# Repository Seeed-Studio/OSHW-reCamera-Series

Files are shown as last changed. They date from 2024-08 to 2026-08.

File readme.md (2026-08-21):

# Seeed Studio reCamera Hardware

English | [简体中文](README-CN.md)

reCamera Pro

This repository is the hardware documentation and design-resource hub for the
Seeed Studio reCamera product matrix:

- **reCamera 2002 / 2002w** (SG2002), a modular platform.
- **reCamera Pro** (RV1126B), a higher-performance integrated platform.

reCamera 2002 / 2002w and reCamera Pro are concurrently sold product families
for different application and performance requirements. This repository does
not describe them as replacement generations.

## Product matrix

| | reCamera 2002 / 2002w | reCamera Pro |
| --- | --- | --- |
| Processor | Sophgo SG2002 | Rockchip RV1126B |
| CPU | Dual C906 RISC-V cores | Quad-core Cortex-A53 at 1.2GHz |
| AI acceleration | 1 TOPS INT8 | 3 TOPS NPU |
| Memory | 256MB | 2GB / 4GB LPDDR4 |
| Standard camera | OV5647, 5MP | SC850SL, 8MP, 4K at 30fps |
| Hardware model | Interchangeable core, sensor, and base boards | Integrated camera with expansion interfaces |
| Documentation | [reCamera 2002 hardware](hardware/recamera-2002/) | [reCamera Pro hardware](hardware/recamera-pro/) |

### reCamera 2002 / 2002w

| Standard reCamera 2002 | reCamera 2002 HQ PoE | reCamera Gimbal 2002w |
| --- | --- | --- |
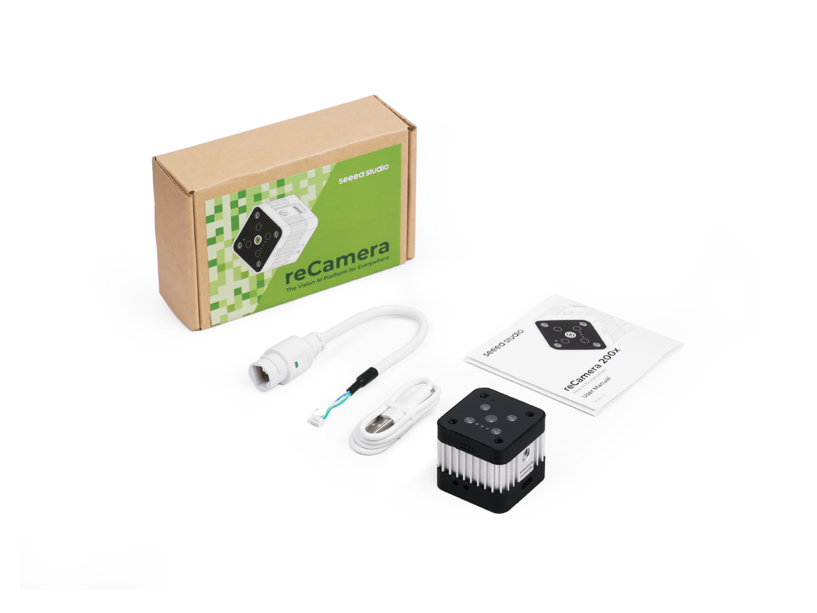
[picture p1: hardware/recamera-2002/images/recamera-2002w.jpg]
reCamera 2002w (https://www.seeedstudio.com/reCamera-2002-64GB-p-6252.html)
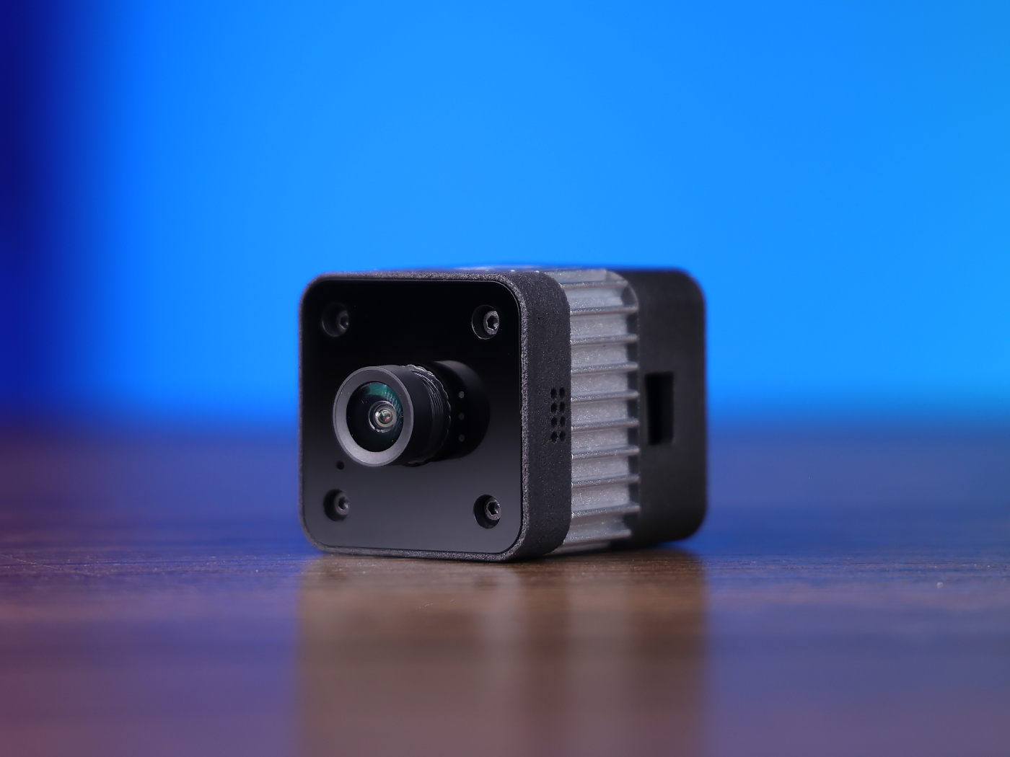
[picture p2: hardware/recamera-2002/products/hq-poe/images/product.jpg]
reCamera 2002 HQ PoE (https://www.seeedstudio.com/reCamera-2002-HQ-PoE-64GB-p-6557.html)
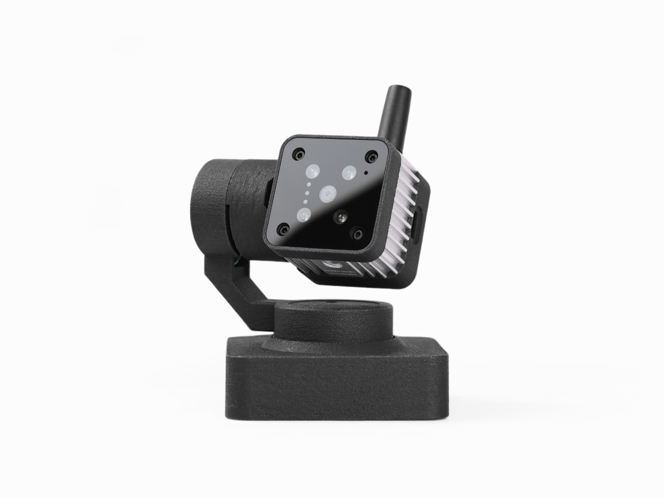
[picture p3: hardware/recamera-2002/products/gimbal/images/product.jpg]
reCamera Gimbal 2002w (https://www.seeedstudio.com/reCamera-Gimbal-2002w-64GB-p-6403.html)
|  |  |  |
| Fixed camera; B101 base | GC2053 sensor; Ethernet and PoE | Two-axis brushless gimbal; B401 CAN base |

The repository contains editable KiCad sources, schematic PDFs, mechanical
files, and revision notes for the C1 core, S-series sensor boards, B-series base
boards, and Gimbal mechanical/power hardware. See the
[reCamera 2002 / 2002w product index](hardware/recamera-2002/products/).

### reCamera Pro

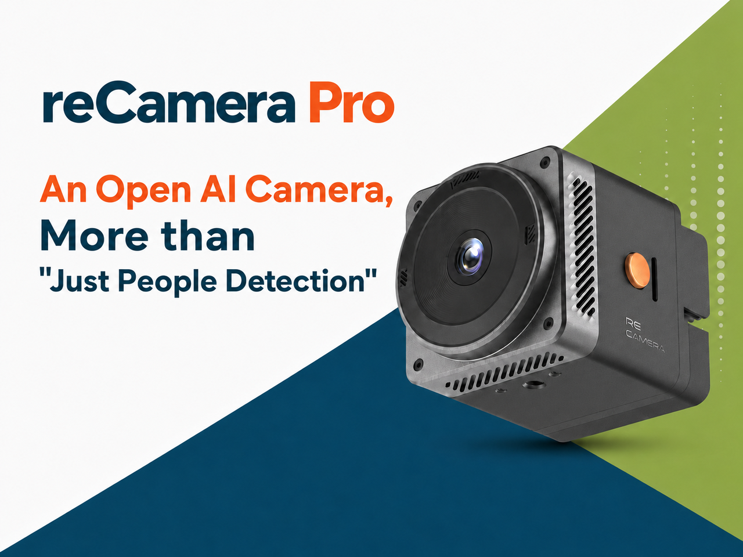
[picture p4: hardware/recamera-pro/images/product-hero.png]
reCamera Pro (https://www.seeedstudio.com/reCamera-Pro-2GB.html)


[Buy reCamera Pro 2GB from Seeed Studio](https://www.seeedstudio.com/reCamera-Pro-2GB.html)

The repository currently provides an official-specification snapshot, polished
storefront product images, and technical interface images for reCamera Pro. Editable Pro PCB and
mechanical source files should be added only when an approved hardware release
is available.

## Repository layout

```text
.
|-- hardware/
|   |-- recamera-2002/       # reCamera 2002 family board and mechanical sources
|   `-- recamera-pro/        # reCamera Pro family specifications and images
|-- docs/                    # Official sources and maintenance policy
|-- .github/workflows/       # Repository administration
|-- CONTRIBUTING.md
`-- LICENSE
```

## Scope

This is a **pure hardware repository**. 
If you need to access software-related repositories, please visit the official website.
[reCamera document](https://wiki.seeedstudio.com/recamera/)Obtain these resources from the Seeed Studio software repository.

Gimbal and HQ PoE are product forms within the reCamera 2002 family. Their
product-specific hardware is documented under `hardware/recamera-2002/products/`
and linked to shared boards.

## Source of truth

Hardware summaries are reviewed against official Seeed Studio product and Wiki
pages. See [docs/OFFICIAL_SOURCES.md](docs/OFFICIAL_SOURCES.md) for the source
list and review date. A currently shipped product page takes precedence over a
repository snapshot when specifications or available configurations change.

Contributions must follow [CONTRIBUTING.md](CONTRIBUTING.md). Unless a file says
otherwise, repository content is provided under the [Apache License 2.0](LICENSE).

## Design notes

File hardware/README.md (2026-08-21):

# Hardware index

English | [简体中文](README-CN.md)

| Product family | Processor | Product forms | Repository resources |
| --- | --- | --- | --- |
| reCamera 2002 / 2002w | SG2002 | Standard camera, HQ PoE, Gimbal | [Products, board sources, schematics, and mechanical files](recamera-2002/) |
| reCamera Pro | RV1126B | 2GB / 4GB configurations | [Specifications and official hardware images](recamera-pro/) |

The reCamera 2002 family is organized first by purchasable product form, then by
shared interchangeable core, sensor, and base boards. reCamera Pro is documented
as an integrated product because approved editable Pro design sources are not
currently stored in this repository. Both families remain part of the current
product matrix.

Repository files are revision snapshots, not an automatic statement that a
module is currently sold. Always distinguish standard shipped hardware,
optional modules, and reference/prototype designs.

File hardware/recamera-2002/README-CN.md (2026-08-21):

# reCamera 2002 / 2002w 硬件

[English](README.md) | 简体中文

reCamera 2002 / 2002w 平台由三层可互换模块组成：C1 核心板、S 系列传感器板与
B 系列底板。

reCamera 2002w

## 当前在售产品形态

| 产品形态 | 主要硬件差异 | 产品说明 |
| --- | --- | --- |
| reCamera 2002 / 2002w | 使用 S101 与 B101 的固定式摄像头 | [标准版](products/#standard-recamera-2002--2002w) |
| reCamera 2002 HQ PoE | S401 GC2053、M12 镜头、B301 以太网/PoE 底板 | [HQ PoE](products/hq-poe/) |
| reCamera Gimbal 2002w | S101、B401 CAN 底板、双轴无刷云台与电源板 | [Gimbal](products/gimbal/) |

三者都是基于 SG2002 的 reCamera 2002 系列产品形态。

## 标准固定式摄像头配置

| 产品 | 核心板 | eMMC | 无线 | 传感器 | 底板 |
| --- | --- | ---: | --- | --- | --- |
| reCamera 2002 8GB | C1-2002 | 8GB | 无 | S101 OV5647 | B101 |
| reCamera 2002 64GB | C1-2002 | 64GB | 无 | S101 OV5647 | B101 |
| reCamera 2002w 8GB | C1-2002w | 8GB | Wi-Fi / 蓝牙 | S101 OV5647 | B101 |
| reCamera 2002w 64GB | C1-2002w | 64GB | Wi-Fi / 蓝牙 | S101 OV5647 | B101 |

## 硬件资料

| 层级 | 板卡 | 状态 | 目录 |
| --- | --- | --- | --- |
| 核心板 | C1-2002 / C1-2002w | 标准出货核心板 | [core/c1-2002](core/c1-2002/) |
| 传感器 | S101 OV5647 | 标准出货传感器 | [sensors/s101-ov5647](sensors/s101-ov5647/) |
| 传感器 | S201 IMX335 | 可选/已记录模块；请确认供货 | 本仓库暂无设计文件 |
| 传感器 | S301 SC130GS | 可选/已记录模块；请确认供货 | 本仓库暂无设计文件 |
| 传感器 | S401 GC2053 | 用于 HQ/PoE 变体 | [sensors/s401-gc2053](sensors/s401-gc2053/) |
| 底板 | B101 | 标准出货底板 | [base/b101-default](base/b101-default/) |
| 底板 | B201 垂直 USB-C | 参考/原型设计 | [base/b201-vertical-usb-c](base/b201-vertical-usb-c/) |
| 底板 | B301 PoE | 参考设计；需与商用版本核对 | [base/b301-poe](base/b301-poe/) |
| 底板 | B401 CAN | 云台 CAN 底板；源文件沿用早期 B4 命名 | [base/b401-can](base/b401-can/) |

SG2002 驱动层传感器快照见 [SENSOR_COMPATIBILITY-CN.md](SENSOR_COMPATIBILITY-CN.md)。
存在驱动不代表一定有可购买模块，也不代表一定与 reCamera 板对板接口电气兼容。

## 文件约定

- `PCB/`：可编辑 KiCad 源文件和已批准的原始压缩包。
- `3D_Printed_Case/`：STEP、STL 或 3MF 机械文件。
- `static/` 或 `statics/`：板卡示意图和原理图 PDF。

用于维修或制造前，请先确认实物板卡版本。

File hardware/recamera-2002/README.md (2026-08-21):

# reCamera 2002 / 2002w hardware

English | [简体中文](README-CN.md)

The reCamera 2002 / 2002w platform is built from three interchangeable layers:
a C1 core board, an S-series sensor board, and a B-series base board.

reCamera 2002w

## Currently sold product forms

| Product form | Key hardware difference | Product documentation |
| --- | --- | --- |
| reCamera 2002 / 2002w | Fixed camera using S101 and B101 | [Standard camera](products/#standard-recamera-2002--2002w) |
| reCamera 2002 HQ PoE | S401 GC2053, M12 lens, B301 Ethernet/PoE base | [HQ PoE](products/hq-poe/) |
| reCamera Gimbal 2002w | S101, B401 CAN base, two-axis brushless gimbal and power board | [Gimbal](products/gimbal/) |

These are three product forms within the same SG2002-based reCamera 2002 family.

## Standard fixed-camera configurations

| Product | Core | eMMC | Wireless | Sensor | Base |
| --- | --- | ---: | --- | --- | --- |
| reCamera 2002 8GB | C1-2002 | 8GB | No | S101 OV5647 | B101 |
| reCamera 2002 64GB | C1-2002 | 64GB | No | S101 OV5647 | B101 |
| reCamera 2002w 8GB | C1-2002w | 8GB | Wi-Fi / Bluetooth | S101 OV5647 | B101 |
| reCamera 2002w 64GB | C1-2002w | 64GB | Wi-Fi / Bluetooth | S101 OV5647 | B101 |

## Hardware resources

| Layer | Board | Status | Directory |
| --- | --- | --- | --- |
| Core | C1-2002 / C1-2002w | Standard shipped core | [core/c1-2002](core/c1-2002/) |
| Sensor | S101 OV5647 | Standard shipped sensor | [sensors/s101-ov5647](sensors/s101-ov5647/) |
| Sensor | S201 IMX335 | Optional/documented module; verify availability | Design files not present in this repository |
| Sensor | S301 SC130GS | Optional/documented module; verify availability | Design files not present in this repository |
| Sensor | S401 GC2053 | Used by HQ/PoE variants | [sensors/s401-gc2053](sensors/s401-gc2053/) |
| Base | B101 | Standard shipped base | [base/b101-default](base/b101-default/) |
| Base | B201 vertical USB-C | Reference/prototype design | [base/b201-vertical-usb-c](base/b201-vertical-usb-c/) |
| Base | B301 PoE | Reference design; verify against commercial revision | [base/b301-poe](base/b301-poe/) |
| Base | B401 CAN | Gimbal CAN base; source files use earlier B4 naming | [base/b401-can](base/b401-can/) |

See [SENSOR_COMPATIBILITY.md](SENSOR_COMPATIBILITY.md) for the SG2002
driver-level sensor snapshot. Driver presence does not guarantee a purchasable
module or electrical compatibility with the reCamera connector.

## File conventions

- `PCB/`: editable KiCad sources and approved original archives.
- `3D_Printed_Case/`: STEP, STL, or 3MF mechanical files.
- `static/` or `statics/`: board diagrams and schematic PDFs.

Confirm the physical board revision before using these files for repair or
manufacture.

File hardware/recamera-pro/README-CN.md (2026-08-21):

# reCamera Pro 硬件

[English](README.md) | 简体中文

reCamera Pro (https://www.seeedstudio.com/reCamera-Pro-2GB.html)

[前往 Seeed Studio 购买 reCamera Pro 2GB](https://www.seeedstudio.com/reCamera-Pro-2GB.html)

reCamera Pro 是基于 Rockchip RV1126B 的高性能集成式产品系列。它不同于并行在售的
reCamera 2002 三板模块化结构，将传感、音频、网络、供电和扩展接口集成在同一摄像头平台中。

## 官方硬件规格

以 Seeed Studio Wiki 为依据，核对日期：**2026-08-11**。

| 项目 | 规格 |
| --- | --- |
| 处理器 | Rockchip RV1126B |
| CPU | 1.2GHz 四核 Arm Cortex-A53 |
| NPU | 3 TOPS，支持 INT8/INT16 混合计算 |
| 内存 | 2GB / 4GB LPDDR4 |
| 存储 | 16GB eMMC；microSD 卡槽，最大 512GB |
| 摄像头 | 8MP SC850SL，最高 4K@30fps |
| IMU | ICM-42670-P 六轴加速度计和陀螺仪 |
| 音频输入 | 驻极体麦克风 ×2 |
| 音频输出 | 8Ω 扬声器，额定功率 1W |
| 网络 | 千兆以太网、双频 Wi-Fi、蓝牙 |
| 供电 | 12–24V DC（5525 圆孔接口）、PoE、7.4V 锂电池充放电管理 |
| USB | 全功能 USB Type-C（OTG） |
| 扩展 | 调试 UART、CAN ×2、GPIO ×2、22-pin MIPI DSI |

## 硬件视图

### 商品展示

以下高清图片来自 Seeed Studio 官方商城，用于展示产品、随附硬件和外形尺寸。

| 产品与配件 | 外形尺寸 |
| --- | --- |
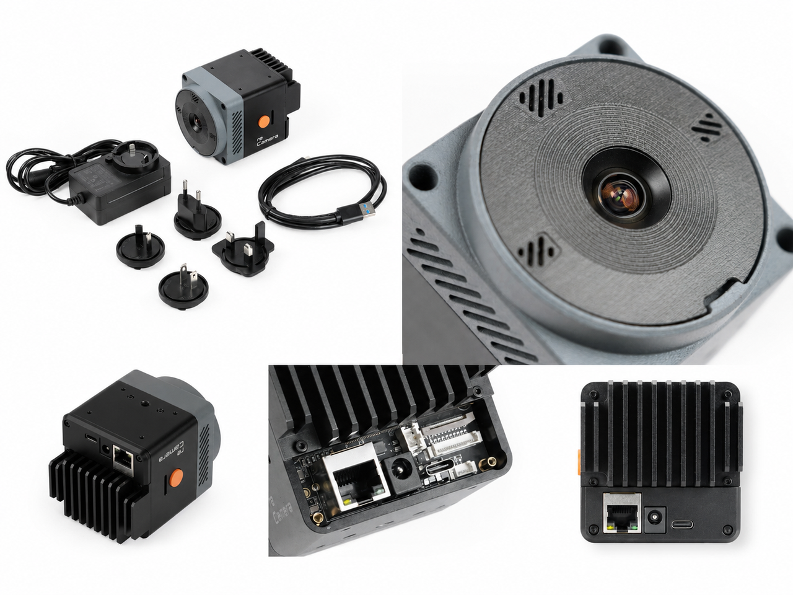
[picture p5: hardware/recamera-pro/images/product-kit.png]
reCamera Pro 产品与配件
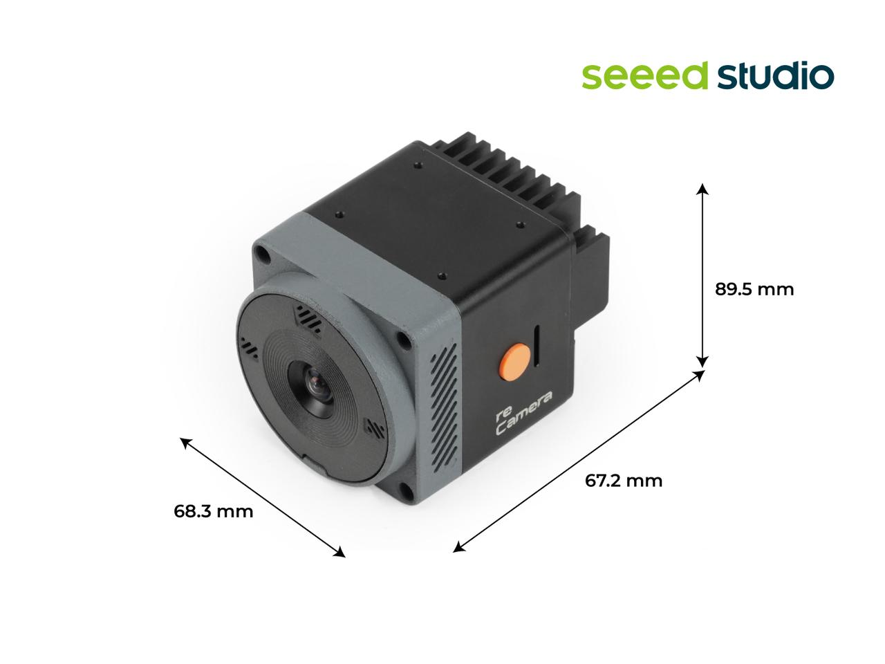
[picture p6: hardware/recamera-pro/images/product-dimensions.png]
reCamera Pro 外形尺寸
|  |  |

### 接口总览

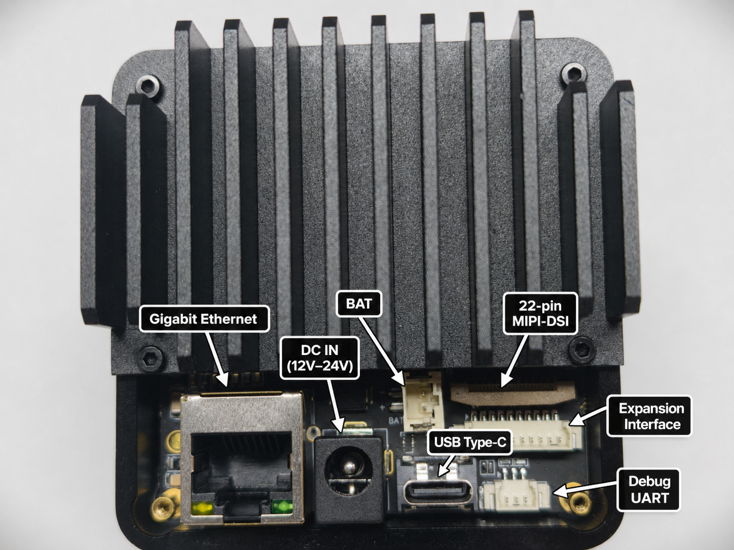
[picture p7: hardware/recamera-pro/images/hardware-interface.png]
reCamera Pro 硬件接口


### 正面与侧面

| 正面 | 侧面 |
| --- | --- |
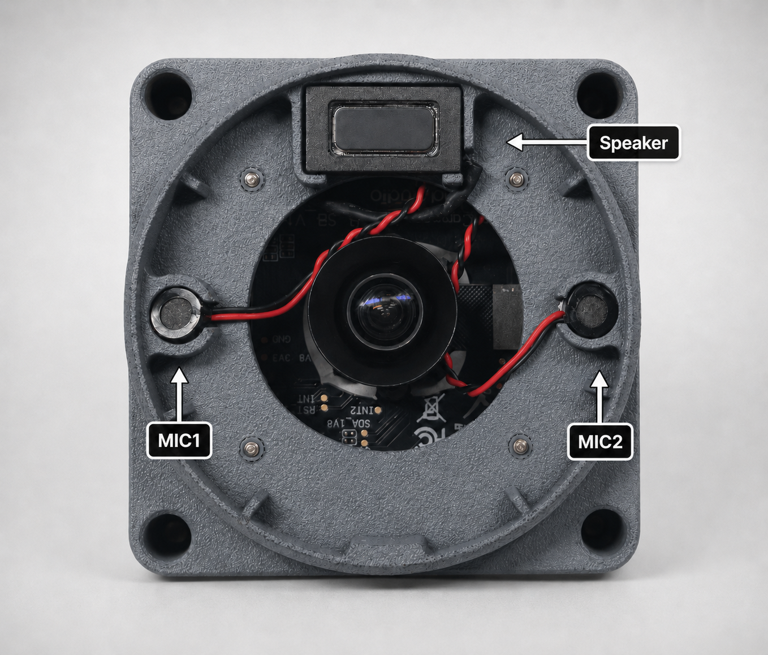
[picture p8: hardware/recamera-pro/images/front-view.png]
正面视图
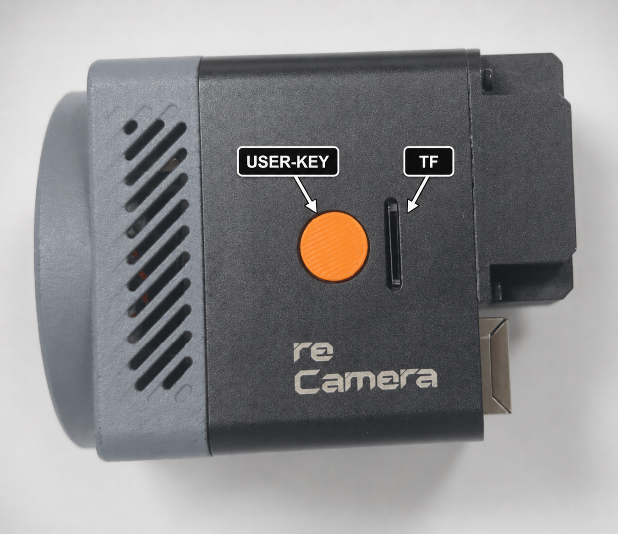
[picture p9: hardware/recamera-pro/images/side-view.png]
侧面视图
|  |  |

### 扩展接口与调试 UART

| 扩展接口 | 调试 UART |
| --- | --- |
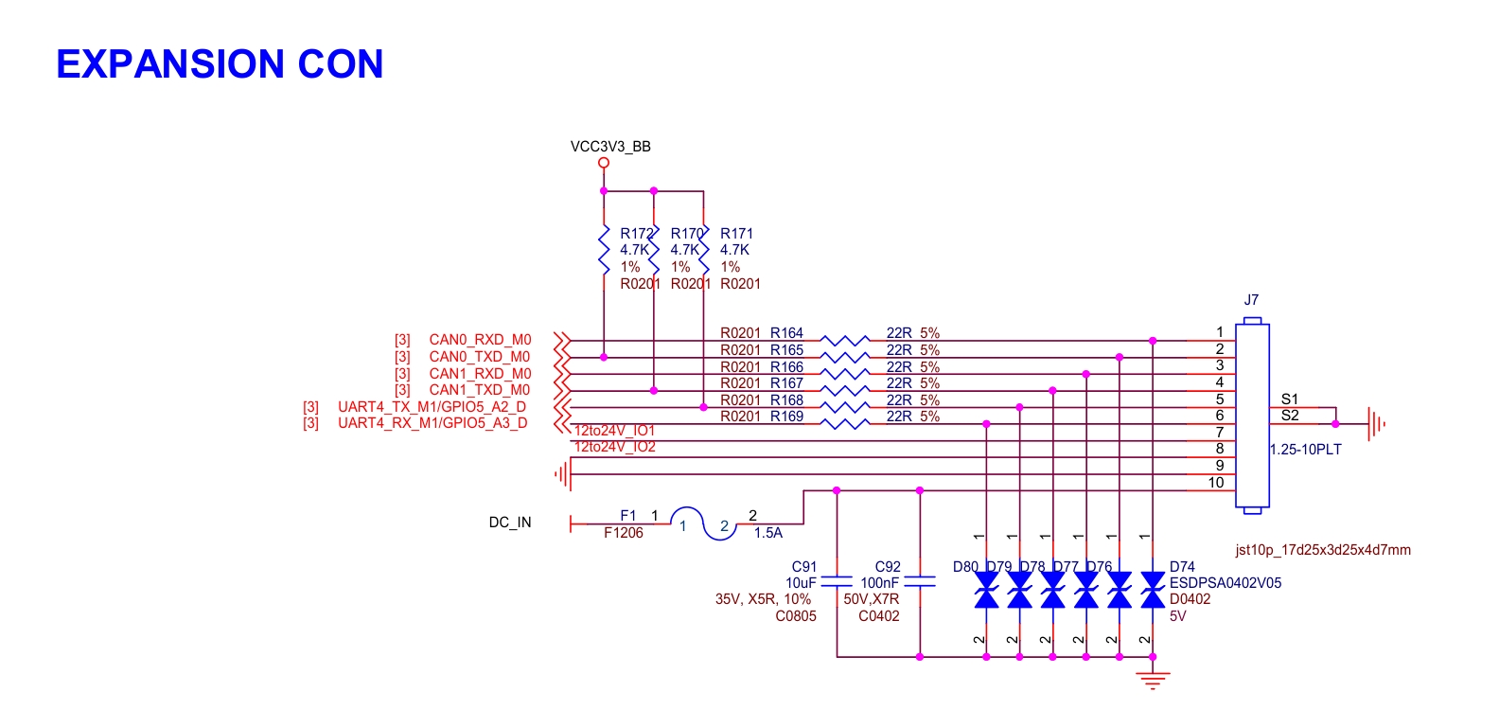
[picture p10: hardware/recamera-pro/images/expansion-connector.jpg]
扩展接口
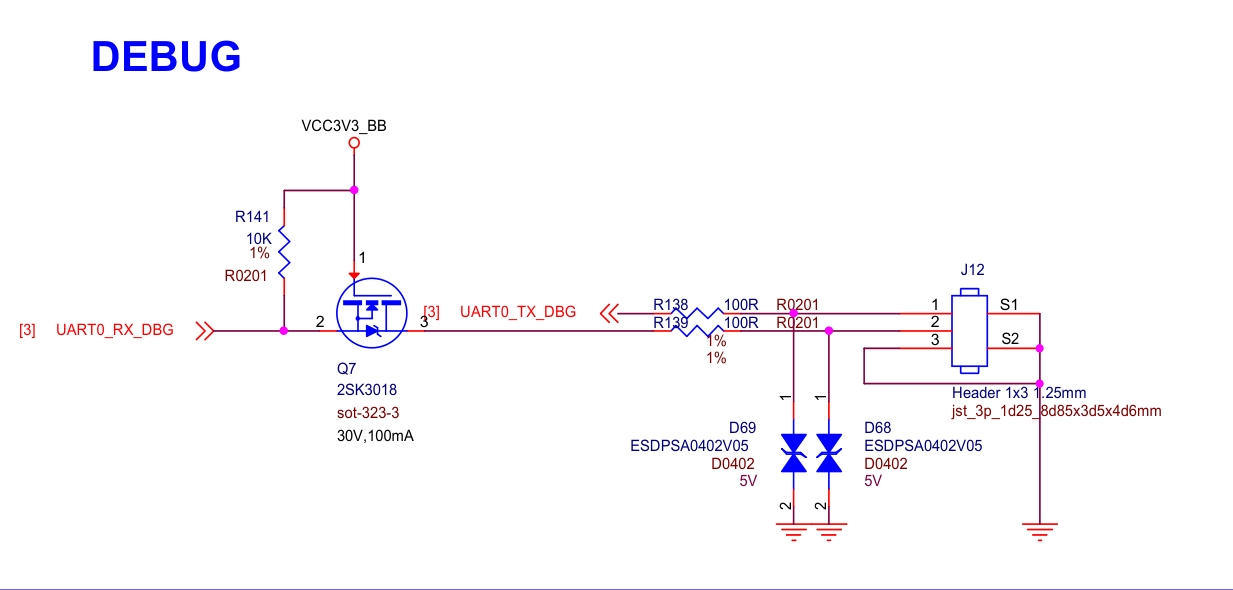
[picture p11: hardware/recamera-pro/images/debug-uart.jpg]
调试 UART
|  |  |

## 设计源文件状态

本目录当前不声称提供 reCamera Pro 可编辑 PCB、BOM 或机械源文件集。宣传图来自
Seeed Studio 官方商城，接口图来自官方文档，规格表是带日期的快照。只有在正确硬件版本获批公开后，
才应添加制造源文件。

## 官方参考

- [商品与购买页面](https://www.seeedstudio.com/reCamera-Pro-2GB.html)
- [中文硬件规格](https://wiki.seeedstudio.com/cn/recamera_pro_hardware_specifications/)
- [英文硬件规格](https://wiki.seeedstudio.com/recamera_pro_hardware_specifications/)
- [快速入门与实物连接](https://wiki.seeedstudio.com/cn/recamera_pro_getting_started/)

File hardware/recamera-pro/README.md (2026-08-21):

# reCamera Pro hardware

English | [简体中文](README-CN.md)

reCamera Pro (https://www.seeedstudio.com/reCamera-Pro-2GB.html)

[Buy reCamera Pro 2GB from Seeed Studio](https://www.seeedstudio.com/reCamera-Pro-2GB.html)

reCamera Pro is the higher-performance integrated product family based on the
Rockchip RV1126B. Unlike the three-board modular architecture of the concurrently
sold reCamera 2002 family, Pro integrates sensing, audio, networking, power, and
expansion interfaces in one camera platform.

## Official hardware specifications

Reviewed against the Seeed Studio Wiki on **2026-08-11**.

| Item | Specification |
| --- | --- |
| Processor | Rockchip RV1126B |
| CPU | Quad-core Arm Cortex-A53 at 1.2GHz |
| NPU | 3 TOPS; mixed INT8/INT16 computation |
| Memory | 2GB / 4GB LPDDR4 |
| Storage | 16GB eMMC; microSD slot up to 512GB |
| Camera | 8MP SC850SL, up to 4K at 30fps |
| IMU | ICM-42670-P six-axis accelerometer and gyroscope |
| Audio input | Two electret microphones |
| Audio output | 8Ω speaker, rated 1W |
| Networking | Gigabit Ethernet, dual-band Wi-Fi, Bluetooth |
| Power | 12–24V DC through 5525 barrel jack; PoE; 7.4V lithium-battery charge/discharge management |
| USB | Full-function USB Type-C (OTG) |
| Expansion | Debug UART, CAN ×2, GPIO ×2, 22-pin MIPI DSI |

## Hardware views

### Product gallery

The following high-resolution images come from the official Seeed Studio
storefront and present the product, supplied hardware, and physical dimensions.

| Product and accessories | Physical dimensions |
| --- | --- |
| reCamera Pro product and accessories | reCamera Pro physical dimensions |

### Interface overview

reCamera Pro hardware interface

### Front and side

| Front | Side |
| --- | --- |
| Front view | Side view |

### Expansion connector and debug UART

| Expansion connector | Debug UART |
| --- | --- |
| Expansion connector | Debug UART |

## Design-source status

This directory does not currently claim to provide the editable PCB, BOM, or
mechanical source set for reCamera Pro. Promotional images come from the official
storefront, interface images come from official documentation, and the table is
a dated specification snapshot. Add
manufacturing sources only after the correct hardware revision is approved for
public release.

## Official references

- [Product and ordering page](https://www.seeedstudio.com/reCamera-Pro-2GB.html)
- [Hardware specifications](https://wiki.seeedstudio.com/recamera_pro_hardware_specifications/)
- [Quick start and physical connection](https://wiki.seeedstudio.com/recamera_pro_getting_started/)
- [Chinese hardware specifications](https://wiki.seeedstudio.com/cn/recamera_pro_hardware_specifications/)

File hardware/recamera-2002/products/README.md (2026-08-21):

# reCamera 2002 / 2002w products

English | [简体中文](README-CN.md)

The SG2002-based reCamera 2002 / 2002w family is sold in three main hardware
forms. They share the same modular platform but combine different sensor, base,
and motion hardware.

| Product | Camera hardware | Connectivity / motion | Hardware resources |
| --- | --- | --- | --- |
| Standard reCamera 2002 / 2002w | S101 OV5647, 5MP | B101; optional Wi-Fi/Bluetooth through the 2002w core | [C1 core](../core/c1-2002/), [S101](../sensors/s101-ov5647/), [B101](../base/b101-default/) |
| reCamera 2002 HQ PoE | S401 GC2053, 2MP, M12 lens | B301, 100Mbps Ethernet and 802.3af PoE Mode A | [Product page](hq-poe/) |
| reCamera Gimbal 2002w | S101 OV5647, 5MP | B401 CAN, 360° yaw and 180° pitch | [Product page](gimbal/) |

## Standard reCamera 2002 / 2002w

Standard reCamera 2002 (https://www.seeedstudio.com/reCamera-2002-64GB-p-6252.html)

The standard fixed-camera form uses the three-board C1 + S101 + B101 stack.
The `2002w` core adds dual-band Wi-Fi and Bluetooth; storage configurations vary
by the currently selected storefront SKU.

[View the official product page](https://www.seeedstudio.com/reCamera-2002-64GB-p-6252.html)

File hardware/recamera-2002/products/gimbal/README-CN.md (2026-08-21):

# reCamera Gimbal 2002w 硬件

[English](README.md) | 简体中文

reCamera Gimbal 2002w (https://www.seeedstudio.com/reCamera-Gimbal-2002w-64GB-p-6403.html)

Gimbal 是 reCamera 2002w 系列的运动云台形态。双无刷电机提供 360° 水平
旋转与 180° 俯仰，B401 底板通过 CAN 连接摄像头与电机系统。

| 项目 | 硬件 |
| --- | --- |
| 摄像头堆叠 | [C1-2002w](../../core/c1-2002/) + [S101 OV5647](../../sensors/s101-ov5647/) |
| 云台底板 | [B401 CAN](../../base/b401-can/) |
| 电机接口 | CAN；官方规格列出最高 1Mbps |
| 运动范围 | 水平 360°、俯仰 180° |
| 供电 | 12V DC 经专用电源板连接 XT30 |
| 机械源文件 | [STEP/3MF 文件](mechanical/) |
| 电源板源文件 | [KiCad 与原理图](power-board/PCB/) |

这里只保留硬件设计资料。电机工具、可执行文件、固件、Node-RED 流程和控制
示例不属于本仓库范围。

- [购买 reCamera Gimbal 2002w](https://www.seeedstudio.com/reCamera-Gimbal-2002w-64GB-p-6403.html)
- [官方硬件 Wiki](https://wiki.seeedstudio.com/recamera_gimbal_hardware_and_specs/)

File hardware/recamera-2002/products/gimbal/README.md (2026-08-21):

# reCamera Gimbal 2002w hardware

English | [简体中文](README-CN.md)

reCamera Gimbal 2002w (https://www.seeedstudio.com/reCamera-Gimbal-2002w-64GB-p-6403.html)

Gimbal is the motion-enabled form of the reCamera 2002w family. Its
two brushless motors provide 360° yaw and 180° pitch, while the B401 base board
uses CAN to connect the camera and motor system.

| Item | Hardware |
| --- | --- |
| Camera stack | [C1-2002w](../../core/c1-2002/) + [S101 OV5647](../../sensors/s101-ov5647/) |
| Gimbal base | [B401 CAN](../../base/b401-can/) |
| Motor interface | CAN; official specification lists up to 1Mbps |
| Motion | 360° yaw, 180° pitch |
| Power | 12V DC jack to XT30 through the dedicated power board |
| Mechanical source | [STEP/3MF files](mechanical/) |
| Power-board source | [KiCad and schematic files](power-board/PCB/) |

Only hardware design resources are stored here. Motor utilities, binaries,
firmware, Node-RED flows, and control examples remain outside this repository's
scope.

- [Buy reCamera Gimbal 2002w](https://www.seeedstudio.com/reCamera-Gimbal-2002w-64GB-p-6403.html)
- [Official hardware Wiki](https://wiki.seeedstudio.com/recamera_gimbal_hardware_and_specs/)

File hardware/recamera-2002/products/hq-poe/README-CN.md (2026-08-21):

# reCamera 2002 HQ PoE 硬件

[English](README.md) | 简体中文

reCamera 2002 HQ PoE (https://www.seeedstudio.com/reCamera-2002-HQ-PoE-64GB-p-6557.html)

HQ PoE 是 reCamera 2002 系列面向网络部署的固定式产品，由 SG2002
核心板、S401 GC2053 传感器板与 B301 PoE 底板组成。

| 项目 | 硬件 |
| --- | --- |
| SoC / 内存 | SG2002，256MB |
| 传感器 | GC2053，1/2.9 英寸 CMOS，1920×1080@30fps |
| 镜头 | 可更换 M12；官方默认视场角约 90° |
| 底板 | [B301 PoE](../../base/b301-poe/) |
| 传感器板 | [S401 GC2053](../../sensors/s401-gc2053/) |
| 网络/供电 | 100Mbps 以太网；802.3af PoE Mode A |
| 扩展 | 六针接口提供 UART、调试接口和三个 GPIO |

商城当前列出 64GB 配置，实际供货与所选存储容量应以商品页为准。

- [购买 reCamera 2002 HQ PoE](https://www.seeedstudio.com/reCamera-2002-HQ-PoE-64GB-p-6557.html)
- [官方中文硬件 Wiki](https://wiki.seeedstudio.com/cn/reCamera_hq_poe_hardware_and_specs/)

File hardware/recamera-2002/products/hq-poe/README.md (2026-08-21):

# reCamera 2002 HQ PoE hardware

English | [简体中文](README-CN.md)

reCamera 2002 HQ PoE (https://www.seeedstudio.com/reCamera-2002-HQ-PoE-64GB-p-6557.html)

HQ PoE is the network-oriented fixed-camera form of the reCamera 2002 family.
It combines the SG2002 core with the S401 GC2053 sensor
board and B301 PoE base.

| Item | Hardware |
| --- | --- |
| SoC / memory | SG2002, 256MB |
| Sensor | GC2053, 1/2.9-inch CMOS, 1920×1080 at 30fps |
| Lens | Replaceable M12; official default FOV approximately 90° |
| Base | [B301 PoE](../../base/b301-poe/) |
| Sensor board | [S401 GC2053](../../sensors/s401-gc2053/) |
| Network / power | 100Mbps Ethernet; 802.3af PoE Mode A |
| Expansion | UART, debug, and three GPIOs through the six-pin connector |

The commercial product page currently lists a 64GB configuration. Availability
and selected storage should always be verified on the storefront.

- [Buy reCamera 2002 HQ PoE](https://www.seeedstudio.com/reCamera-2002-HQ-PoE-64GB-p-6557.html)
- [Official hardware Wiki](https://wiki.seeedstudio.com/recamera_hq_poe_hardware_and_specs/)

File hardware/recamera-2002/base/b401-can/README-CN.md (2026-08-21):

# B401 CAN 底板

[English](README.md) | 简体中文

B401 是 reCamera Gimbal 2002w 使用的 CAN 底板。恢复的设计文件仍沿用历史上的
`B4` 和 `B101_B4_Gyro` 文件名；这些是早期设计命名，当前 Seeed 文档将商用板称为 B401。

| 目录 | 内容 |
| --- | --- |
| `PCB/B4_v0.1/` | 早期 KiCad 设计快照 |
| `PCB/B4_v0.2/` | 后续 KiCad 设计与原理图 PDF |
| `3D_Printed_Case/` | STEP/STL 底板外壳文件 |
| `static/` | 板卡与原理图预览 |

用于制造前，请将 PCB 版本与实际产品核对。

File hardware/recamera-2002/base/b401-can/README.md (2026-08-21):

# B401 CAN base board

English | [简体中文](README-CN.md)

B401 is the CAN-enabled base board used by reCamera Gimbal 2002w. The restored
design files retain historical `B4` and `B101_B4_Gyro` filenames; these names
refer to earlier design naming, while current Seeed documentation calls the
commercial board B401.

| Directory | Contents |
| --- | --- |
| `PCB/B4_v0.1/` | Early KiCad design snapshot |
| `PCB/B4_v0.2/` | Later KiCad design and schematic PDF |
| `3D_Printed_Case/` | STEP/STL base enclosure files |
| `static/` | Board and schematic previews |

Verify the PCB revision against the physical product before manufacturing.

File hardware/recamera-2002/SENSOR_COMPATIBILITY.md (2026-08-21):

# SG2002 sensor-driver compatibility

This is a driver-level snapshot for the C1 SG2002 core board. It does not mean
that every sensor is electrically compatible with the reCamera board-to-board
connector or available as a finished Seeed module.

Last repository review: **2026-08-04**

| Vendor group | Supported driver identifiers |
| --- | --- |
| GalaxyCore / IMGDS / Nextchip / PICO / SOI | `gcore_gc2053`, `gcore_gc2053_slave`, `gcore_gc2053_1L`, `gcore_gc2083`, `gcore_gc2093`, `gcore_gc2093_slave`, `gcore_gc4653`, `gcore_gc4653_slave`, `gcore_gc2145`, `gcore_gc4023`, `gcore_gc1054`, `imgds_mis2008`, `nextchip_n5`, `nextchip_n6`, `pico_384`, `pico_640`, `soi_f23`, `soi_f35`, `soi_f35_slave`, `soi_h65`, `soi_f37p`, `soi_k06`, `soi_q03`, `soi_q03p` |
| OmniVision / Pixelplus / Techpoint / Lontium | `ov_os02d10`, `ov_os02d10_slave`, `ov_os02k10_slave`, `ov_os04c10`, `ov_os04c10_slave`, `ov_os08a20`, `ov_os08a20_slave`, `ov_os04a10`, `ov_ov4689`, `ov_ov5647`, `ov_ov7251`, `pixelplus_pr2020`, `pixelplus_pr2100`, `techpoint_tp2850`, `techpoint_tp2863`, `techpoint_tp2825`, `lontium_lt6911` |
| Sony | `sony_imx290_2L`, `sony_imx307`, `sony_imx307_slave`, `sony_imx307_2L`, `sony_imx307_sublvds`, `sony_imx327`, `sony_imx327_slave`, `sony_imx327_2L`, `sony_imx327_sublvds`, `sony_imx334`, `sony_imx335`, `sony_imx347`, `sony_imx385`, `sony_imx327_fpga` |
| SmartSens | `sms_sc035hgs`, `sms_sc200ai`, `sms_sc401ai`, `sms_sc850sl`, `sms_sc3335`, `sms_sc3335_slave`, `sms_sc3336`, `sms_sc4210`, `sms_sc8238`, `sms_sc5336_2L`, `sms_sc501ai_2L`, `sms_sc301iot`, `sms_sc500ai`, `sms_sc035gs`, `sms_sc035gs_1L`, `sms_sc1346_1L`, `sms_sc1346_1L_slave`, `sms_sc2331_1L`, `sms_sc2335`, `sms_sc2336`, `sms_sc2336p`, `sms_sc4336`, `sms_sc4336p`, `sms_sc3332` |

The standard Basic product ships with the **S101 OV5647** module. This
repository also contains module-level material for GC2053.
For the current kernel configuration and driver source, consult the maintained
[reCamera-OS repository](https://github.com/Seeed-Studio/reCamera-OS).

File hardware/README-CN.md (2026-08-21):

# 硬件索引

[English](README.md) | 简体中文

| 产品系列 | 处理器 | 产品形态 | 仓库资料 |
| --- | --- | --- | --- |
| reCamera 2002 / 2002w | SG2002 | 标准版、HQ PoE、Gimbal | [产品形态、板卡源文件、原理图和机械文件](recamera-2002/) |
| reCamera Pro | RV1126B | 2GB / 4GB 配置 | [硬件规格和官方图片](recamera-pro/) |

reCamera 2002 系列先按可购买的产品形态展示，再按共用的可互换核心板、传感器板和
底板组织。reCamera Pro 按集成式产品记录，因为本仓库当前没有已批准可公开的 Pro
可编辑设计源文件。两个系列都是当前产品矩阵的一部分。

仓库中的文件是特定版本快照，不等于模块当前一定在售。必须明确区分标准出货硬件、
可选模块和参考/原型设计。

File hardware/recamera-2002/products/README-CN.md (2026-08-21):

# reCamera 2002 / 2002w 产品形态

[English](README.md) | 简体中文

基于 SG2002 的 reCamera 2002 / 2002w 系列目前以三种主要硬件形态销售。
它们共用模块化平台，但采用不同的传感器、底板和运动机构。

| 产品 | 摄像头硬件 | 连接/运动 | 硬件资料 |
| --- | --- | --- | --- |
| 标准版 reCamera 2002 / 2002w | S101 OV5647，5MP | B101；2002w 核心板提供 Wi-Fi/蓝牙 | [C1 核心板](../core/c1-2002/)、[S101](../sensors/s101-ov5647/)、[B101](../base/b101-default/) |
| reCamera 2002 HQ PoE | S401 GC2053，2MP，M12 镜头 | B301，100Mbps 以太网与 802.3af PoE Mode A | [产品说明](hq-poe/) |
| reCamera Gimbal 2002w | S101 OV5647，5MP | B401 CAN，360° 水平旋转、180° 俯仰 | [产品说明](gimbal/) |

## 标准版 reCamera 2002 / 2002w

标准版 reCamera 2002 (https://www.seeedstudio.com/reCamera-2002-64GB-p-6252.html)

标准固定式产品采用 C1 + S101 + B101 三板堆叠结构。`2002w` 核心板增加
双频 Wi-Fi 与蓝牙；存储容量以商城当前选择的 SKU 为准。

[查看官方商品页](https://www.seeedstudio.com/reCamera-2002-64GB-p-6252.html)

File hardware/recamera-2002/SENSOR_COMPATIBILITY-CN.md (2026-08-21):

# SG2002 传感器驱动兼容性

[English](SENSOR_COMPATIBILITY.md) | 简体中文

本页是 C1 SG2002 核心板的驱动层兼容性快照。列出驱动并不表示对应传感器与 reCamera 板对板连接器在电气上兼容，也不表示 Seeed 已提供相应成品模块。

仓库最后核对日期：**2026-08-04**

| 厂商类别 | 支持的驱动标识符 |
| --- | --- |
| GalaxyCore / IMGDS / Nextchip / PICO / SOI | `gcore_gc2053`、`gcore_gc2053_slave`、`gcore_gc2053_1L`、`gcore_gc2083`、`gcore_gc2093`、`gcore_gc2093_slave`、`gcore_gc4653`、`gcore_gc4653_slave`、`gcore_gc2145`、`gcore_gc4023`、`gcore_gc1054`、`imgds_mis2008`、`nextchip_n5`、`nextchip_n6`、`pico_384`、`pico_640`、`soi_f23`、`soi_f35`、`soi_f35_slave`、`soi_h65`、`soi_f37p`、`soi_k06`、`soi_q03`、`soi_q03p` |
| OmniVision / Pixelplus / Techpoint / Lontium | `ov_os02d10`、`ov_os02d10_slave`、`ov_os02k10_slave`、`ov_os04c10`、`ov_os04c10_slave`、`ov_os08a20`、`ov_os08a20_slave`、`ov_os04a10`、`ov_ov4689`、`ov_ov5647`、`ov_ov7251`、`pixelplus_pr2020`、`pixelplus_pr2100`、`techpoint_tp2850`、`techpoint_tp2863`、`techpoint_tp2825`、`lontium_lt6911` |
| Sony | `sony_imx290_2L`、`sony_imx307`、`sony_imx307_slave`、`sony_imx307_2L`、`sony_imx307_sublvds`、`sony_imx327`、`sony_imx327_slave`、`sony_imx327_2L`、`sony_imx327_sublvds`、`sony_imx334`、`sony_imx335`、`sony_imx347`、`sony_imx385`、`sony_imx327_fpga` |
| SmartSens | `sms_sc035hgs`、`sms_sc200ai`、`sms_sc401ai`、`sms_sc850sl`、`sms_sc3335`、`sms_sc3335_slave`、`sms_sc3336`、`sms_sc4210`、`sms_sc8238`、`sms_sc5336_2L`、`sms_sc501ai_2L`、`sms_sc301iot`、`sms_sc500ai`、`sms_sc035gs`、`sms_sc035gs_1L`、`sms_sc1346_1L`、`sms_sc1346_1L_slave`、`sms_sc2331_1L`、`sms_sc2335`、`sms_sc2336`、`sms_sc2336p`、`sms_sc4336`、`sms_sc4336p`、`sms_sc3332` |

标准基础版产品随附 **S101 OV5647** 模块。本仓库还提供 GC2053 的模块级资料。当前内核配置和驱动源码请以持续维护的 [reCamera-OS 仓库](https://github.com/Seeed-Studio/reCamera-OS)为准。

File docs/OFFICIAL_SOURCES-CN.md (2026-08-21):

# 官方硬件信息源与维护策略

[English](OFFICIAL_SOURCES.md) | 简体中文

最后核对日期：**2026-08-11**

| 主题 | 权威来源 |
| --- | --- |
| reCamera 产品系列和配置 | [Seeed reCamera 产品选择器](https://www.seeedstudio.com/recamera) |
| reCamera 2002 硬件文档 | [官方 reCamera 2002 Series Wiki](https://wiki.seeedstudio.com/recamera_2002_series/) |
| reCamera 2002 开源硬件历史 | [OSHW-reCamera-Series](https://github.com/Seeed-Studio/OSHW-reCamera-Series) |
| reCamera 2002 标准固定式产品 | [官方 reCamera 2002 64GB 商品页](https://www.seeedstudio.com/reCamera-2002-64GB-p-6252.html) |
| reCamera 2002 HQ PoE | [官方 HQ PoE 商品页](https://www.seeedstudio.com/reCamera-2002-HQ-PoE-64GB-p-6557.html)与[中文硬件 Wiki](https://wiki.seeedstudio.com/cn/reCamera_hq_poe_hardware_and_specs/) |
| reCamera Gimbal 2002w | [官方 Gimbal 商品页](https://www.seeedstudio.com/reCamera-Gimbal-2002w-64GB-p-6403.html)与[硬件 Wiki](https://wiki.seeedstudio.com/recamera_gimbal_hardware_and_specs/) |
| reCamera Pro 硬件规格 | [官方中文 Pro 硬件 Wiki](https://wiki.seeedstudio.com/cn/recamera_pro_hardware_specifications/) |
| reCamera Pro 英文硬件规格 | [官方英文 Pro 硬件 Wiki](https://wiki.seeedstudio.com/recamera_pro_hardware_specifications/) |
| reCamera Pro 商品、购买入口和宣传图 | [官方 reCamera Pro 2GB 商品页](https://www.seeedstudio.com/reCamera-Pro-2GB.html) |
| reCamera Pro 实物连接和接口图 | [官方 Pro 快速入门](https://wiki.seeedstudio.com/recamera_pro_getting_started/) |

## 维护规则

- 保持本仓库为纯硬件仓库。软件资源只提供链接，不复制固件、模型、数据集、
  应用示例或 Node-RED 流程。
- 硬件先按 `recamera-2002` 和 `recamera-pro` 分类，只有确实存在模块化结构时才继续按板卡/模块细分。
- 规格变更必须记录官方来源 URL 和核对日期。
- 可编辑制造文件必须标明准确硬件版本，并区分出货产品、原型和参考设计。
- 官方产品页优先于本仓库中带日期的快照。
- 可在本地保留 Seeed 官方图片以保证硬件文档稳定，但必须在最近的 README 保留来源链接。

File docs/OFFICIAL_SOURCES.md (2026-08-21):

# Official hardware sources and maintenance policy

English | [简体中文](OFFICIAL_SOURCES-CN.md)

Last reviewed: **2026-08-11**

| Topic | Authoritative source |
| --- | --- |
| reCamera product families and configurations | [Seeed reCamera product selector](https://www.seeedstudio.com/recamera) |
| reCamera 2002 hardware documentation | [Official reCamera 2002 Series Wiki](https://wiki.seeedstudio.com/recamera_2002_series/)  |
| reCamera 2002 open-hardware history | [OSHW-reCamera-Series](https://github.com/Seeed-Studio/OSHW-reCamera-Series) |
| reCamera 2002 fixed-camera product | [Official reCamera 2002 64GB product page](https://www.seeedstudio.com/reCamera-2002-64GB-p-6252.html) |
| reCamera 2002 HQ PoE product | [Official HQ PoE product page](https://www.seeedstudio.com/reCamera-2002-HQ-PoE-64GB-p-6557.html) and [hardware Wiki](https://wiki.seeedstudio.com/recamera_hq_poe_hardware_and_specs/) |
| reCamera Gimbal 2002w product | [Official Gimbal product page](https://www.seeedstudio.com/reCamera-Gimbal-2002w-64GB-p-6403.html) and [hardware Wiki](https://wiki.seeedstudio.com/recamera_gimbal_hardware_and_specs/) |
| reCamera Pro hardware specification | [Official Pro hardware Wiki](https://wiki.seeedstudio.com/recamera_pro_hardware_specifications/) |
| reCamera Pro Chinese hardware specification | [Official Chinese Pro hardware Wiki](https://wiki.seeedstudio.com/cn/recamera_pro_hardware_specifications/) |
| reCamera Pro product, ordering, and promotional images | [Official reCamera Pro 2GB product page](https://www.seeedstudio.com/reCamera-Pro-2GB.html) |
| reCamera Pro physical connection and interface images | [Official Pro quick start](https://wiki.seeedstudio.com/recamera_pro_getting_started/) |

## Maintenance rules

- Keep this repository hardware-only. Link to software resources; do not copy
  firmware, models, datasets, application examples, or Node-RED flows here.
- Organize hardware by `recamera-2002` and `recamera-pro`, then by board/module
  only where that modular structure exists.
- Record the source URL and review date for specification changes.
- Mark editable manufacturing files with their exact hardware revision and
  distinguish shipped products from prototypes and reference designs.
- Official product pages take precedence over this dated repository snapshot.
- Official Seeed images may be stored locally for stable hardware documentation;
  preserve a source link in the nearest README.

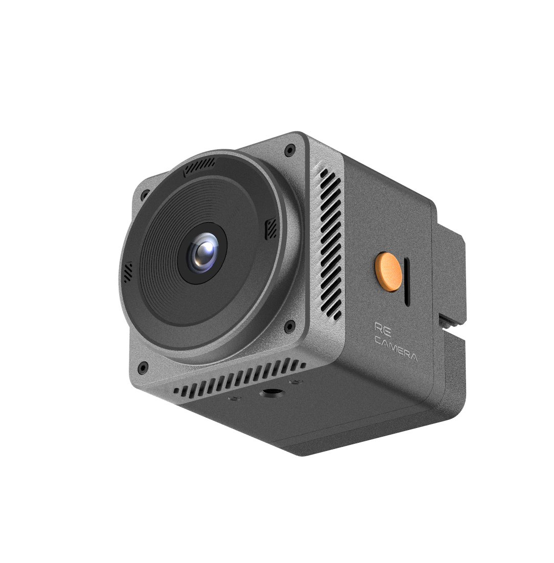
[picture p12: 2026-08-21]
hardware/recamera-pro/images/recamera-pro.png

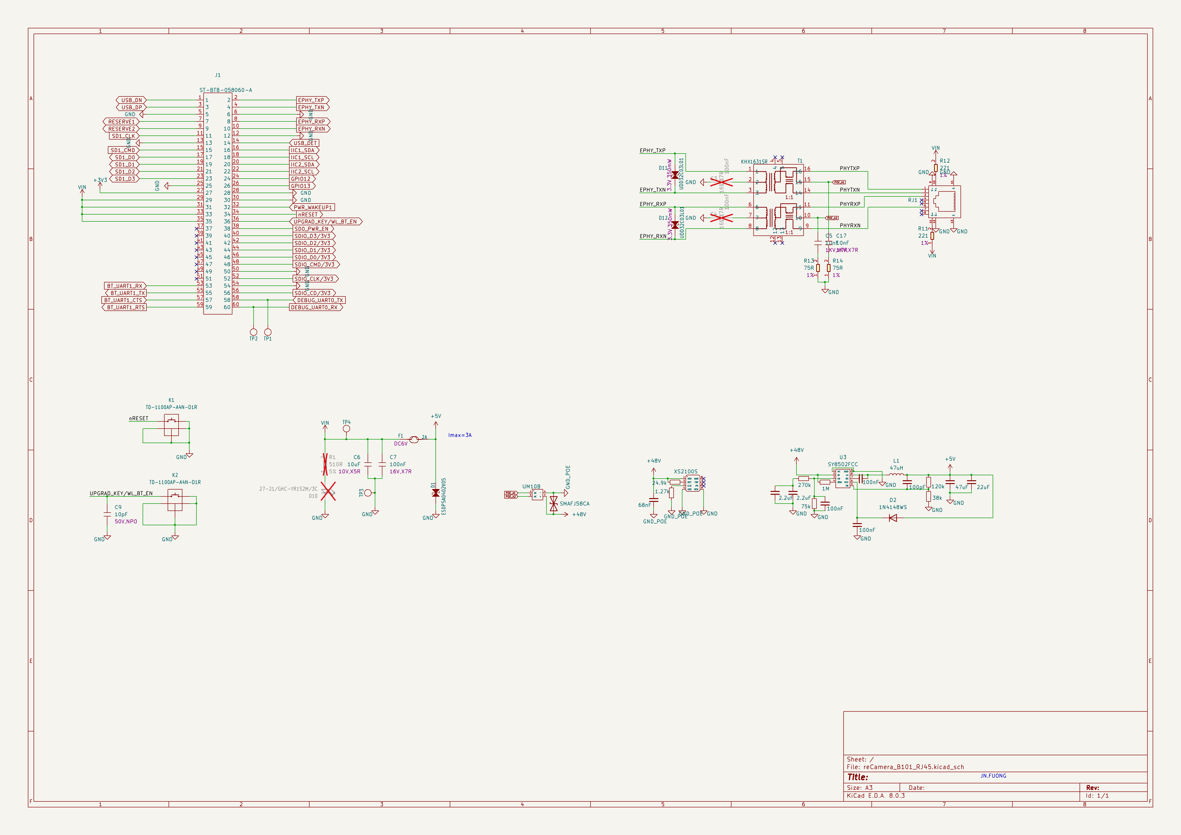
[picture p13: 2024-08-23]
statics/企业微信截图_17243809714874.png

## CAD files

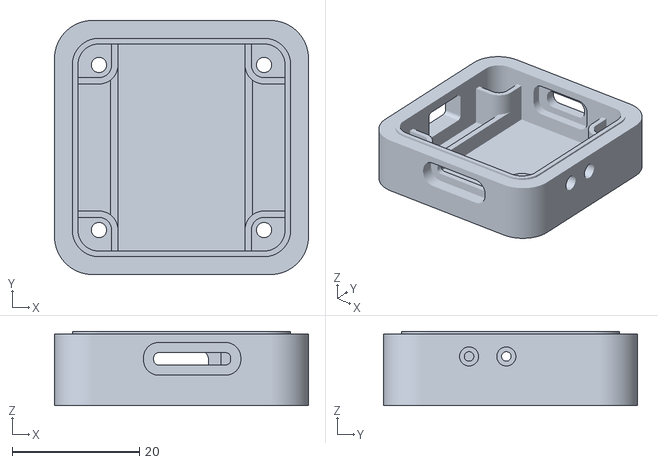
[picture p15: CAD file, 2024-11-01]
hardware/recamera-2002/base/b101-default/3D_Printed_Case/recamera-B1_Default.stl
40.0 x 40.0 x 11.7

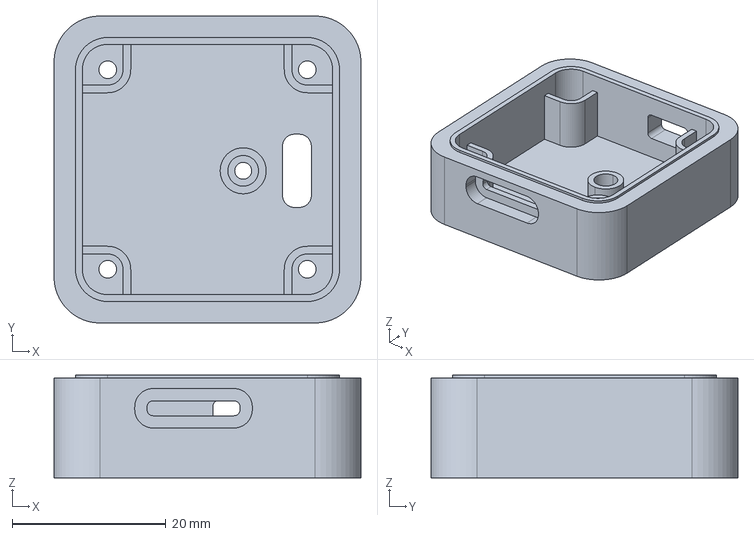
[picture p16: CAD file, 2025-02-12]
hardware/recamera-2002/base/b201-vertical-usb-c/3D_Printed_Case/B2_Vertical_Type-C.stp
40.0 x 40.0 x 13.4 mm

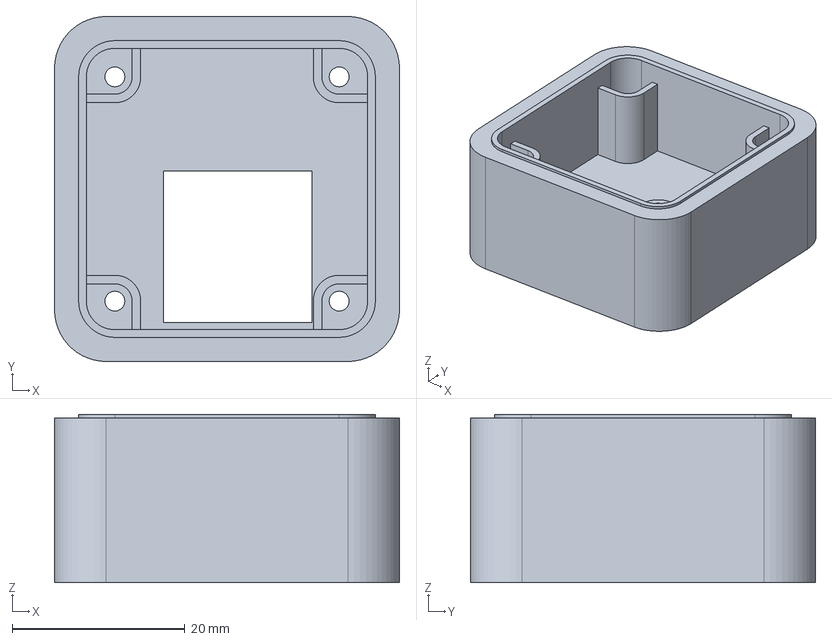
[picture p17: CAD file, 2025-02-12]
hardware/recamera-2002/base/b301-poe/3D_Printed_Case/B3_POE.stp
40.0 x 40.0 x 19.5 mm

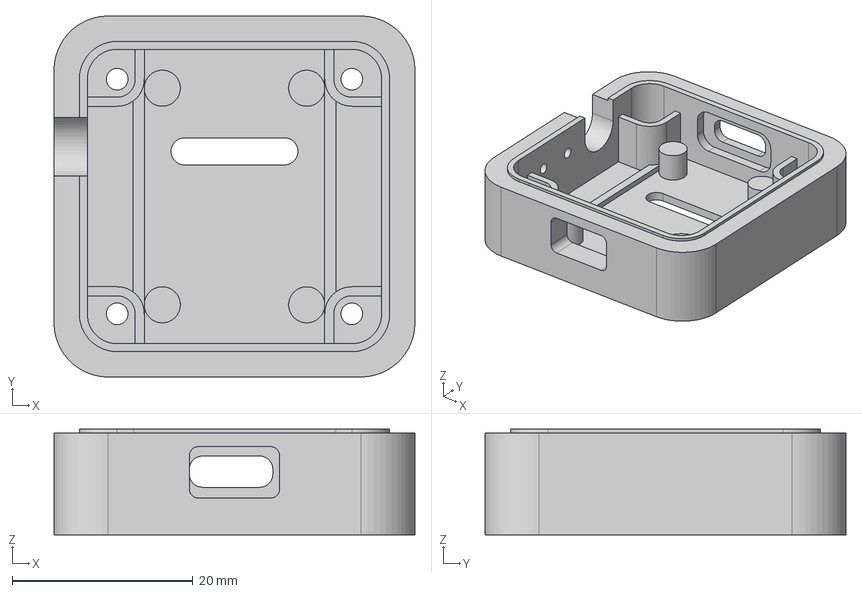
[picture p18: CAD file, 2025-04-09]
hardware/recamera-2002/base/b401-can/3D_Printed_Case/B3_CAN.step
40.0 x 40.0 x 11.7 mm

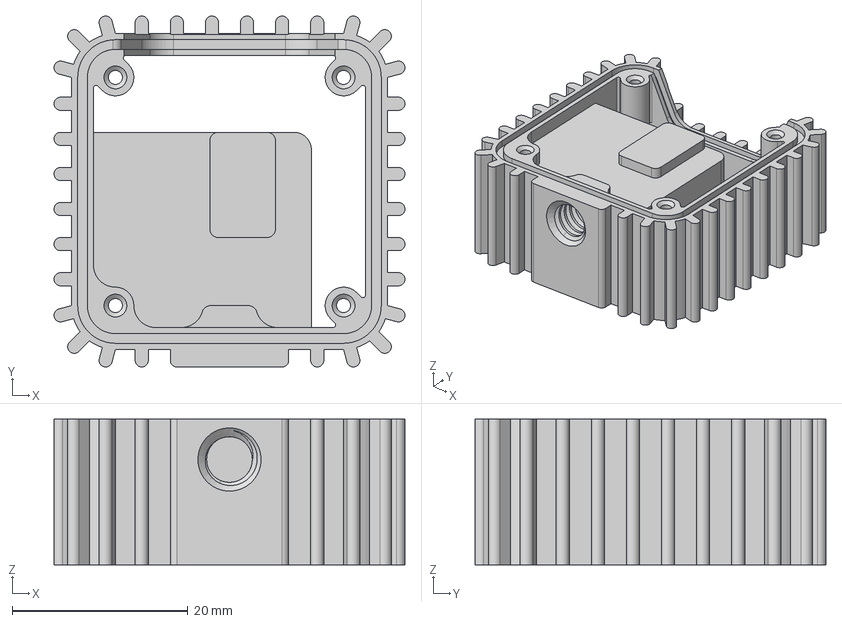
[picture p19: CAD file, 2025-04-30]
hardware/recamera-2002/core/c1-2002/3D_Printed_Case/core_cooler.step
40.0 x 40.0 x 16.6 mm

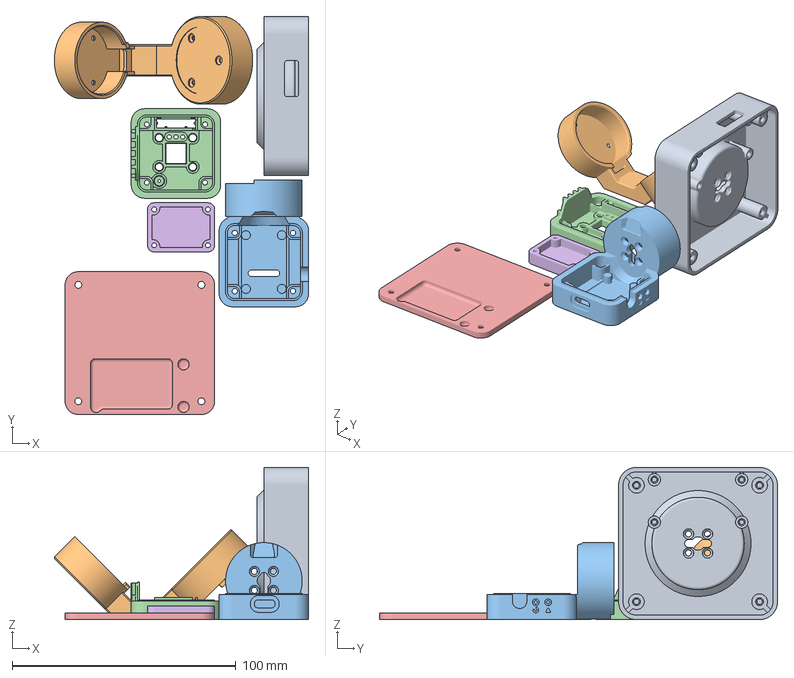
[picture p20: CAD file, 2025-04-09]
hardware/recamera-2002/products/gimbal/mechanical/platform-gimbal.3mf
113.6 x 177.8 x 68.0 mm
platform-box_29.stp
recamera-yantai_arm_30.stp
recamera-gimbalcover-4040_20.stp
recamera-sensorcover-4040-1_36.stp
bottom-plate_10.stp
can-case_3.stp

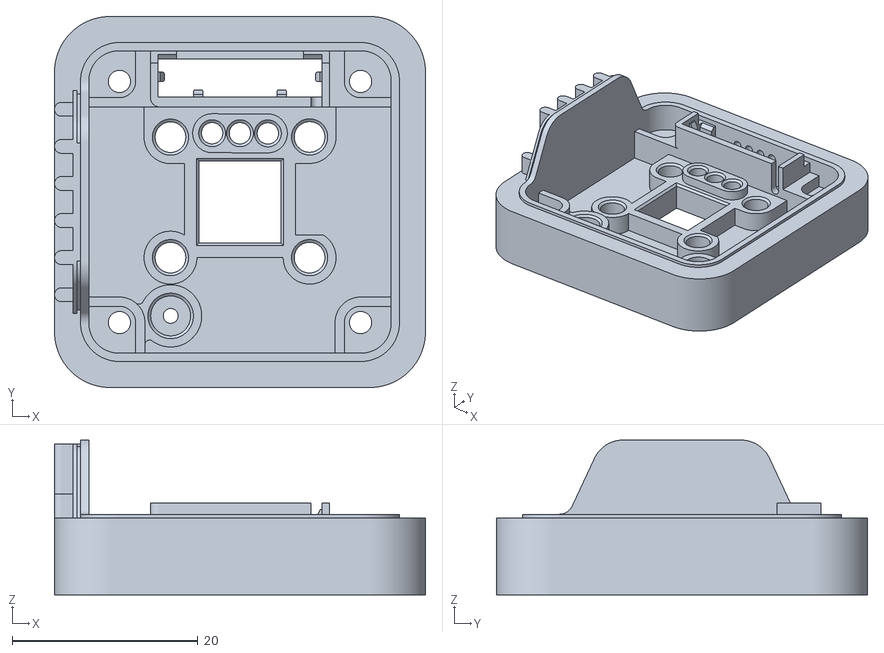
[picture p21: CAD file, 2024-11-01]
hardware/recamera-2002/sensors/s101-ov5647/3D_Printed_Case/recamera-sensorcover-4040-0904.stl
40.0 x 40.0 x 16.7

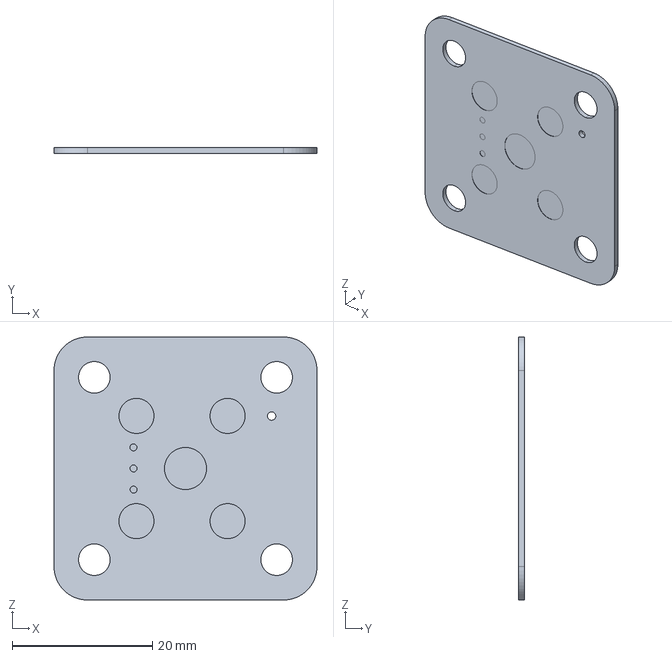
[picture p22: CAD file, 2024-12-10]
hardware/recamera-2002/products/gimbal/mechanical/glass-4040_6.stp
37.5 x 0.8 x 37.5 mm

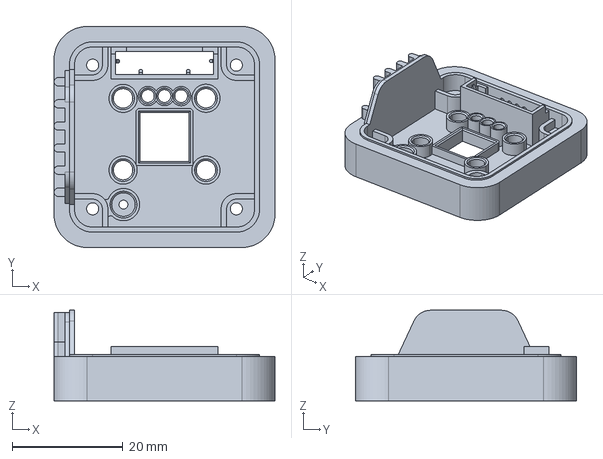
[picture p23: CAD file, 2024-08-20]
hardware/recamera-2002/sensors/s101-ov5647/3D_Printed_Case/recamera-sensorcover-4040.stp
40.0 x 40.0 x 16.4 mm

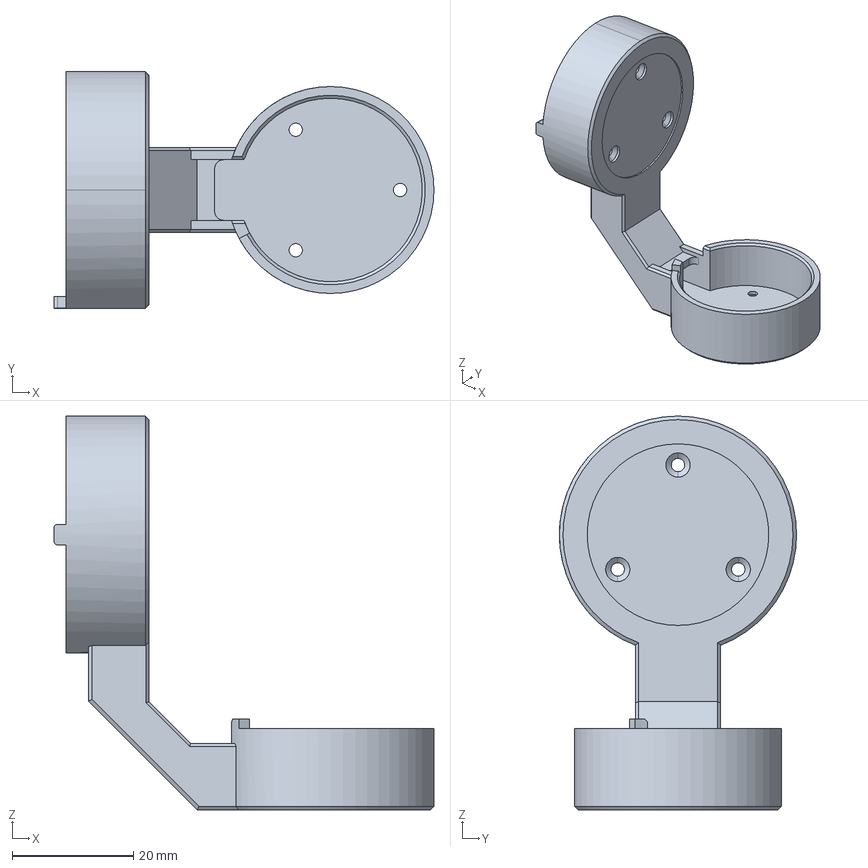
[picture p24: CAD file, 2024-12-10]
hardware/recamera-2002/products/gimbal/mechanical/recamera-yantai_arm_30.stp
62.8 x 39.2 x 65.1 mm

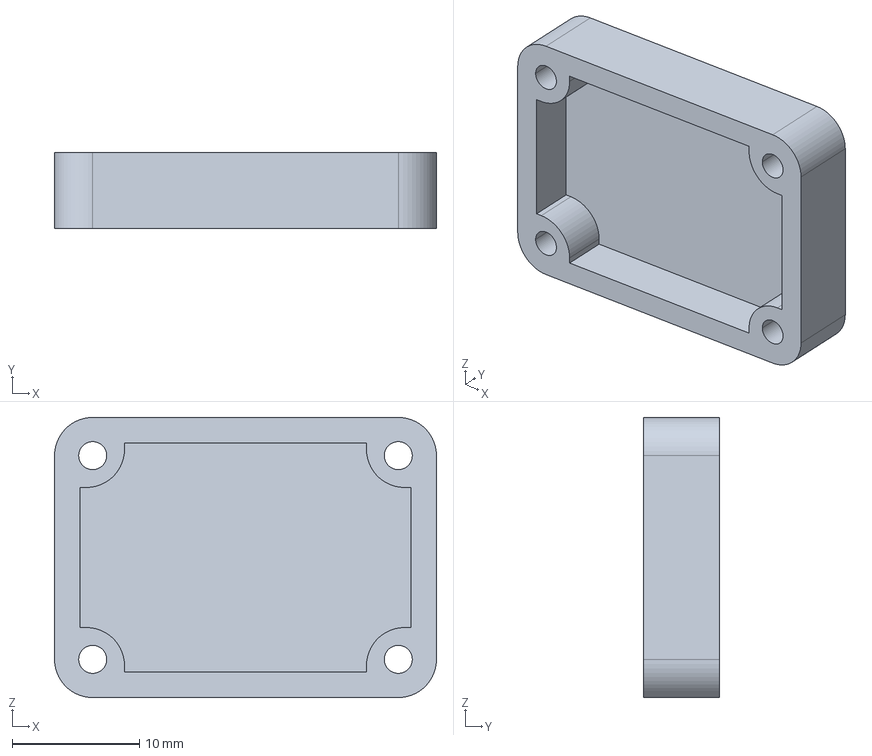
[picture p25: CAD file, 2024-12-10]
hardware/recamera-2002/products/gimbal/mechanical/can-case_3.stp
30.0 x 6.00 x 22.0 mm

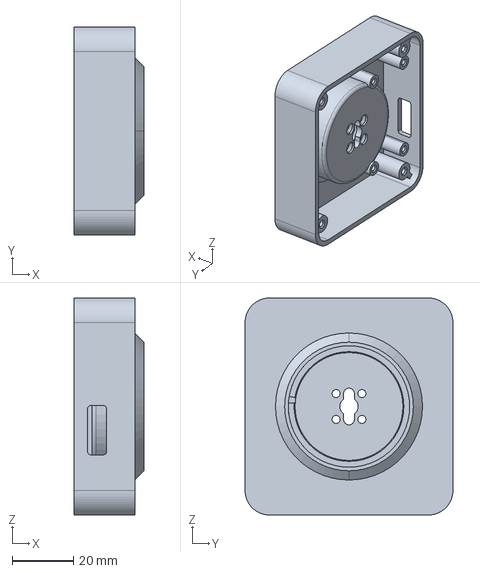
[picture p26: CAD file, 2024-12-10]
hardware/recamera-2002/products/gimbal/mechanical/platform-box_29.stp
23.0 x 68.0 x 71.0 mm

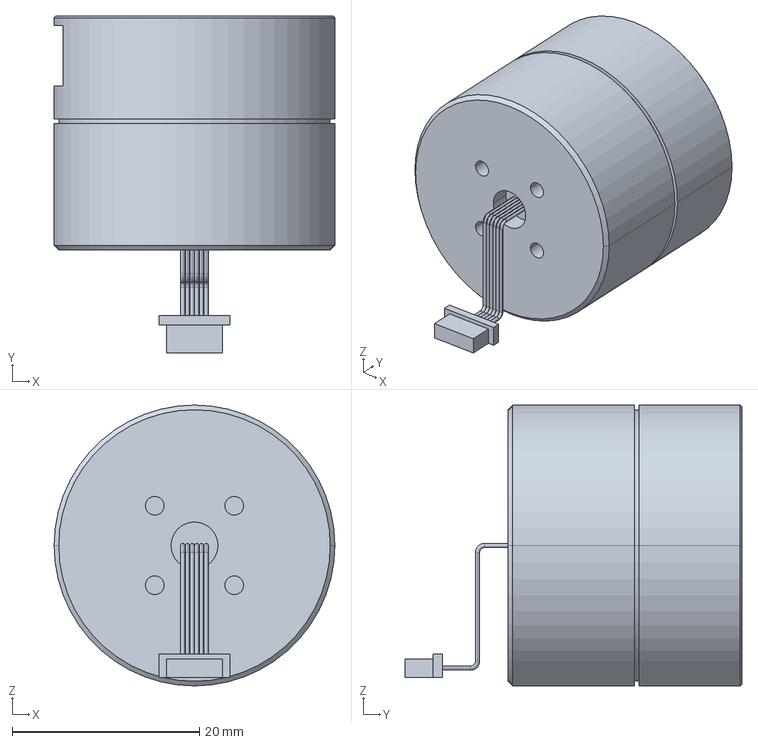
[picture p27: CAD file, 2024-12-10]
hardware/recamera-2002/products/gimbal/mechanical/brushlessmotor-ms3008v2_2.stp
30.0 x 36.0 x 30.0 mm

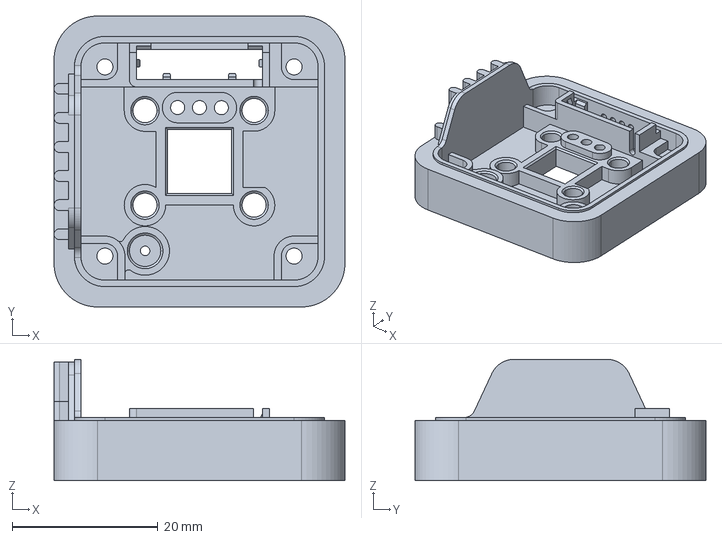
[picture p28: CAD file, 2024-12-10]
hardware/recamera-2002/products/gimbal/mechanical/recamera-sensorcover-4040-1_36.stp
40.0 x 40.0 x 16.7 mm

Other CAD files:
reCamera_Base_Board/B1_Default/Model/recamera_B1_Default.stp
hardware/recamera-2002/products/gimbal/mechanical/recamera-middleframe-4040-1_27.stp
hardware/recamera-2002/products/gimbal/mechanical/recamera-gimbalcover-4040_20.stp
hardware/recamera-2002/products/gimbal/mechanical/brushlessmotor-ms3506_4.stp
hardware/recamera-2002/base/b201-vertical-usb-c/3D_Printed_Case/b2_vertical_type-c.stl
hardware/recamera-2002/base/b301-poe/3D_Printed_Case/b3_poe.stl
hardware/recamera-2002/base/b401-can/3D_Printed_Case/B3_CAN.stl
hardware/recamera-2002/core/c1-2002/3D_Printed_Case/core_cooler.stl
hardware/recamera-2002/products/gimbal/mechanical/bottom-plate_10.stp

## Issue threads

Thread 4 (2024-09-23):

Question about what the camera is able to do.

dragonslayer452, 2024-09-23:
With the 1 TOPS AI processer can the camera alone run MiDaS AI (it's a AI that can give you depth with one camera ) if not is there a way for you to connect two cameras to the same baseboard so you can have stereo vision for depth sensing

litxaohu, 2024-09-24:
We haven't tested MiDaS AI, but theoretically, you can design a sensor board to integrate two cameras onto a single baseboard, as the top board has four differential signal lines. It's important to consider whether the PCB size is sufficient for installation and to address any potential heat dissipation issues.

yuking926, 2024-10-22:
你们好，这个相机你们已经在测试了吗，为什么我找不到核心板的任何pcb信息，我也想要制作一个这样的相机来学习

Closed 2024-10-30.

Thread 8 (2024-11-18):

[Bug] Toggling "Enable Wifi" switch does not save state

O-J1, 2024-11-18:
### What I saw
https://github.com/user-attachments/assets/1db8e680-cbf0-4e2e-b075-dfcf4d052ff2

Toggle state does not actually apply/persist

### What I expect

Toggling actually works

Lesords, 2024-11-19:
Hello, what did you do at the 4th second?

Did you open multiple web pages and then switch between them?

O-J1, 2024-11-19:
> Hello, what did you do at the 4th second?
>
> Did you open multiple web pages and then switch between them?

I just paused recording to censor out my wifi address. Toggling enable then refreshing the page (hit f5) doesn’t keep it toggled off

O-J1, 2025-01-08:
It’s still in todo. It’s a confirmed bug.

dihan, 2025-01-10:
Wifi also unable to show the full name. if a wifi name is 'SKY123 NETWORK' it will only show the first word (SKY123). I'm not sure if that has an effect when trying to connect. I'm unable to connect to Wifi and shows a connection time

Lesords, 2025-01-10:
> Wifi also unable to show the full name. if a wifi name is 'SKY123 NETWORK' it will only show the first word (SKY123). I'm not sure if that has an effect when trying to connect. I'm unable to connect to Wifi and shows a connection time

This has already been mentioned here https://github.com/Seeed-Studio/reCamera-OS/issues/10

Yes, this problem does cause the wifi connection to fail successfully

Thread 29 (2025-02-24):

Core Board C1_2002 Missing .kicad_pro file

HarrisonCreates, 2025-02-24:
Not quite sure if this is 100% an issue, but the Base board and Sensor boards each include a .kicad_pro file that have the .kicad_sch and .kicad_pcb files, but the Core board, arguably the most complex of the board, is compressed in a PDF format. Any chance we can have the KiCad files as well?

Thanks in advance!

Lesords, 2025-02-24:
Hello,

Thank you so much for taking the time to share your thoughts and raise this query on GitHub. We truly value your engagement with our project and your interest in the technical details.

We were wondering if you're considering self - production. The KiCad files are primarily designed for that purpose. But self - production can be quite expensive, especially since this chip is not for direct consumer use. So, the practical value of having these files might be limited for you.

If your intention is for learning, the circuit design in the PDF we provided has all the essential information that should serve your purpose well.

However, if you have a compelling need for the KiCad files, please don't hesitate to reach out to edgeai@seeed.cc and let us know the reasons. We're here to understand your situation and offer the best support we can.

On another note, in the future, we'll be selling the Core board along with its aluminum frame separately. If you might be interested in purchasing them, all you need to do is drop us an email.

We look forward to further communication with you and hope to continue to meet your needs.

Closed 2025-02-24.

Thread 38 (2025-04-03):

Request reCamera_Core_Board C1_2002 kicad project file

discodyer, 2025-04-03:
I would like to obtain the reCamera_Core_Board C1_2002 kicad project file to learn component layout. I need to design a sg2002 core board by myself, not for production of reCamera core board, but as a reference design. Currently only the schematics are available, which is not enough to design a core board by myself.

You can contact me through the following email: cody23333#gmail.com (#->@)

Thank you sincerely.

Lesords, 2025-04-07:
Hello

Our colleagues have sent you a file to your mailbox, please check it.

Lesords, 2025-04-07:
Also, next time you can send the email number information like this (

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

discodyer, 2025-04-07:
Thank you for your reply, I received the email. This is to prevent the crawler bot from sending me spam, so I used #

Lesords, 2025-04-07:
Oh, I see. But you still have your e-mail address in your personal information (

Lesords, 2025-04-07:
Well, if there are no other questions, I'll close this issue.

Closed 2025-04-07.

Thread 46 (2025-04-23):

No USB-CDC driver on Windows 10

djairjr, 2025-04-23:
The device is detected, but does not install the drivers that enable access to the camera through the network created via USB. There is no link to download the driver in the instructions.

mingzhangqun, 2025-04-28:
@djairjr Hi, you can reference with [this](https://milkv.io/docs/duo/getting-started/setup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,list%20of%20available%20drivers%20on%20my%20computer.%20%E6%9B%B4%E5%A4%9A%E9%A1%B9%E7%9B%AE)

djairjr, 2025-04-29:
Would it be better if these instructions were on the Recamera Wiki?

Lesords, 2025-05-06:
> Would it be better if these instructions were on the Recamera Wiki?

Already in the wiki https://wiki.seeedstudio.com/recamera_network_connection/#install-ncm-for-windows

Lesords, 2025-05-06:
I'm going to close this issue, feel free to re-open it if you have any other questions.

Closed 2025-05-06.

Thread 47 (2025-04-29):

File .step reCamera

AlexandreAPX, 2025-04-29:
Hello, can you post the .step files of the aluminum camera body, base, and sensor guard? Do you have the .step of the complete camera? It's easier to draw the mount. Thanks.

Lesords, 2025-04-30:
[recamera-4040_0918asm.zip](https://github.com/user-attachments/files/19970361/recamera-4040_0918asm.zip)

Lesords, 2025-05-06:
Hello,

I'm going to close this issue, feel free to re-open it if you have any other questions.

Closed 2025-05-06.

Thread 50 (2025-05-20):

New sensor and board

baichuan05, 2025-05-20:
Hi Team,

When will the new sensor [IMX335](https://github.com/Seeed-Studio/OSHW-reCamera-Series/blob/main/reCamera_Sensor_Board/S2_IMX335/readme.md) be out for purchase?
Same for the [B3_POE](https://github.com/Seeed-Studio/OSHW-reCamera-Series/blob/main/reCamera_Base_Board/B3_POE/B3_Readme.md).

Also, will the replacement be straight forward? I have the current recamera. Thanks!

nil1001, 2025-06-16:
请问SensorSupportList里面没有SC130GS，Sensor board里面却有这个型号，后续开发计划延期还是取消了？

swortain, 2025-06-25:
> 请问SensorSupportList里面没有SC130GS，Sensor board里面却有这个型号，后续开发计划延期还是取消了？

你好，目前还没有SC130GS的量产计划。

Closed 2025-08-09.

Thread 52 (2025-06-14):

can i use IMX462 mipi csi module

zorro1011, 2025-06-14:
hi
before buying I would like to understand if I can use the cam module IMX462 mipi csi (have the flat cable 15 or 22 pin for connect to RPI2-3-4 and ZERO?
this has 2.9um pixels which offer a sensitivity in the dark significantly greater than the imx335

is there a way to use imx462?
thanks
best regards

zorro1011, 2025-07-08:
thank you very much

I commented out the whole block for safety.
I didn't like having unclean code

`#    if [ "$2" ]; then
#        sed -i "s/ssid=.*$/ssid=$2/g" $hostapdFile
#        sync
#    fi
`
worked perfectly
thanks again
best regards

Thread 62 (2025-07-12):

Recording on AI Event: Adjust FPS and Save Video Conditionally

zorro1011, 2025-07-12:
Hello, I'm working with the reCamera and I'm trying to set up a workflow that records video only when a person is detected.

Here is the behavior I'm trying to implement:
The camera stays active continuously at 5 fps, to reduce energy consumption.
While running at 5 fps, it constantly performs AI detection, searching for the label "person".

If "person" is detected:
Increase the framerate to 30 fps
Start recording video
Keep recording until 5 seconds have passed without any "person" detected

Then:
Stop recording
Switch back to 5 fps
Resume the detection cycle

Is this kind of conditional recording and dynamic framerate control possible using the current SSCMA Node-RED nodes and reCamera system? Specifically:

Can the framerate be adjusted dynamically via Node-RED?

Is there a way to start/stop video recording programmatically based on detection events?

Any documentation, examples, or advice would be really appreciated!

Thanks in advance.
best regards

LynnL4, 2025-07-16:
Can the framerate be adjusted dynamically via Node-RED?
Sorry, dynamic framerate adjustment is not supported at the moment.

Is there a way to start/stop video recording programmatically based on detection events?
Yes, it’s supported. Each firmware provides methods to control video recording on/off. Please refer to the documentation here:

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

LynnL4, 2025-07-21:
Yes, Node-RED has a built-in mechanism to start automatically.
Do you have any other questions?
As for the frame rate adjustment issue, we’ve taken note of it and will consider how to support it in future versions. Thank you.

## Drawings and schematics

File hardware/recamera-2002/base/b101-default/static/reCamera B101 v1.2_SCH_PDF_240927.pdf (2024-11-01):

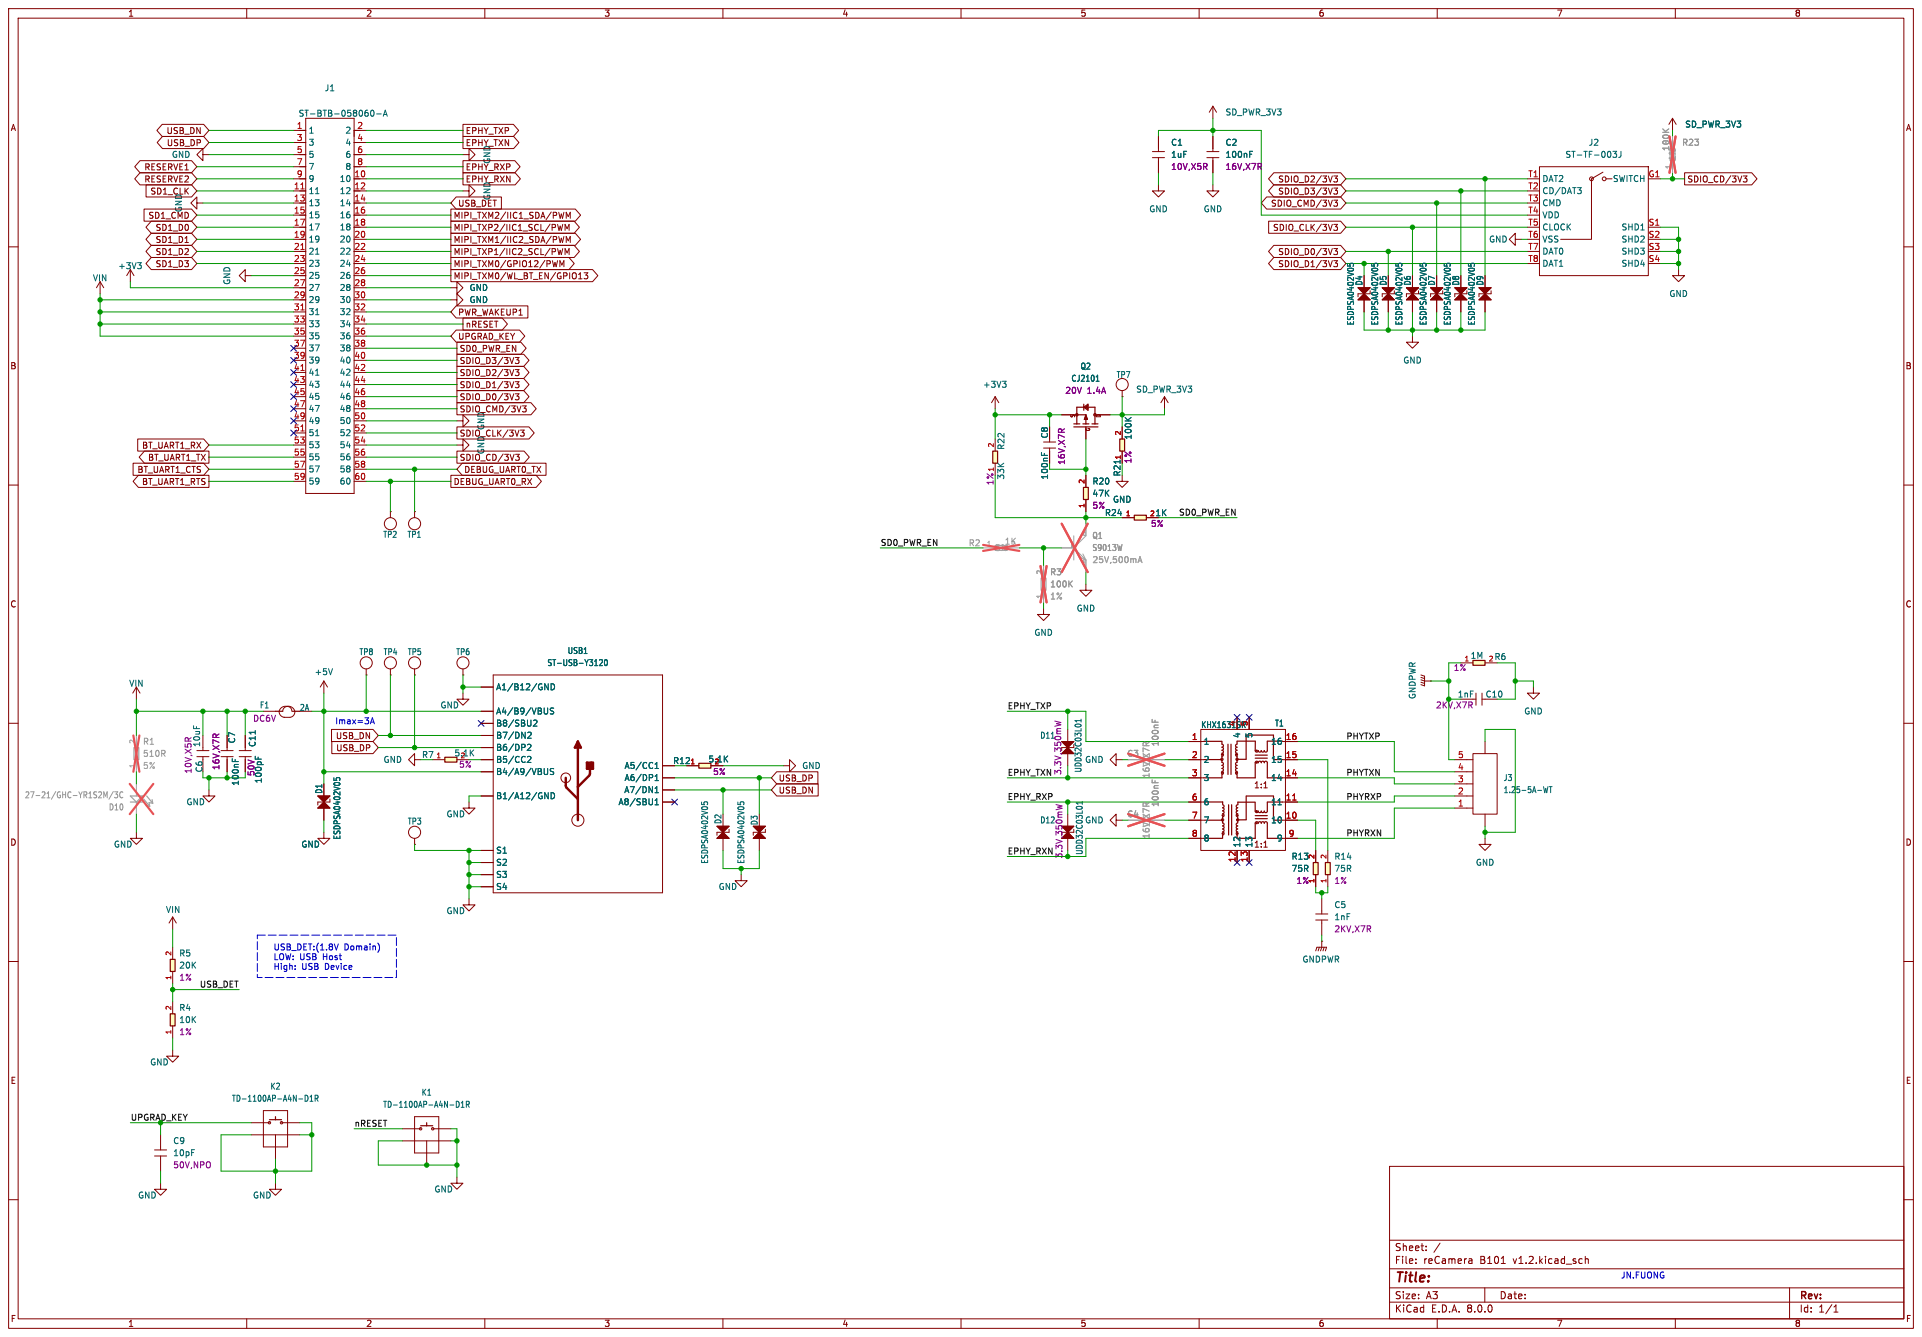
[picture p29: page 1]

USB_DET:(1.8V Domain) LOW: USB Host High: USB Device

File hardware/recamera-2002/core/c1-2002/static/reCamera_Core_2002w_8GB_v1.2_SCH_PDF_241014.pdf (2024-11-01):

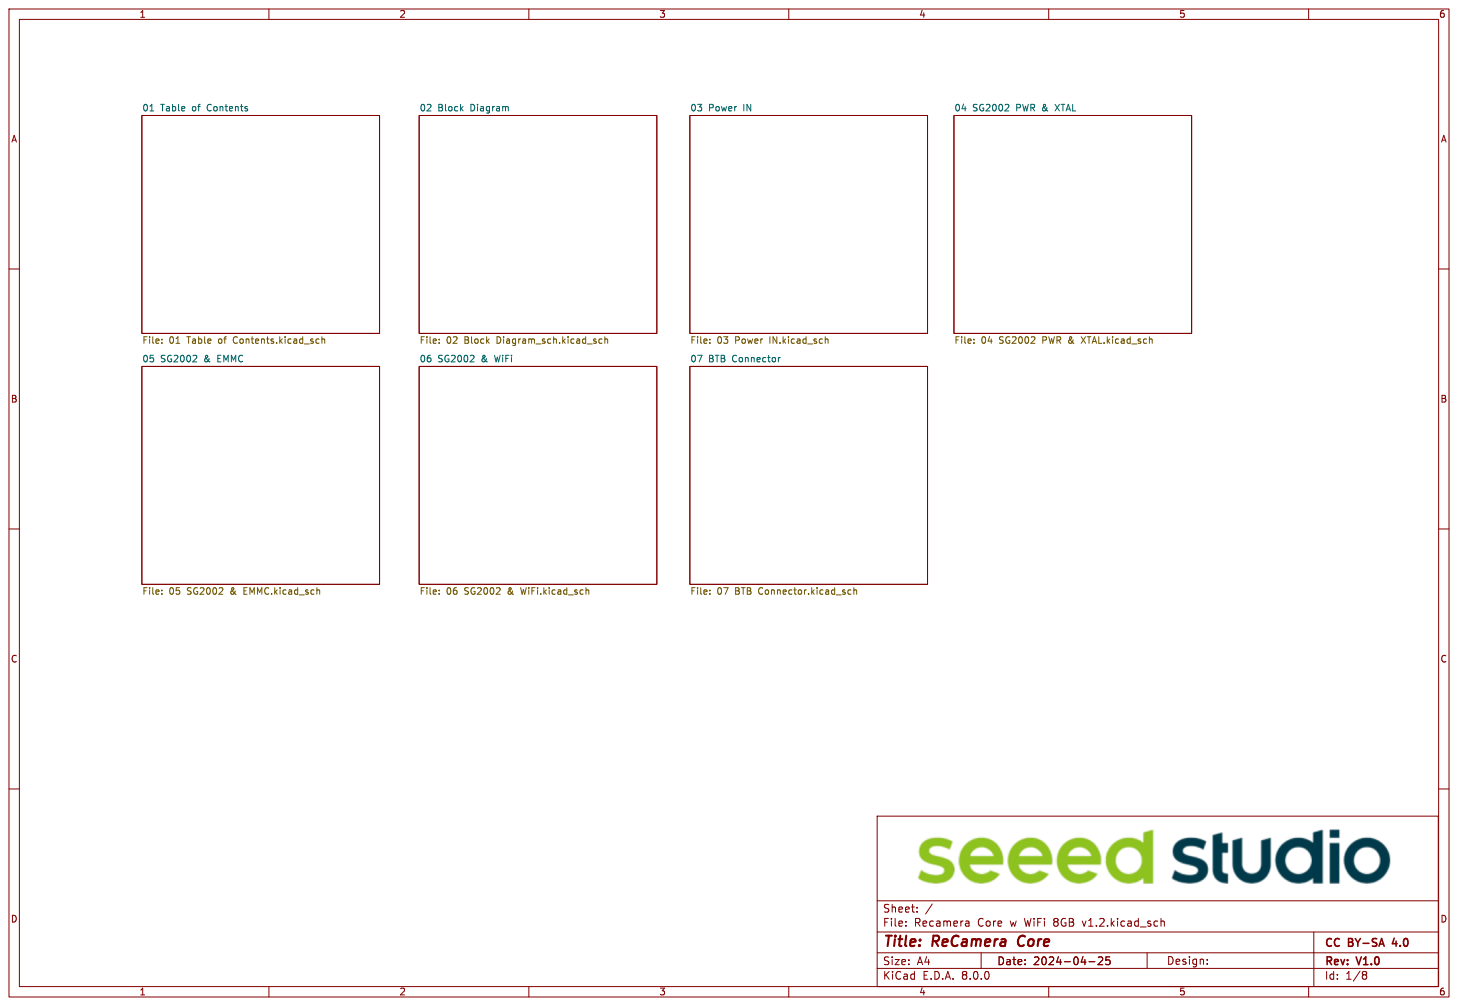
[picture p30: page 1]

01 Table of Contents File: 01 Table of Contents.kicad_sch

04 SG2002 PWR & XTAL File: 04 SG2002 PWR & XTAL.kicad_sch

File: 03 Power IN.kicad_sch
07 BTB Connector File: 07 BTB Connector.kicad_sch

Id: 1/8 Title: ReCamera Core

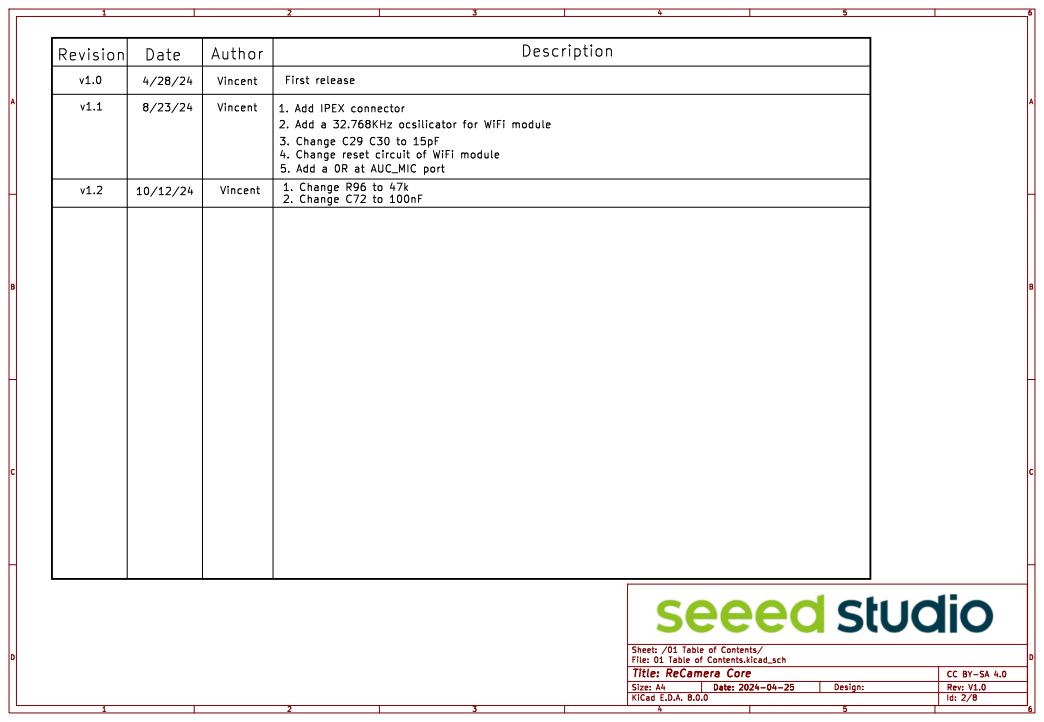
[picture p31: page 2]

Id: 2/8 Title: ReCamera Core

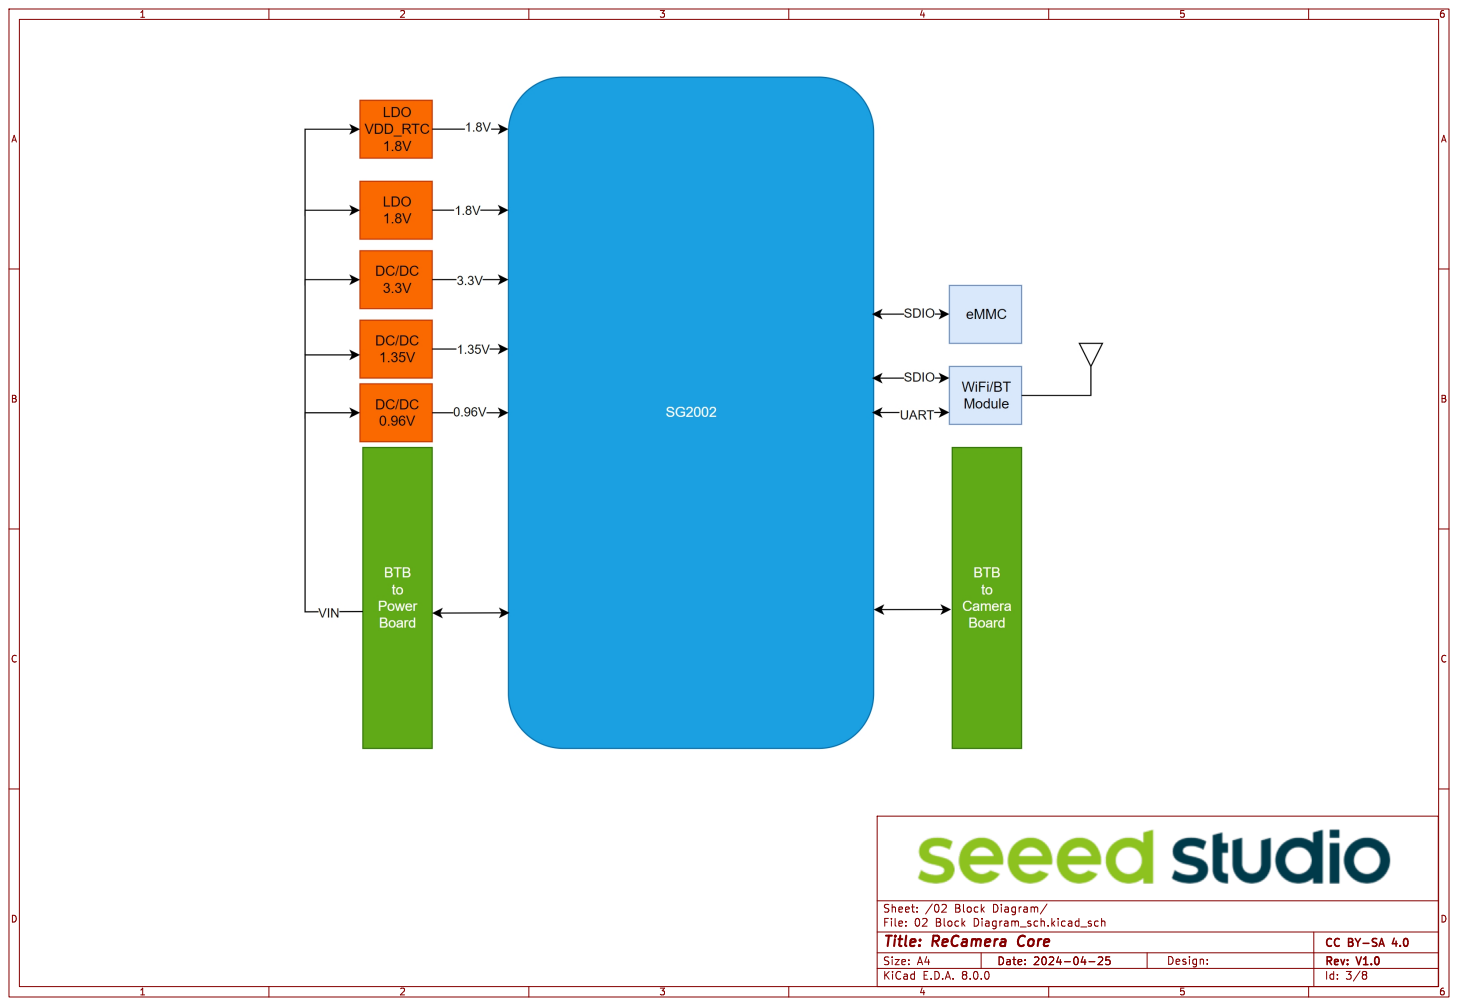
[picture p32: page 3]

Id: 3/8 Title: ReCamera Core

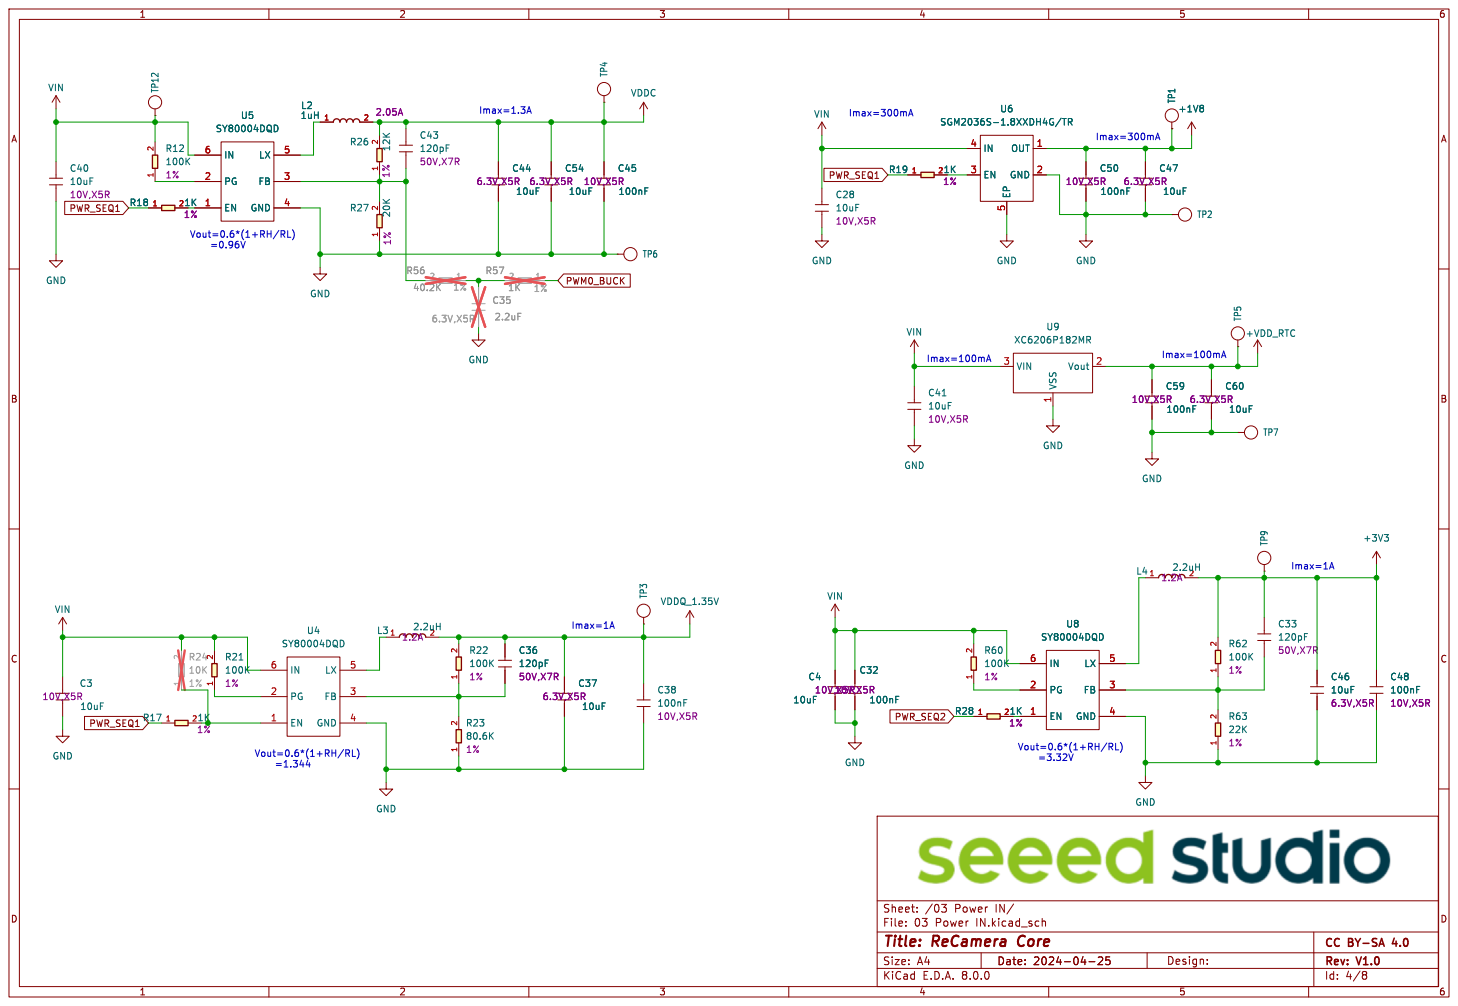
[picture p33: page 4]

Id: 4/8 Title: ReCamera Core

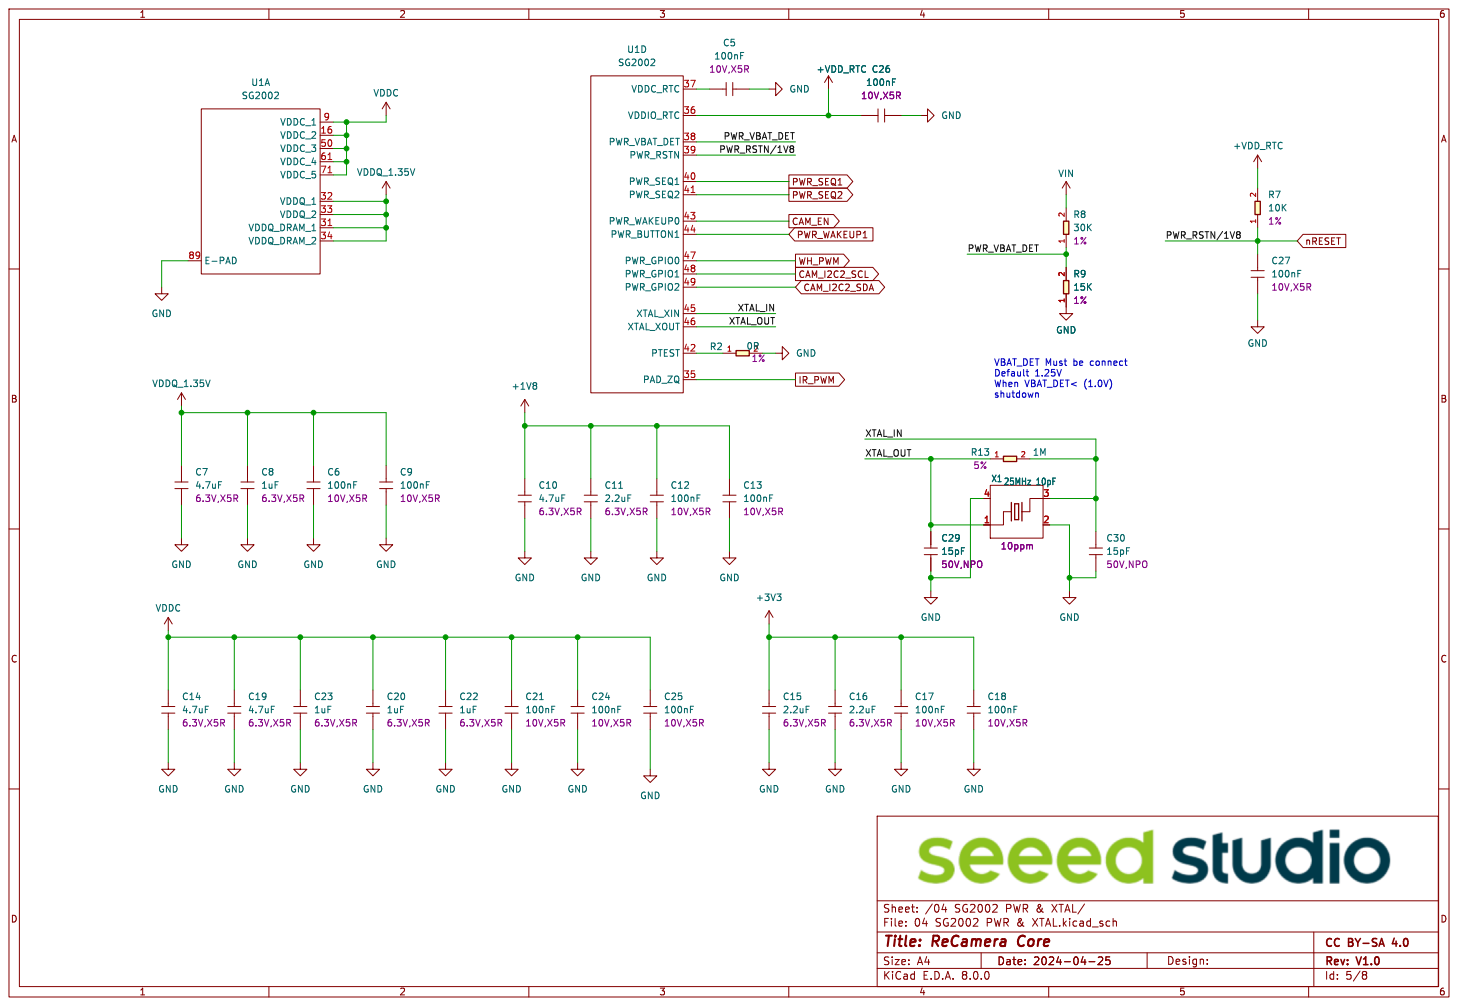
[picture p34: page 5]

VBAT_DET Must be connect Default 1.25V When VBAT_DET< (1.0V) shutdown C26

Id: 5/8 Title: ReCamera Core

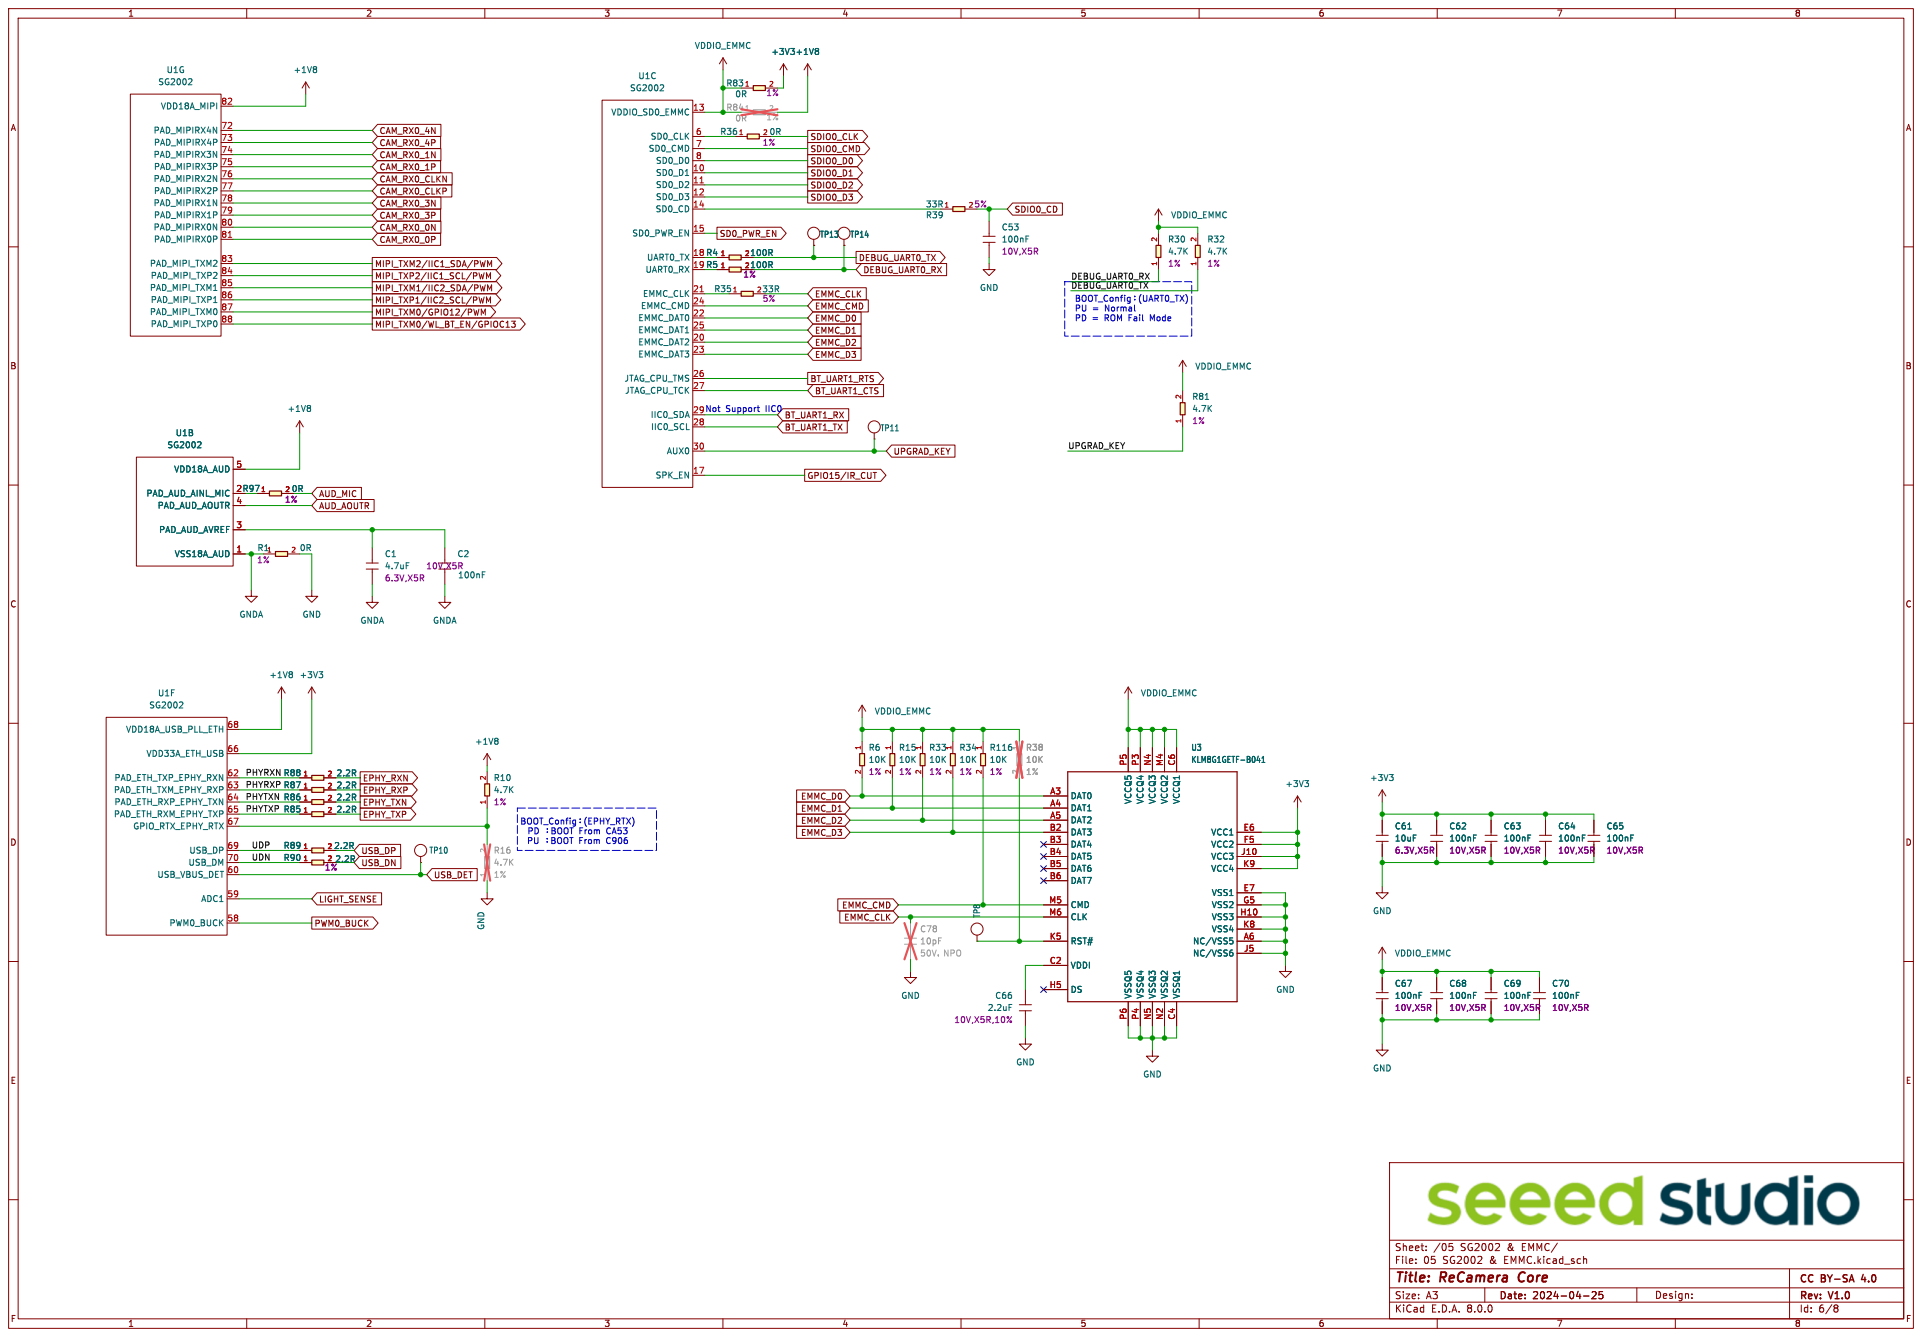
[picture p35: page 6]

þÿBOOT_Configÿ(UART0_TX) PU = Normal PD = ROM Fail Mode Not Support IIC0

þÿBOOT_Configÿ(EPHY_RTX) PD þÿÿBOOT From CA53 PU þÿÿBOOT From C906

Id: 6/8 Title: ReCamera Core

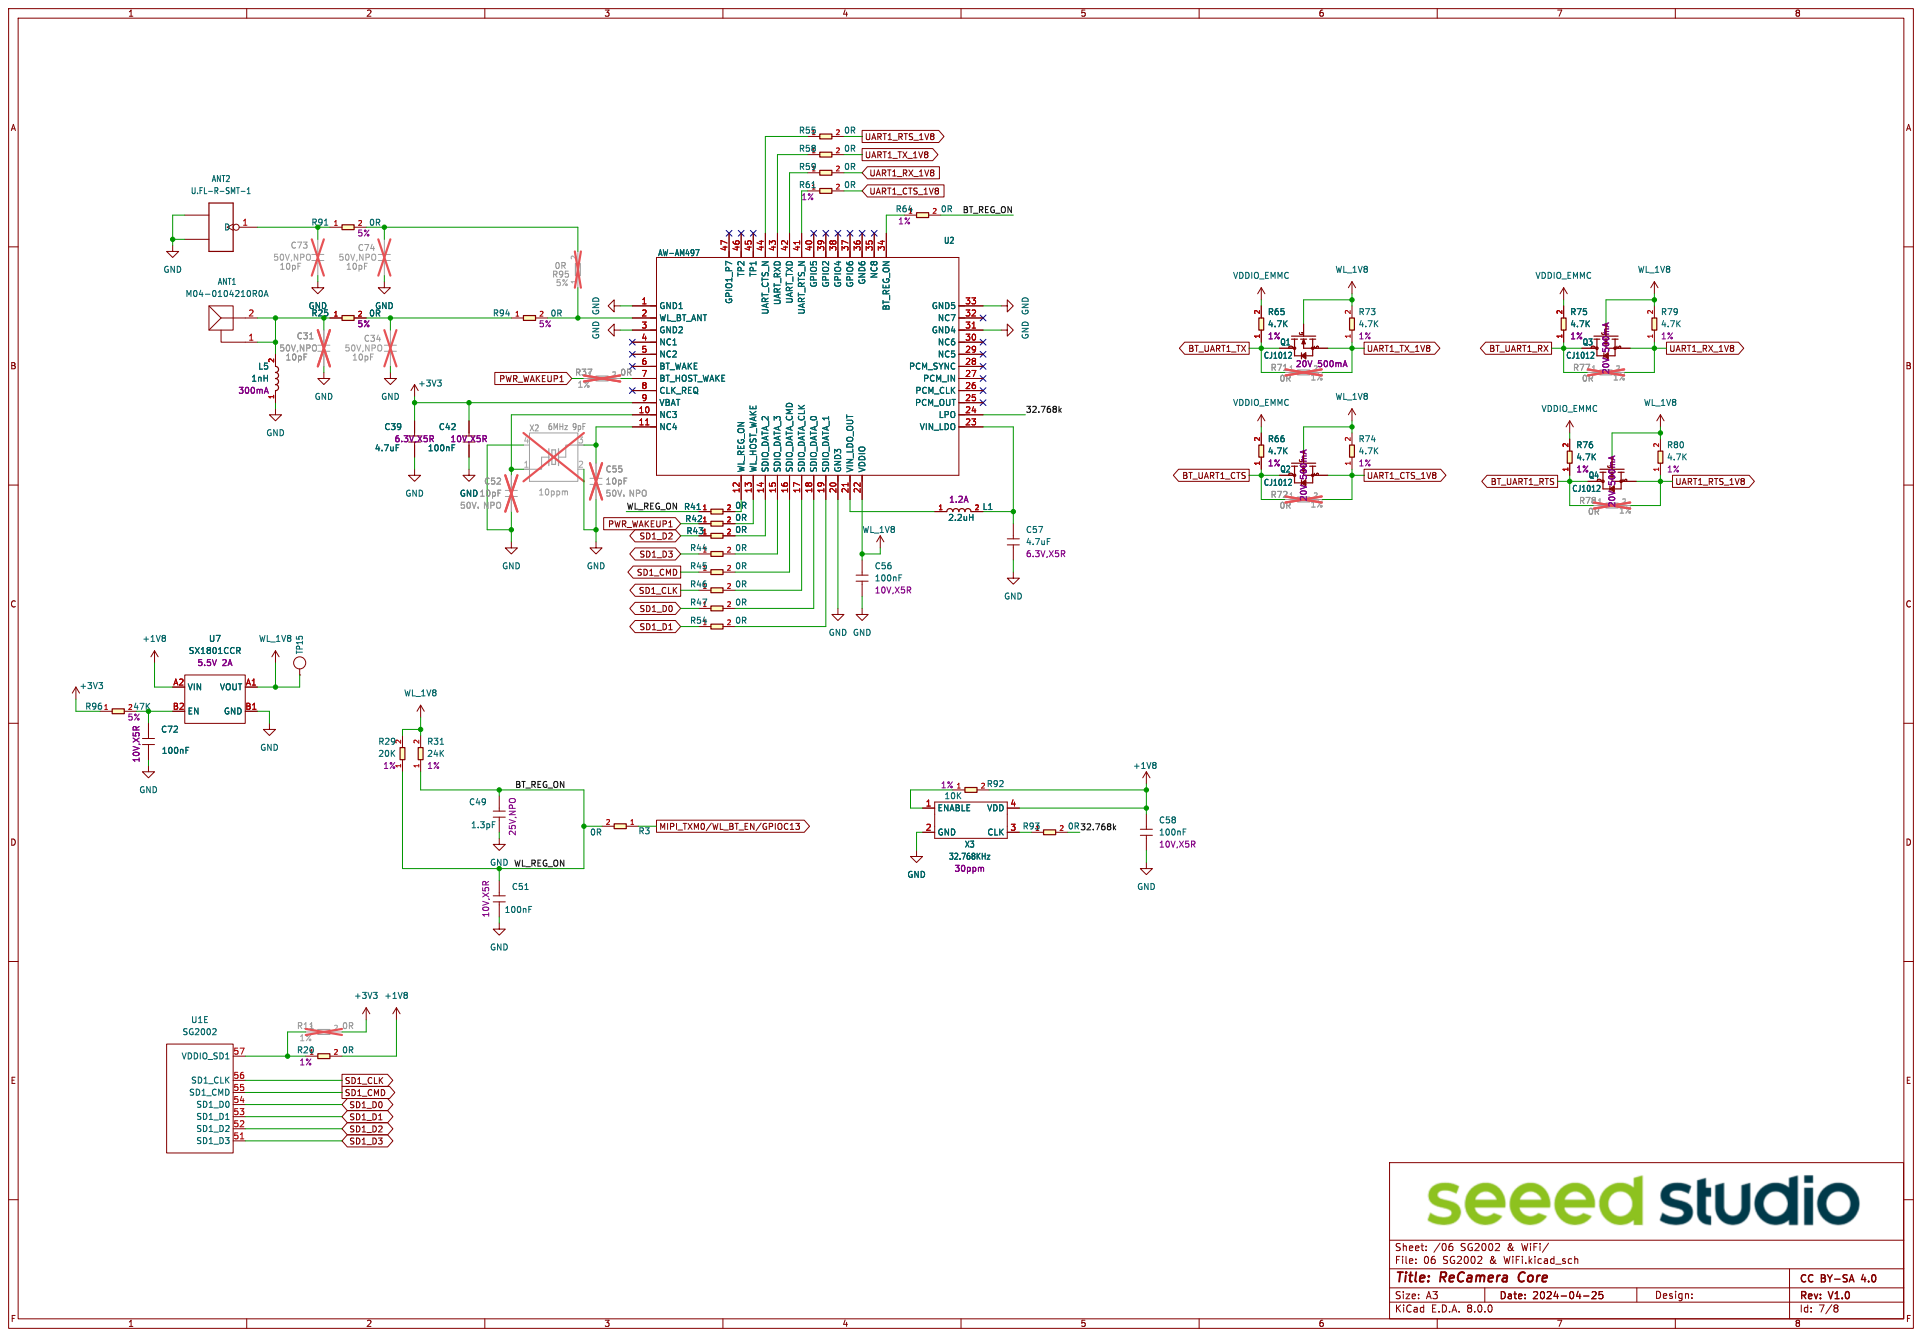
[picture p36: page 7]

Id: 7/8 Title: ReCamera Core

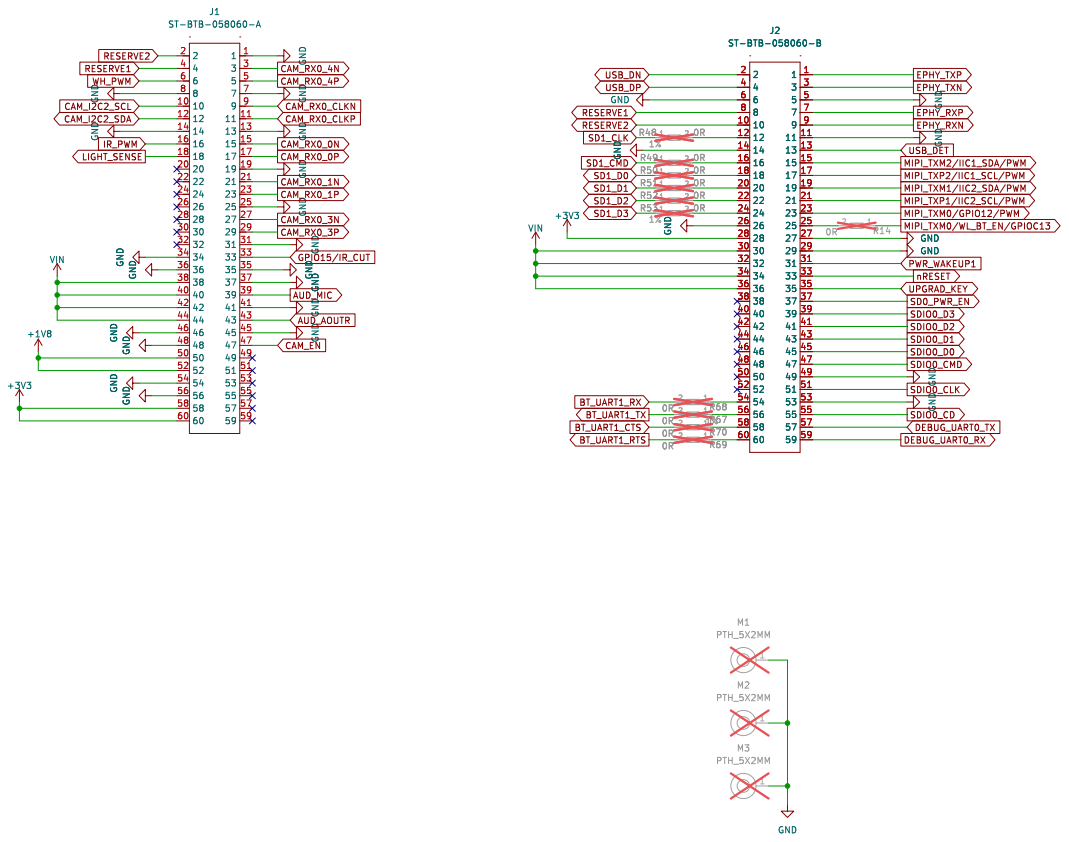
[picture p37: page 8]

9 GND GNDGND GND GND GND GND GND

Id: 8/8 Title: ReCamera Core

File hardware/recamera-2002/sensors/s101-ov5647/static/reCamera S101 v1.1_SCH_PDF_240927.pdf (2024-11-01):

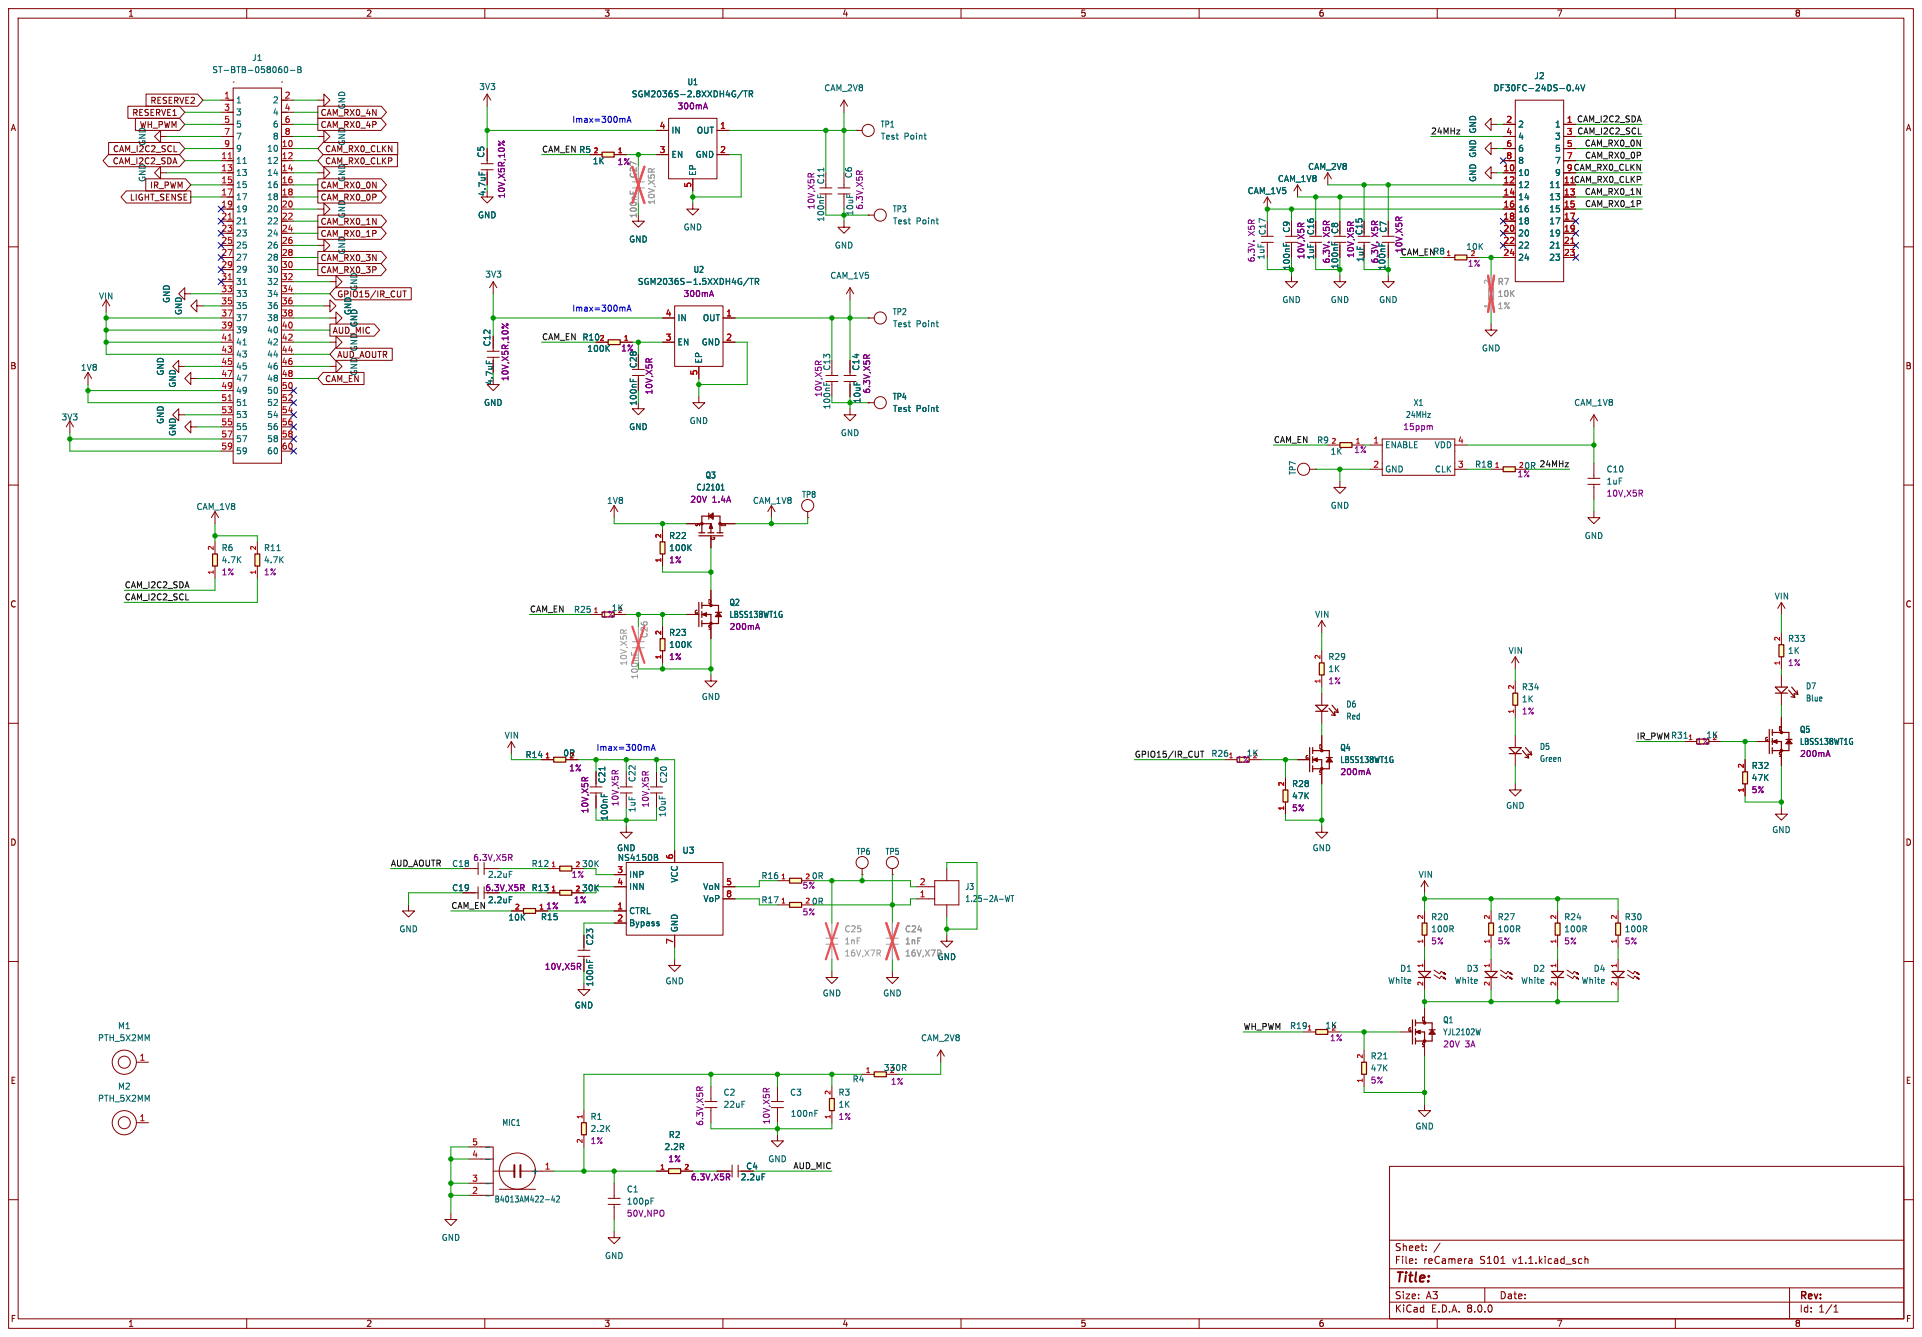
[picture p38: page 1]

CAM_RX0_0P CAM_RX0_1P
CAM_1V8 GND GND GND GND
300mA GND GND

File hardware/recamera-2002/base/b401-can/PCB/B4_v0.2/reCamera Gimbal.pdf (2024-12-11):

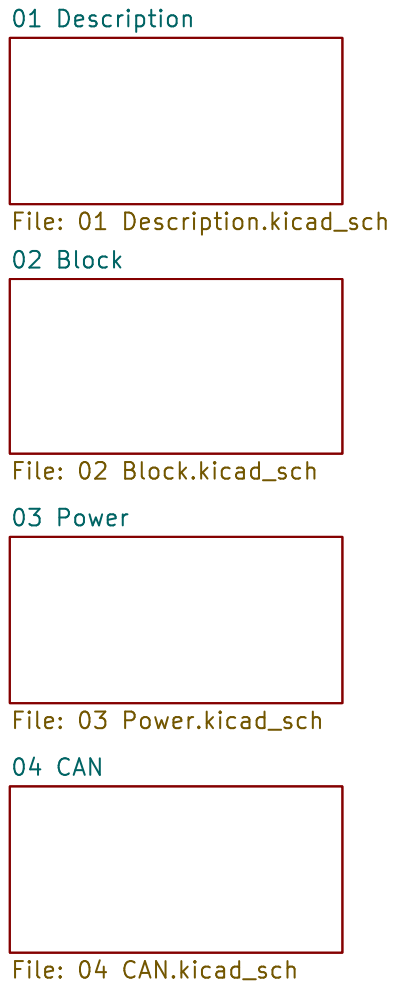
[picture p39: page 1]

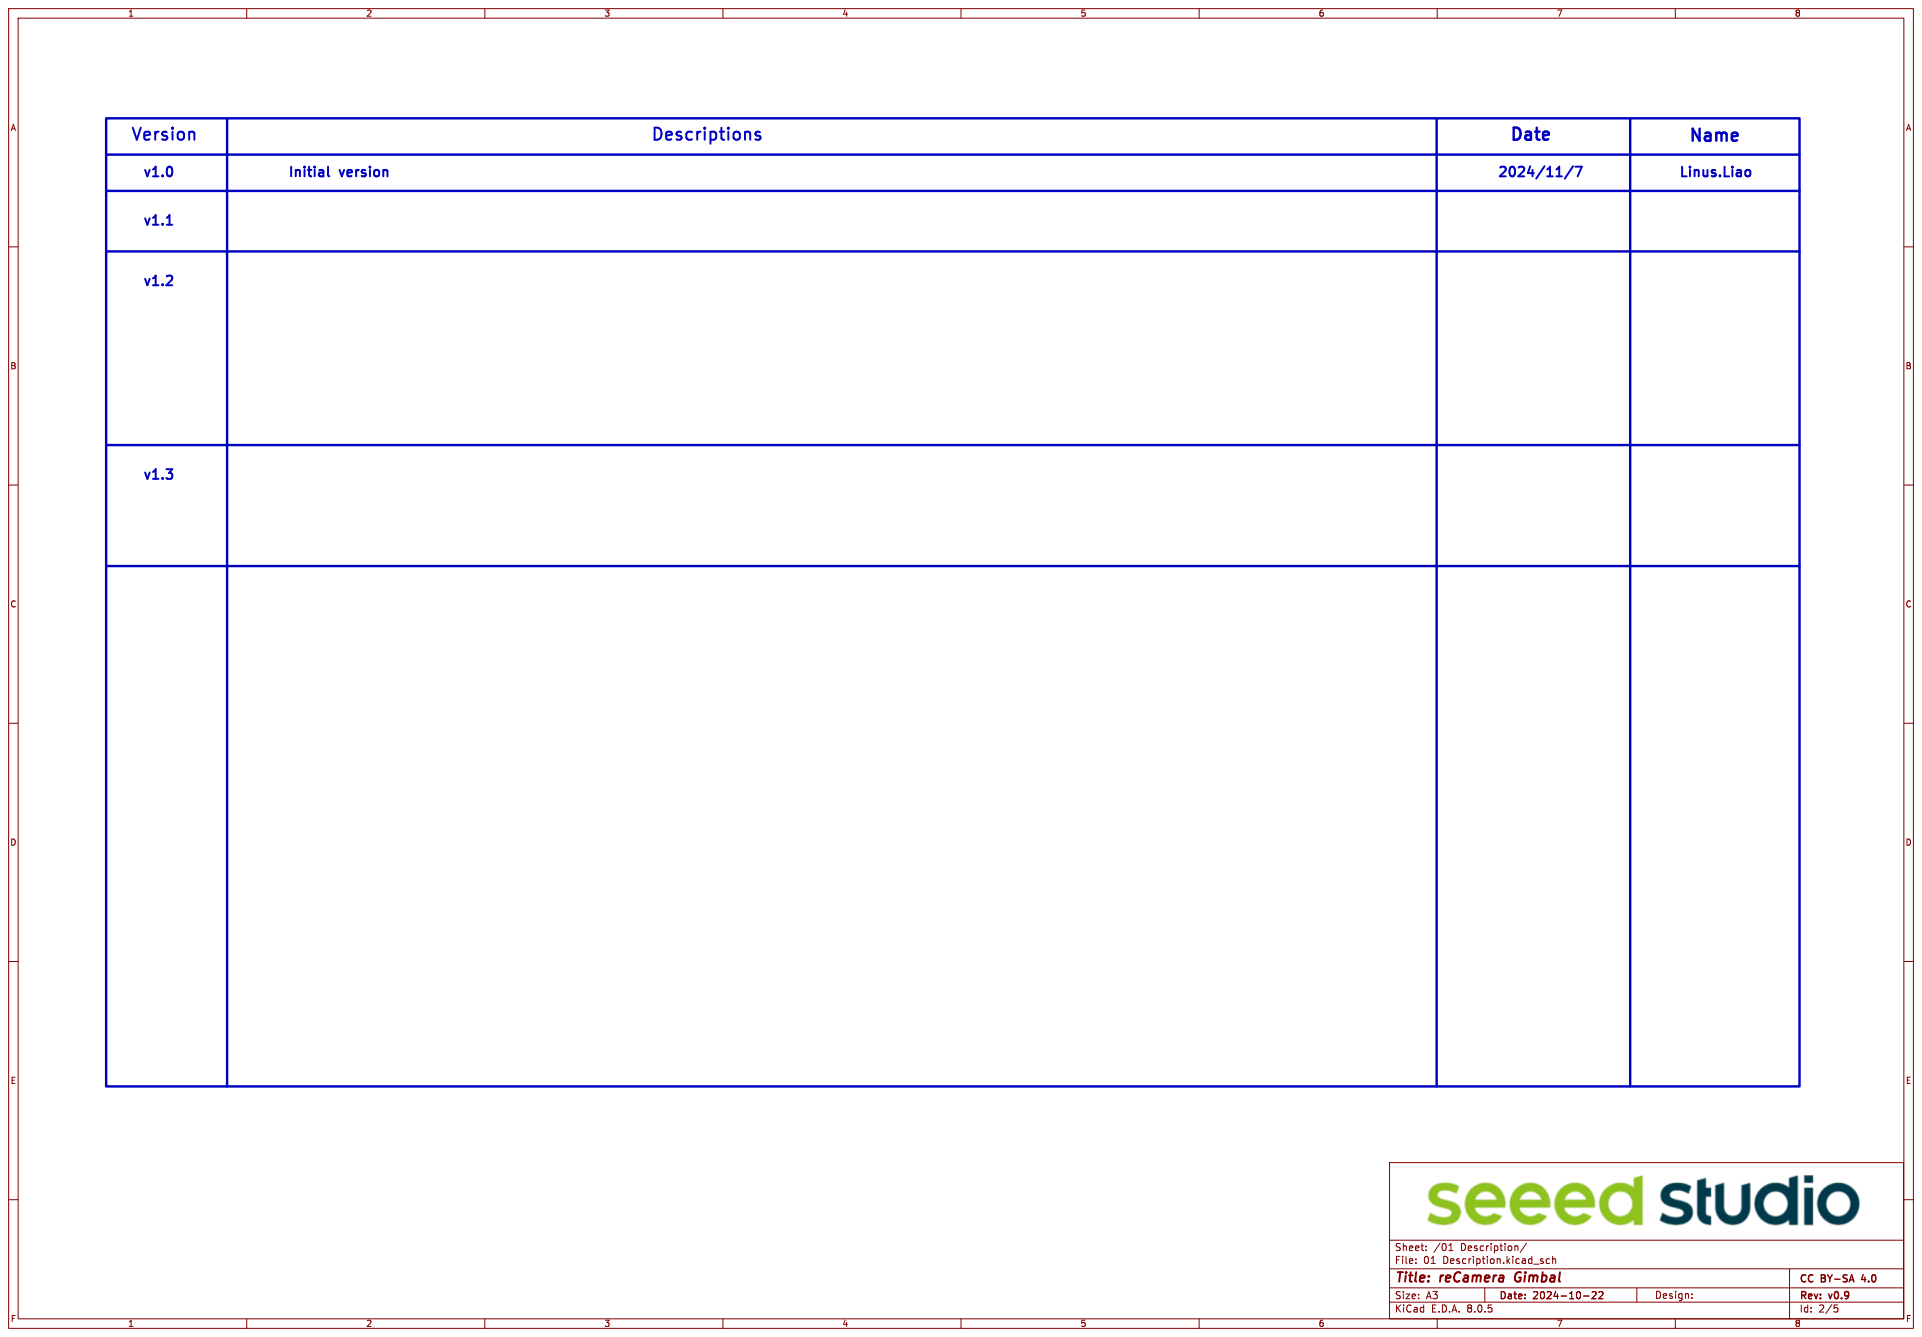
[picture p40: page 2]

Date | Name



4 BST 5 EN/SYNC 6 VCC 7 FB 8 U1MP2315GJ 3A

4 BST 5 EN/SYNC 6 VCC 7 FB 8 C4


Vin:12V~24V CAN & Power IN

TXCAN 1 SCK 10 SDI 11 SDO 12

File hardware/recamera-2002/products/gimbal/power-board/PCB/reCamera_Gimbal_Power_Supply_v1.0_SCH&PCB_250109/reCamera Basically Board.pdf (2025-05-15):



Date | Name



J3SM06B-SRSS-TB(LF)(SN)

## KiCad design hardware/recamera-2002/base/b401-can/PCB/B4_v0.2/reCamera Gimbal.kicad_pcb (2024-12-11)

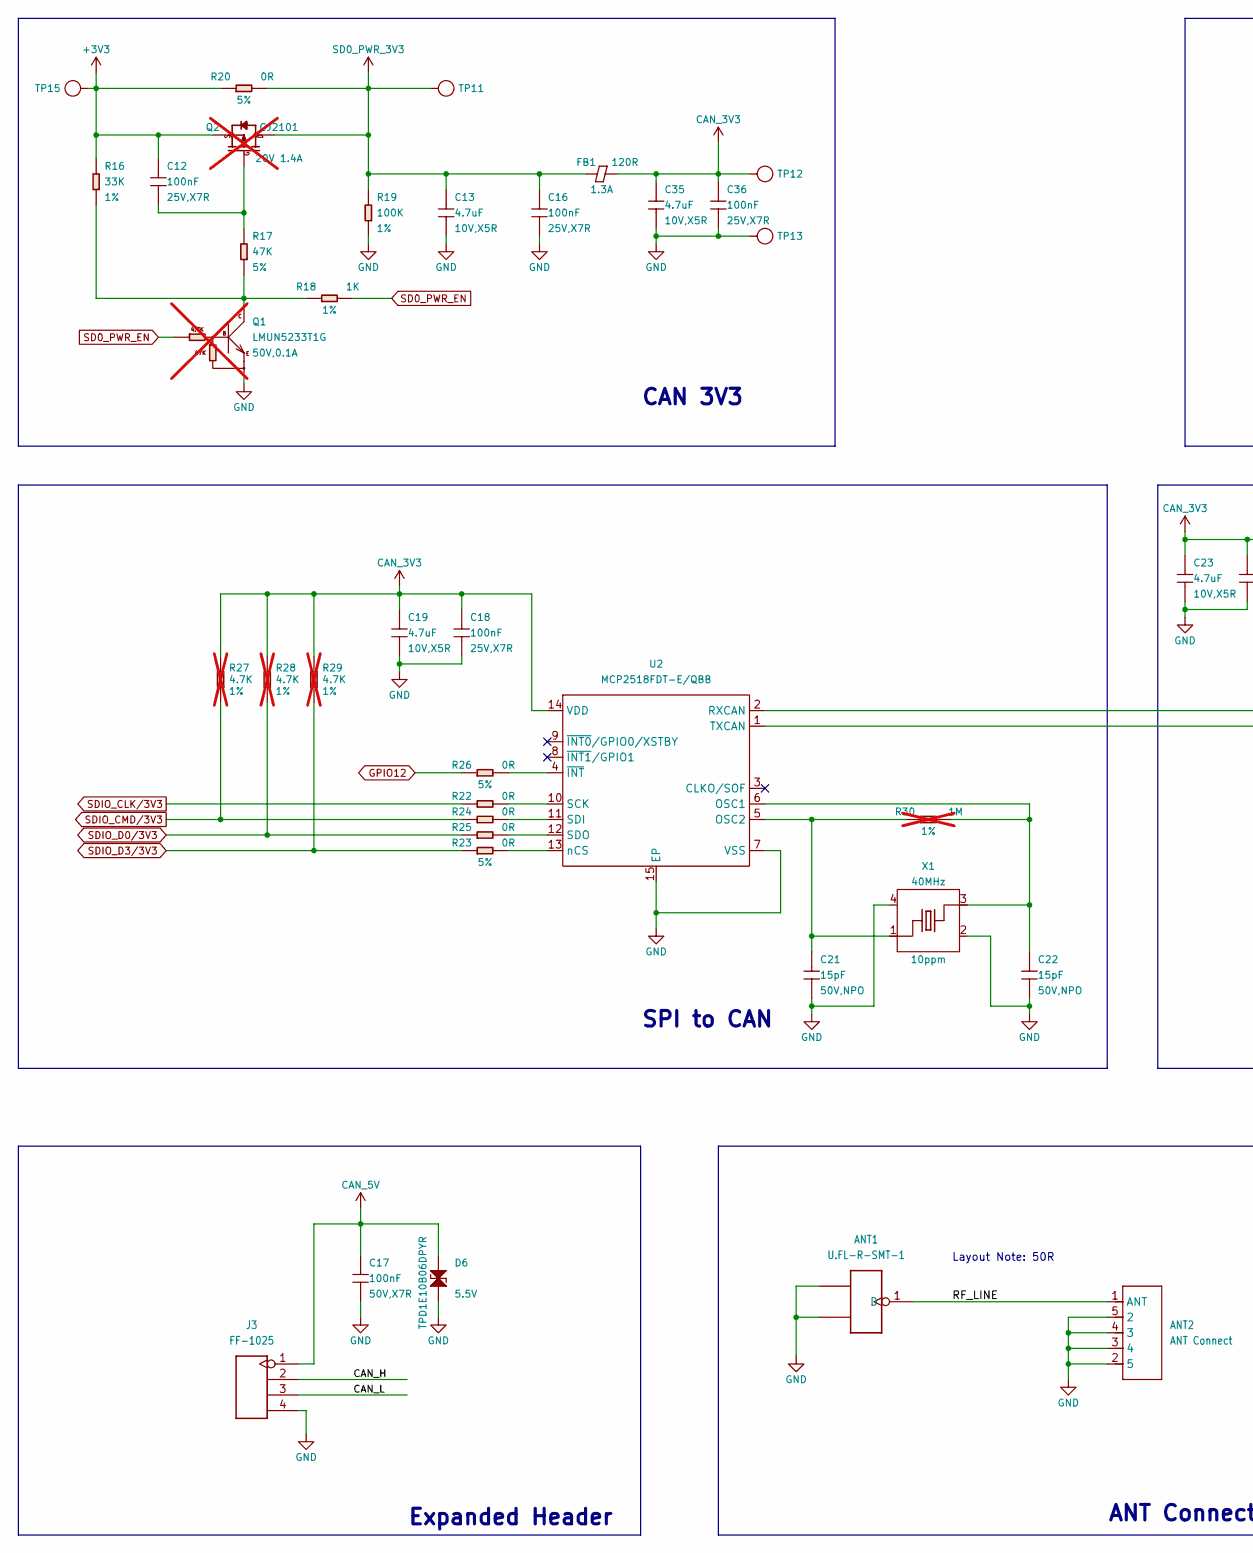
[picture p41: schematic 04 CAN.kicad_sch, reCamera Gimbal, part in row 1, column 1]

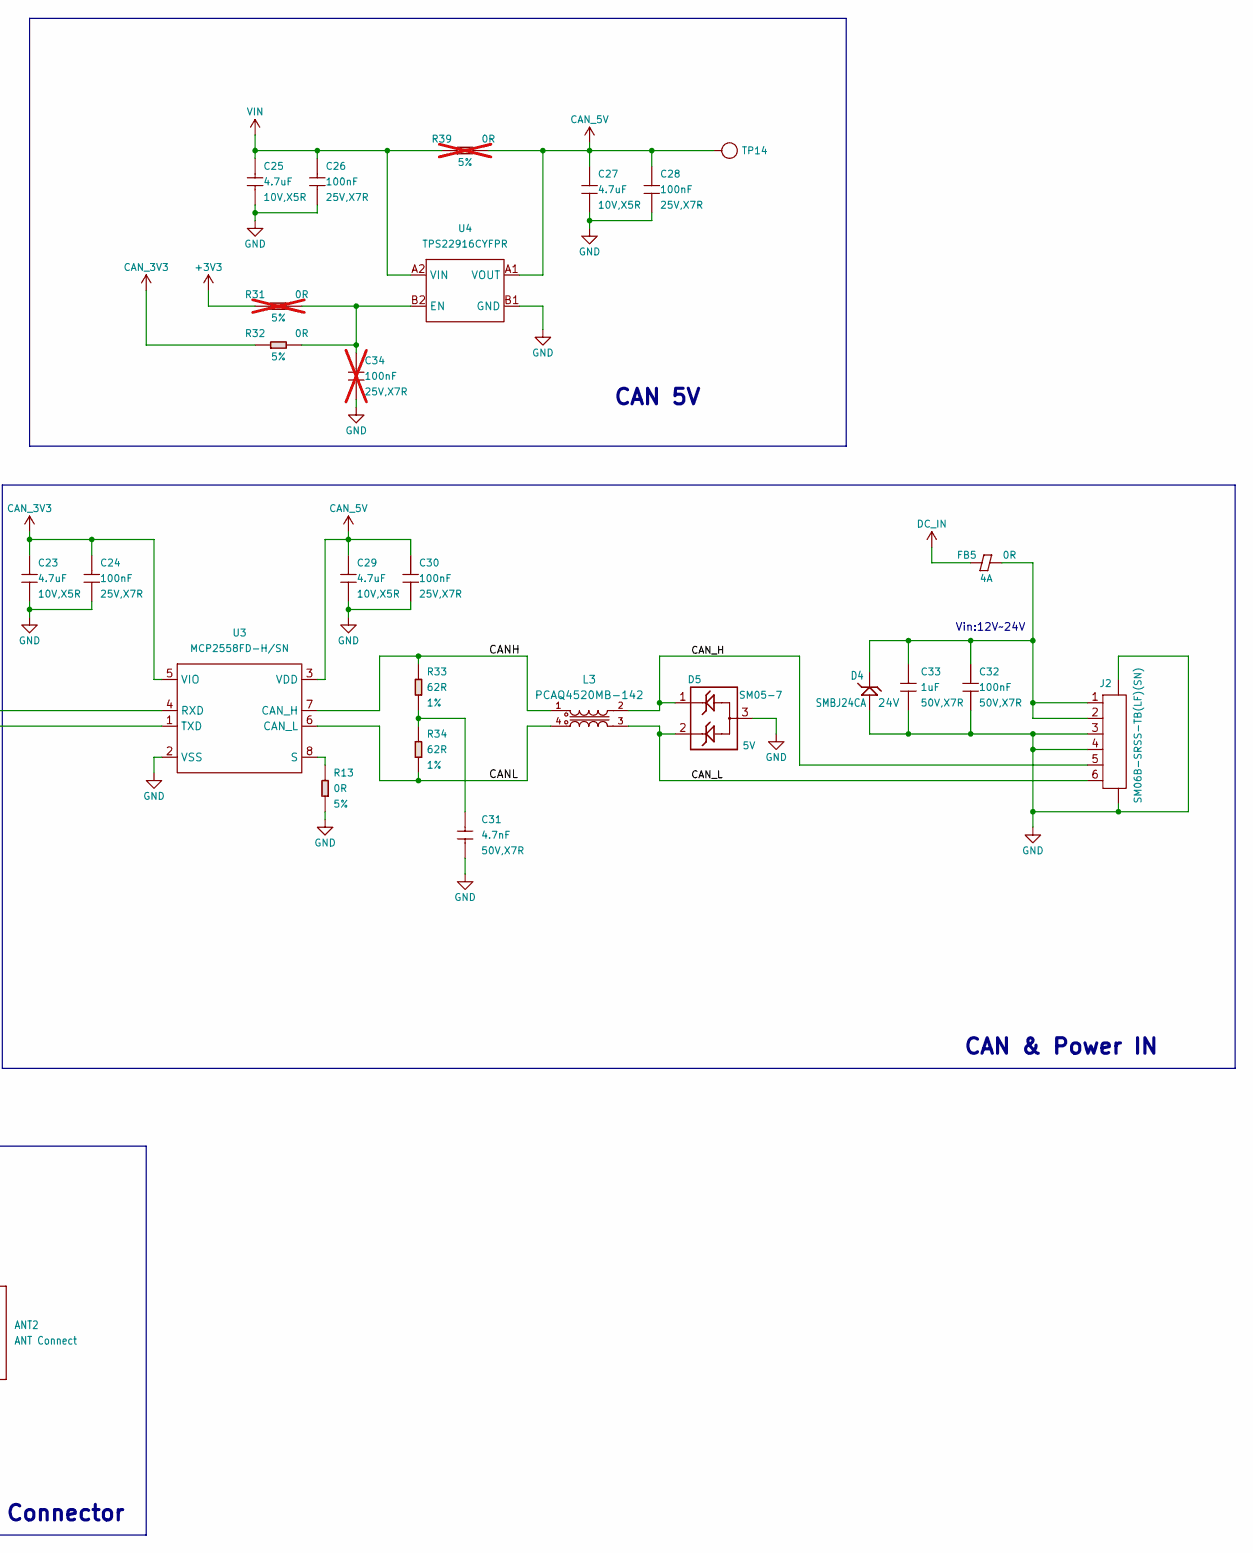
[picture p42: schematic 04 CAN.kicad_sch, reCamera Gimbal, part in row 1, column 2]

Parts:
ANT1: U.FL-R-SMT-1; U-FL3P-SMD-2.6X2.6X1.0MM; MPN U.FL-R-SMT-1
ANT2: ANT Connect; ANTENNA-5P-13.5X6.5X6.5MM; Part Type ANT
C12, C16, C18, C24, C26, C28, C30, C36: 100nF; C0402; Voltage Rating 25V,X7R; MPN CC0402KRX7R8BB104
C13, C19, C23, C25, C27, C29, C35: 4.7uF; C0603; Voltage Rating 10V,X5R; MPN CL10A475KP8NNNC
C17, C32: 100nF; C0603; Voltage Rating 50V,X7R; MPN CC0603KRX7R9BB104
C21, C22: 15pF; C0402; Voltage Rating 50V,NPO; MPN GRM1555C1H150JA01D
C31: 4.7nF; C0402; Voltage Rating 50V,X7R; MPN CC0402KRX7R9BB472
C33: 1uF; C0805; Voltage Rating 50V,X7R; MPN CC0805KKX7R9BB105
C34: 100nF; C0402; Voltage Rating 25V,X7R; MPN CC0402KRX7R8BB104; not fitted
D4: SMBJ24CA; DO-214AA_SMB; Rating 24V; MPN SMBJ24CA
D5: SM05-7; SOT-23; Rating 5V; MPN SM05-7
D6: TPD1E10B06DPYR; ESD-0402; Rating 5.5V; MPN TPD1E10B06DPYR
FB1: 120R; L0402; Rating 1.3A; MPN BLM15PD121SN1D
FB5: 0R; L0805; Rating 4A; MPN MPZ2012S101AT000
J2: SM06B-SRSS-TB(LF)(SN); SMD-SH1.0-6P-90D; MPN SM06B-SRSS-TB(LF)(SN)
J3: FF-1025; H4-2.54-65_35MIL; MPN FF-1025
L3: PCAQ4520MB-142; INT4-1.5-4.75X4.5X2MM; MPN PCAQ4520MB-142
Q1: LMUN5233T1G; SOT-323; Rating 50V,0.1A; MPN LMUN5233T1G; not fitted
Q2: CJ2101; SOT-323; Rating 20V 1.4A; MPN CJ2101; not fitted
R13, R20, R22, R23, R24, R25, R26, R32: 0R; R0402; Power Rating 5%; MPN RC0402JR-070RL
R16: 33K; R0402; Power Rating 1%; MPN RC0402FR-0733KL
R17: 47K; R0402; Power Rating 5%; MPN RC0402JR-0747KL
R18: 1K; R0402; Power Rating 1%; MPN RC0402FR-071KL
R19: 100K; R0402; Power Rating 1%; MPN RC0402FR-07100KL
R27, R28, R29: 4.7K; R0402; Power Rating 1%; MPN RC0402FR-074K7L; not fitted
R30: 1M; R0402; Power Rating 1%; MPN RC0402FR-071ML; not fitted
R31, R39: 0R; R0402; Power Rating 5%; MPN RC0402JR-070RL; not fitted
R33, R34: 62R; R0805; Power Rating 1%; MPN RC0805FR-0762RL
TP11, TP12, TP13, TP14, TP15: Test Point; TP-D45MIL; Part Type Test Point
U2: MCP2518FDT-E/QBB; VDFN14-0.65-4.5X3X0.85MM; MPN MCP2518FDT-E/QBB
U3: MCP2558FD-H/SN; SOIC8-1.27-5X4MM; MPN MCP2558FD-H/SN
U4: TPS22916CYFPR; WLCSP4-0.4-0.77X0.77X0.33MM; MPN TPS22916CYFPR
X1: 40MHz; X4-SMD-2.0X1.6MM; Rating 10ppm; MPN Y4000Fc001

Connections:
+3V3: C12.1, Q2.2 (S), R16.2, R20.1, R31.1, TP15.1 (T); also elsewhere on the board
/04 CAN/CANH: L3.1, R33.2, U3.7 (CAN_H)
/04 CAN/CANL: L3.4, R34.1, U3.6 (CAN_L)
/04 CAN/CAN_H: D5.1, J2.5, J3.2, L3.2
/04 CAN/CAN_L: D5.2, J2.6, J3.3, L3.3
/04 CAN/RF_LINE: ANT1.1 (D), ANT2.1 (ANT)
CAN_3V3: C18.1, C19.1, C23.1, C24.1, C35.1, C36.1, FB1.2, R27.2, R28.2, R29.2, R32.1, TP12.1 (T), U2.14 (VDD), U3.5 (VIO)
CAN_5V: C17.1, C27.1, C28.1, C29.1, C30.1, D6.2, J3.1, R39.2, TP14.1 (T), U3.3 (VDD), U4.A1 (VOUT)
DC_IN: FB5.1; also elsewhere on the board
GND: ANT1.2 (GND1), ANT1.3 (GND2), ANT2.2 (5), ANT2.3 (4), ANT2.4 (3), ANT2.5 (2), C13.2, C16.2, C17.2, C18.2, C19.2, C21.2, C22.2, C23.2, C24.2, C25.2, C26.2, C27.2, C28.2, C29.2, C30.2, C31.2, C32.2, C33.2, C34.2, C35.2, C36.2, D4.1 (+), D5.3, D6.1, J2.3, J2.4, J2.7, J2.8, J3.4, Q1.2 (E), R13.1, R19.1, TP13.1 (T), U2.7 (VSS), U2.15 (EP), U3.2 (VSS), U4.B1 (GND), X1.2, X1.4; also elsewhere on the board
GPIO12: R26.1; also elsewhere on the board
unnamed: C31.1, R33.1, R34.2
unnamed: C32.1, C33.1, D4.2 (-), FB5.2, J2.1, J2.2
unnamed: Q1.3 (C), R16.1, R17.1, R18.1
unnamed: C12.2, Q2.1 (G), R17.2
unnamed: C22.1, R30.2, U2.6 (OSC1), X1.3
unnamed: C21.1, R30.1, U2.5 (OSC2), X1.1
unnamed: U2.2 (RXCAN), U3.4 (RXD)
unnamed: R22.2, U2.10 (SCK)
unnamed: R24.2, U2.11 (SDI)
unnamed: R25.2, U2.12 (SDO)
unnamed: U2.1 (TXCAN), U3.1 (TXD)
unnamed: R23.2, U2.13 (nCS)
unnamed: R26.2, U2.4 (~INT)
unnamed: R13.2, U3.8 (S)
unnamed: C34.1, R31.2, R32.2, U4.B2 (EN)
SD0_PWR_3V3: C13.1, C16.1, FB1.1, Q2.3 (D), R19.2, R20.2, TP11.1 (T)
SD0_PWR_EN: Q1.1 (B), R18.2; also elsewhere on the board
SDIO_CLK/3V3: R22.1; also elsewhere on the board
SDIO_CMD/3V3: R24.1, R27.1; also elsewhere on the board
SDIO_D0/3V3: R25.1, R28.1; also elsewhere on the board
SDIO_D3/3V3: R23.1, R29.1; also elsewhere on the board
VIN: C25.1, C26.1, R39.1, U4.A2 (VIN); also elsewhere on the board

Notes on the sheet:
Layout Note: 50R
ANT Connector
SPI to CAN
Expanded Header
CAN 3V3
CAN 5V
Vin:12V~24V
CAN & Power IN

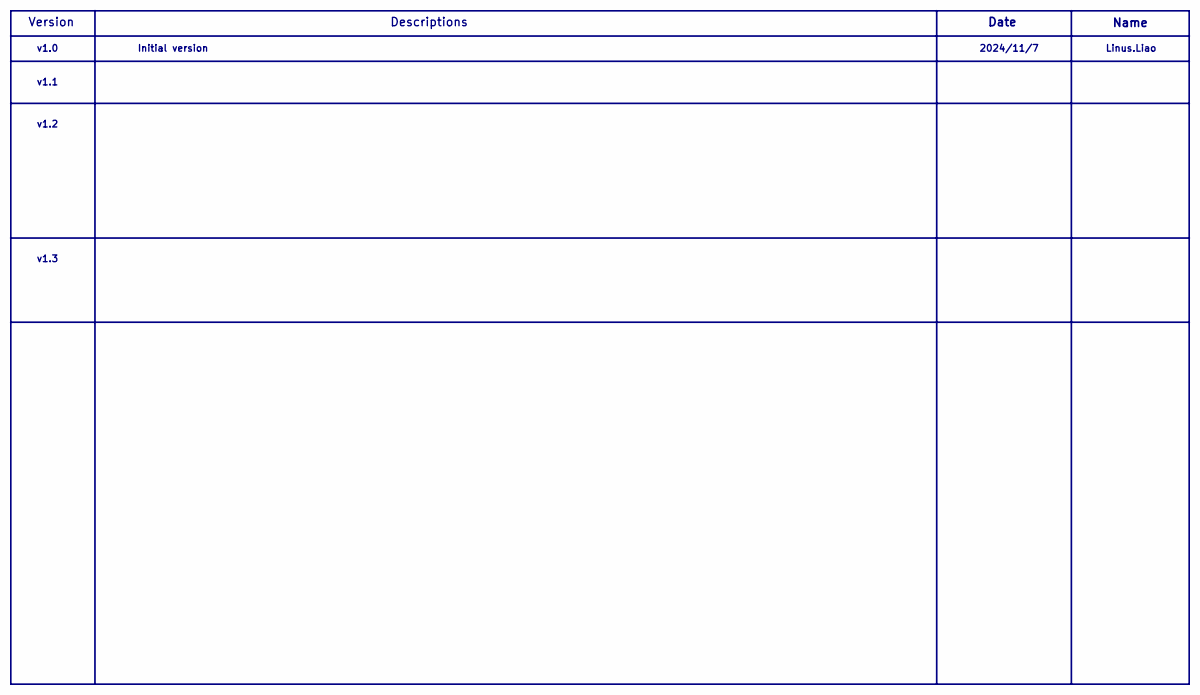
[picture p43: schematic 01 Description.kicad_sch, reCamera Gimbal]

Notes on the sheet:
Date
Descriptions
Version
Name
v1.1
v1.0
v1.2
Linus.Liao
2024/11/7
Initial version
v1.3

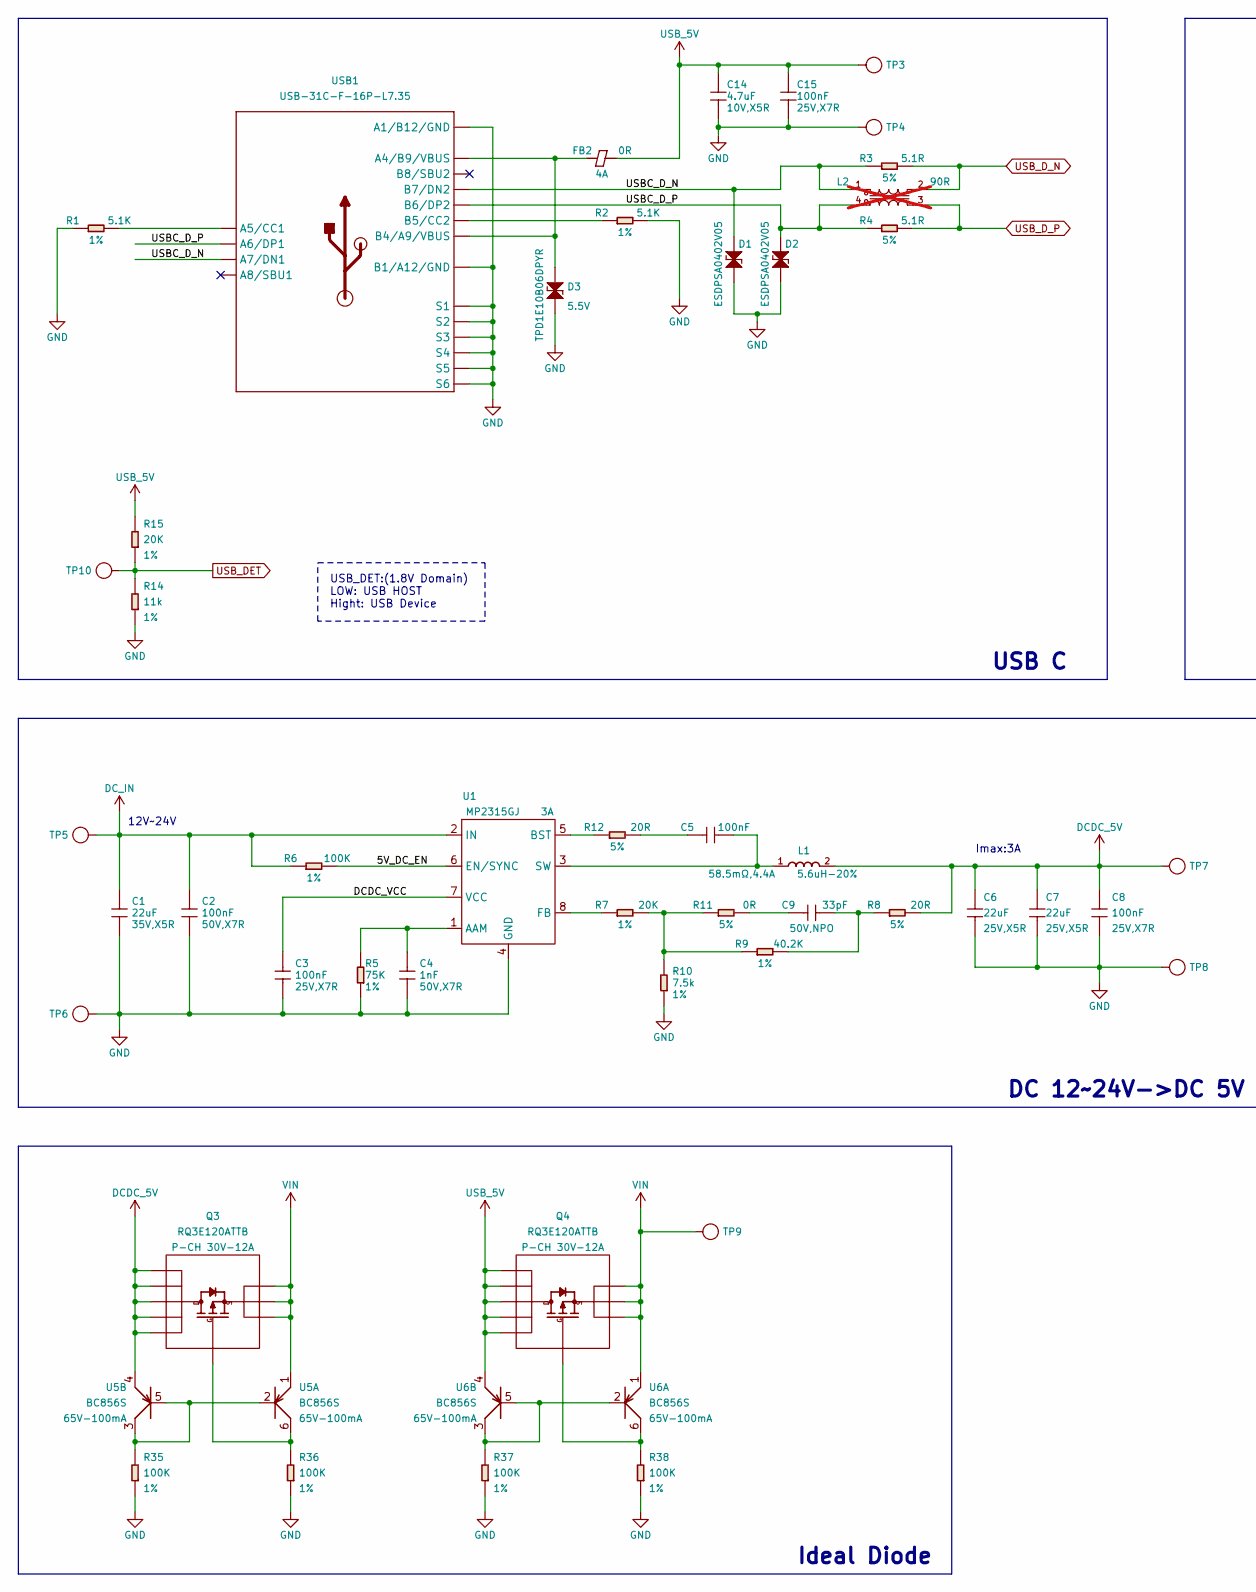
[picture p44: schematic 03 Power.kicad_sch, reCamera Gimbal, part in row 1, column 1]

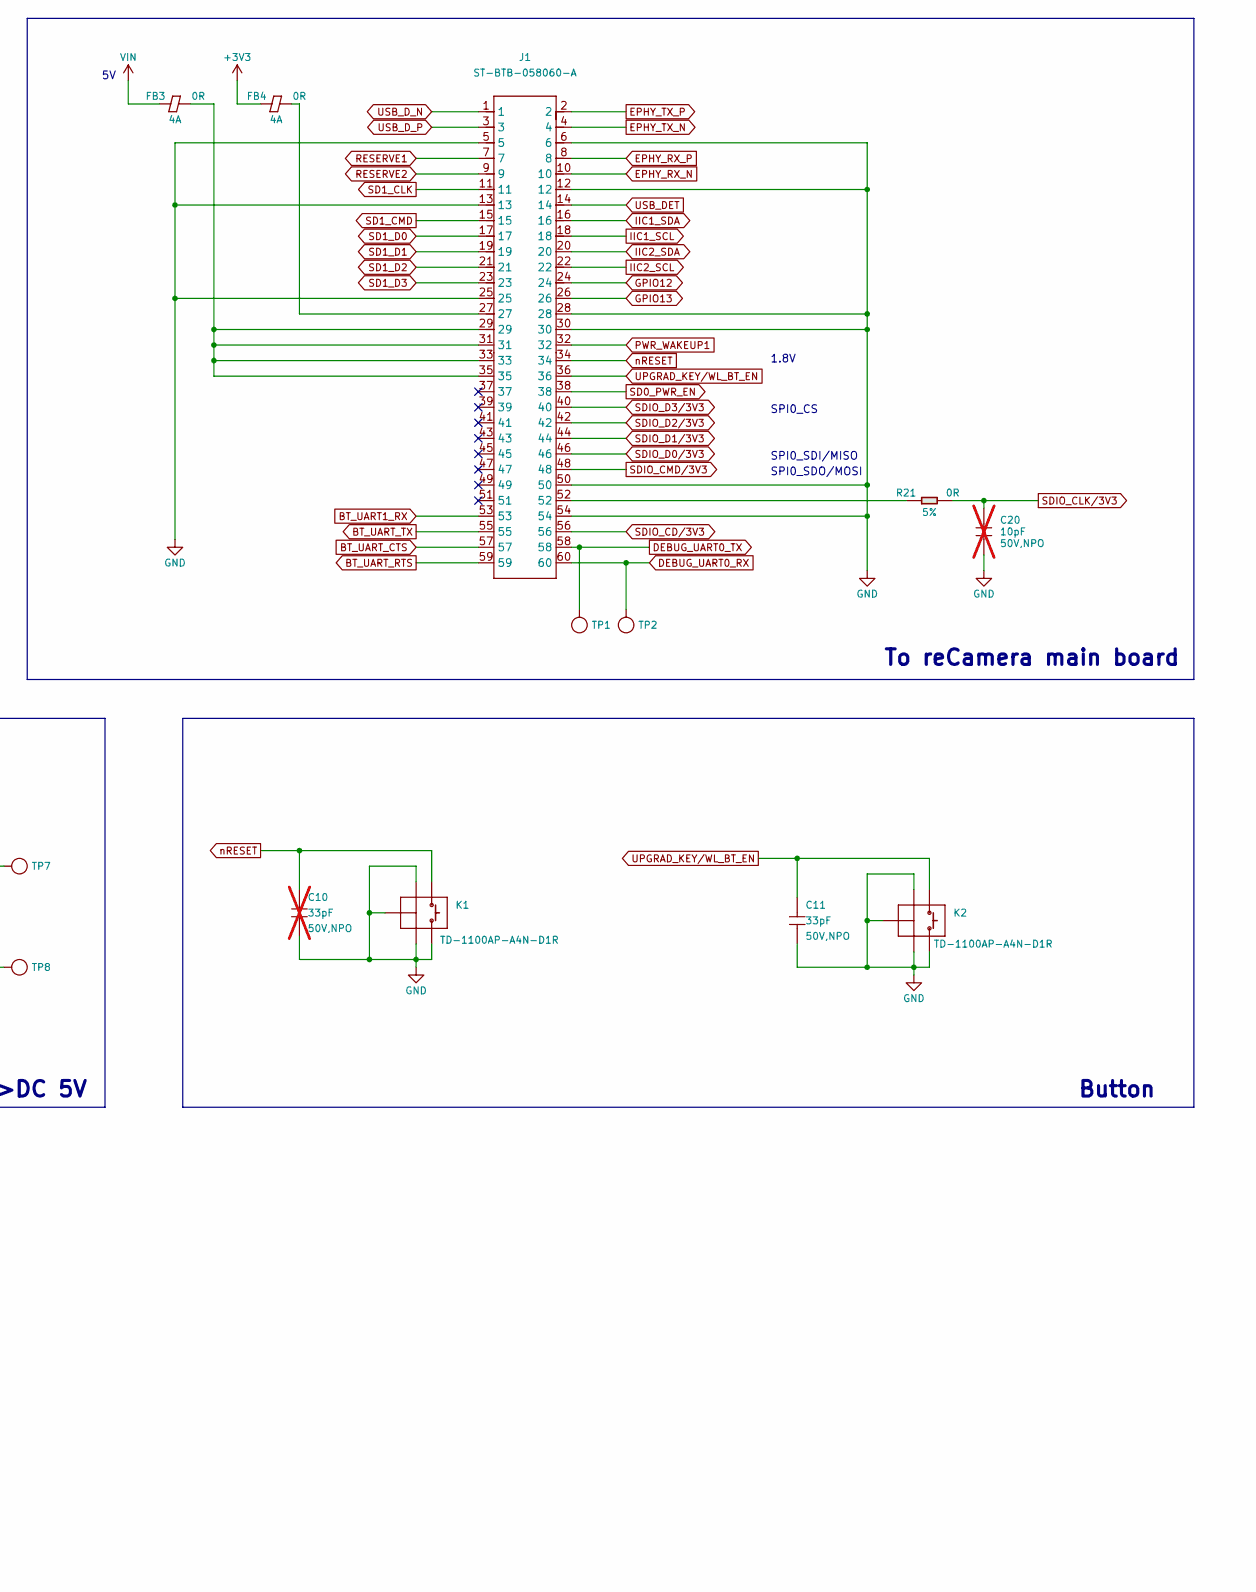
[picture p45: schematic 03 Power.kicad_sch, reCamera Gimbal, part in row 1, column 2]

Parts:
C1: 22uF; C1210; Voltage Rating 35V,X5R; MPN GMK325BJ226MM-P
C2: 100nF; C0603; Voltage Rating 50V,X7R; MPN CC0603KRX7R9BB104
C3, C5, C8, C15: 100nF; C0402; Voltage Rating 25V,X7R; MPN CC0402KRX7R8BB104
C4: 1nF; C0402; Voltage Rating 50V,X7R; MPN CC0402KRX7R9BB102
C6, C7: 22uF; C0805; Voltage Rating 25V,X5R; MPN CL21A226MAYNNNE
C9, C11: 33pF; C0402; Voltage Rating 50V,NPO; MPN CC0402JRNPO9BN330
C10: 33pF; C0402; Voltage Rating 50V,NPO; MPN CC0402JRNPO9BN330; not fitted
C14: 4.7uF; C0603; Voltage Rating 10V,X5R; MPN CL10A475KP8NNNC
C20: 10pF; C0402; Voltage Rating 50V,NPO; MPN CC0402JRNPO9BN100; not fitted
D1, D2: ESDPSA0402V05; ESD-0402; MPN ESDPSA0402V05
D3: TPD1E10B06DPYR; ESD-0402; Rating 5.5V; MPN TPD1E10B06DPYR
FB2, FB3, FB4: 0R; L0805; Rating 4A; MPN MPZ2012S101AT000
J1: ST-BTB-058060-A; BTB60-Male-Female-0.5-17.7x4.4mm; MPN ST-BTB-058060-A
K1, K2: TD-1100AP-A4N-D1R; SW5-SMD-4.56X2.3X1.9MM; MPN TD-1100AP-A4N-D1R
L1: 5.6uH-20%; INT2-SMD-4.2X4.4X1.8MM; Rating 58.5mΩ,4.4A; MPN CSHB0430R-5R6M
L2: 90R; INT4-0.85-2X1.25X1.2MM; Rating 400mA; MPN SRF2012-900YA; not fitted
Q3, Q4: RQ3E120ATTB; DFN8P-0.65-3X3X0.8MM; Rating P-CH 30V-12A; MPN RQ3E120ATTB
R1, R2: 5.1K; R0402; Power Rating 1%; MPN RC0402FR-075K1L
R3, R4: 5.1R; R0402; Power Rating 5%; MPN RC0402JR-075R1L
R5: 75K; R0402; Power Rating 1%; MPN RC0402FR-0775KL
R6, R35, R36, R37, R38: 100K; R0402; Power Rating 1%; MPN RC0402FR-07100KL
R7, R15: 20K; R0402; Power Rating 1%; MPN RC0402FR-0720KL
R8, R12: 20R; R0402; Power Rating 5%; MPN RC0402JR-0720RL
R9: 40.2K; R0402; Power Rating 1%; MPN RC0402FR-0740K2L
R10: 7.5k; R0402; Power Rating 1%; MPN RC0402FR-077K5L
R11, R21: 0R; R0402; Power Rating 5%; MPN RC0402JR-070RL
R14: 11k; R0402; Power Rating 1%; MPN RC0402FR-0711KL
TP1, TP2, TP3, TP4, TP5, TP6, TP7, TP8, TP9, TP10: Test Point; TP-D45MIL; Part Type Test Point
U1: MP2315GJ; TSOT23-8; Rating 3A; MPN MP2315GJ
U5, U6: BC856S; SOT-363; Rating 65V-100mA; MPN BC856S
USB1: USB-31C-F-16P-L7.35; USB2.0-TYPE-C; MPN USB-31C-F-16P-L7.35

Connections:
+3V3: FB4.1; also elsewhere on the board
/03 Power/5V_DC_EN: R6.2, U1.6 (EN/SYNC)
/03 Power/DCDC_VCC: C3.1, U1.7 (VCC)
/03 Power/USBC_D_N: D1.2, L2.1, R3.1, USB1.A7 (A7/DN1), USB1.B7 (B7/DN2)
/03 Power/USBC_D_P: D2.2, L2.4, R4.1, USB1.A6 (A6/DP1), USB1.B6 (B6/DP2)
BT_UART1_RX: J1.53
BT_UART_CTS: J1.57
BT_UART_RTS: J1.59
BT_UART_TX: J1.55
DCDC_5V: C6.1, C7.1, C8.1, L1.2, Q3.5 (D1), Q3.6 (D2), Q3.7 (D3), Q3.8 (D4), Q3.9 (D5), R8.2, TP7.1 (T), U5.4
DC_IN: C1.1, C2.1, R6.1, TP5.1 (T), U1.2 (IN); also elsewhere on the board
DEBUG_UART0_RX: J1.60, TP2.1 (T)
DEBUG_UART0_TX: J1.58, TP1.1 (T)
EPHY_RX_N: J1.10
EPHY_RX_P: J1.8
EPHY_TX_N: J1.4
EPHY_TX_P: J1.2
GND: C1.2, C2.2, C3.2, C4.2, C6.2, C7.2, C8.2, C10.2, C11.2, C14.2, C15.2, C20.2, D1.1, D2.1, D3.1, J1.5, J1.6, J1.12, J1.13, J1.25, J1.28, J1.30, J1.50, J1.54, K1.2, K1.S1, K1.S2, K1.S3, K2.2, K2.S1, K2.S2, K2.S3, R1.1, R2.2, R5.1, R10.1, R14.1, R35.1, R36.1, R37.1, R38.1, TP4.1 (T), TP6.1 (T), TP8.1 (T), U1.4 (GND), USB1.A1_B12 (A1/B12/GND), USB1.B1_A12 (B1/A12/GND), USB1.S1, USB1.S2, USB1.S3, USB1.S4, USB1.S5, USB1.S6; also elsewhere on the board
GPIO12: J1.24; also elsewhere on the board
GPIO13: J1.26
IIC1_SCL: J1.18
IIC1_SDA: J1.16
IIC2_SCL: J1.22
IIC2_SDA: J1.20
unnamed: C5.1, R12.2
unnamed: C9.1, R11.2
unnamed: C9.2, R8.1, R9.2
unnamed: FB3.2, J1.29, J1.31, J1.33, J1.35
unnamed: FB4.2, J1.27
unnamed: J1.52, R21.1
unnamed: Q3.4 (G), R36.2, U5.6
unnamed: Q4.4 (G), R38.2, U6.6
unnamed: R7.2, R9.1, R10.2, R11.1
unnamed: R35.2, U5.2, U5.3, U5.5
unnamed: R37.2, U6.2, U6.3, U6.5
unnamed: C4.1, R5.2, U1.1 (AAM)
unnamed: R12.1, U1.5 (BST)
unnamed: R7.1, U1.8 (FB)
unnamed: C5.2, L1.1, U1.3 (SW)
unnamed: D3.2, FB2.1, USB1.A4_B9 (A4/B9/VBUS), USB1.B4_A9 (B4/A9/VBUS)
unnamed: R1.2, USB1.A5 (A5/CC1)
unnamed: R2.1, USB1.B5 (B5/CC2)
PWR_WAKEUP1: J1.32
RESERVE1: J1.7
RESERVE2: J1.9
SD0_PWR_EN: J1.38; also elsewhere on the board
SD1_CLK: J1.11
SD1_CMD: J1.15
SD1_D0: J1.17
SD1_D1: J1.19
SD1_D2: J1.21
SD1_D3: J1.23
SDIO_CD/3V3: J1.56
SDIO_CLK/3V3: C20.1, R21.2; also elsewhere on the board
SDIO_CMD/3V3: J1.48; also elsewhere on the board
SDIO_D0/3V3: J1.46; also elsewhere on the board
SDIO_D1/3V3: J1.44
SDIO_D2/3V3: J1.42
SDIO_D3/3V3: J1.40; also elsewhere on the board
UPGRAD_KEY/WL_BT_EN: C11.1, J1.36, K2.1
USB_5V: C14.1, C15.1, FB2.2, Q4.5 (D1), Q4.6 (D2), Q4.7 (D3), Q4.8 (D4), Q4.9 (D5), R15.2, TP3.1 (T), U6.4
USB_DET: J1.14, R14.2, R15.1, TP10.1 (T)
USB_D_N: J1.1, L2.2, R3.2
USB_D_P: J1.3, L2.3, R4.2
VIN: FB3.1, Q3.1 (S1), Q3.2 (S2), Q3.3 (S3), Q4.1 (S1), Q4.2 (S2), Q4.3 (S3), TP9.1 (T), U5.1, U6.1; also elsewhere on the board
nRESET: C10.1, J1.34, K1.1

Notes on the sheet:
SPI0_CS
To reCamera main board
12V~24V
DC 12~24V->DC 5V
USB C
Imax:3A
Button
SPI0_SDO/MOSI
SPI0_SDI/MISO
USB_DET:(1.8V Domain) LOW: USB HOST Hight: USB Device
1.8V
Ideal Diode

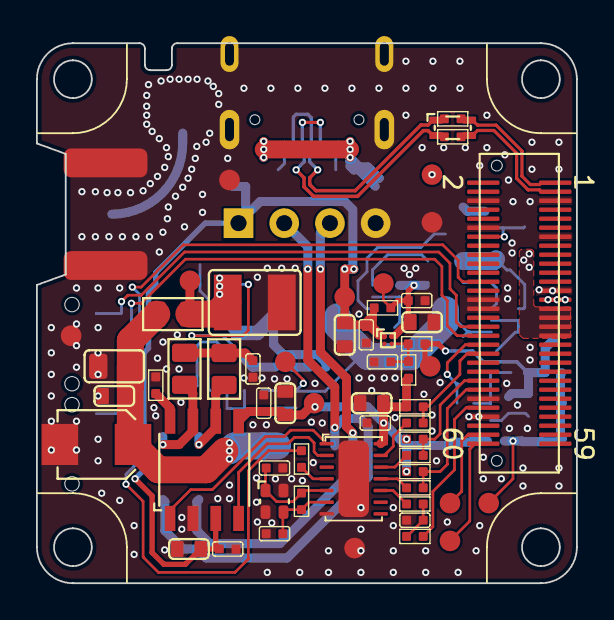
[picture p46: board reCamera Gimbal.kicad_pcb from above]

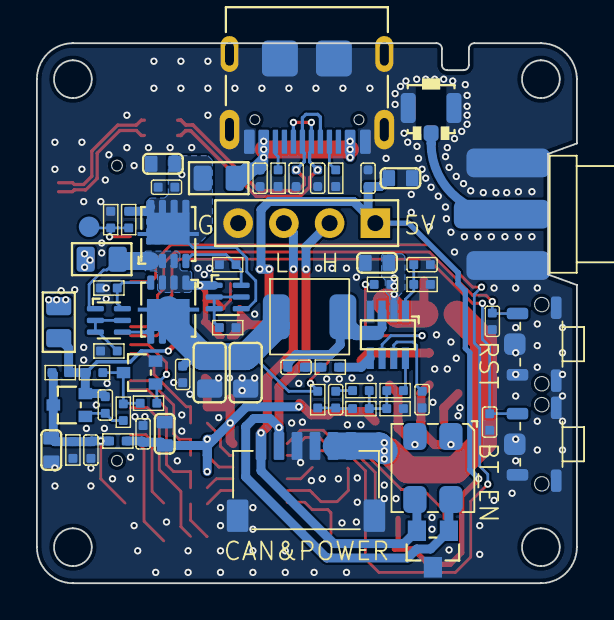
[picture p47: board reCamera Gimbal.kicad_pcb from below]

Board: 2 copper layers, 30.0 x 30.0 mm, 123 parts (65 on the bottom side), 64 nets.

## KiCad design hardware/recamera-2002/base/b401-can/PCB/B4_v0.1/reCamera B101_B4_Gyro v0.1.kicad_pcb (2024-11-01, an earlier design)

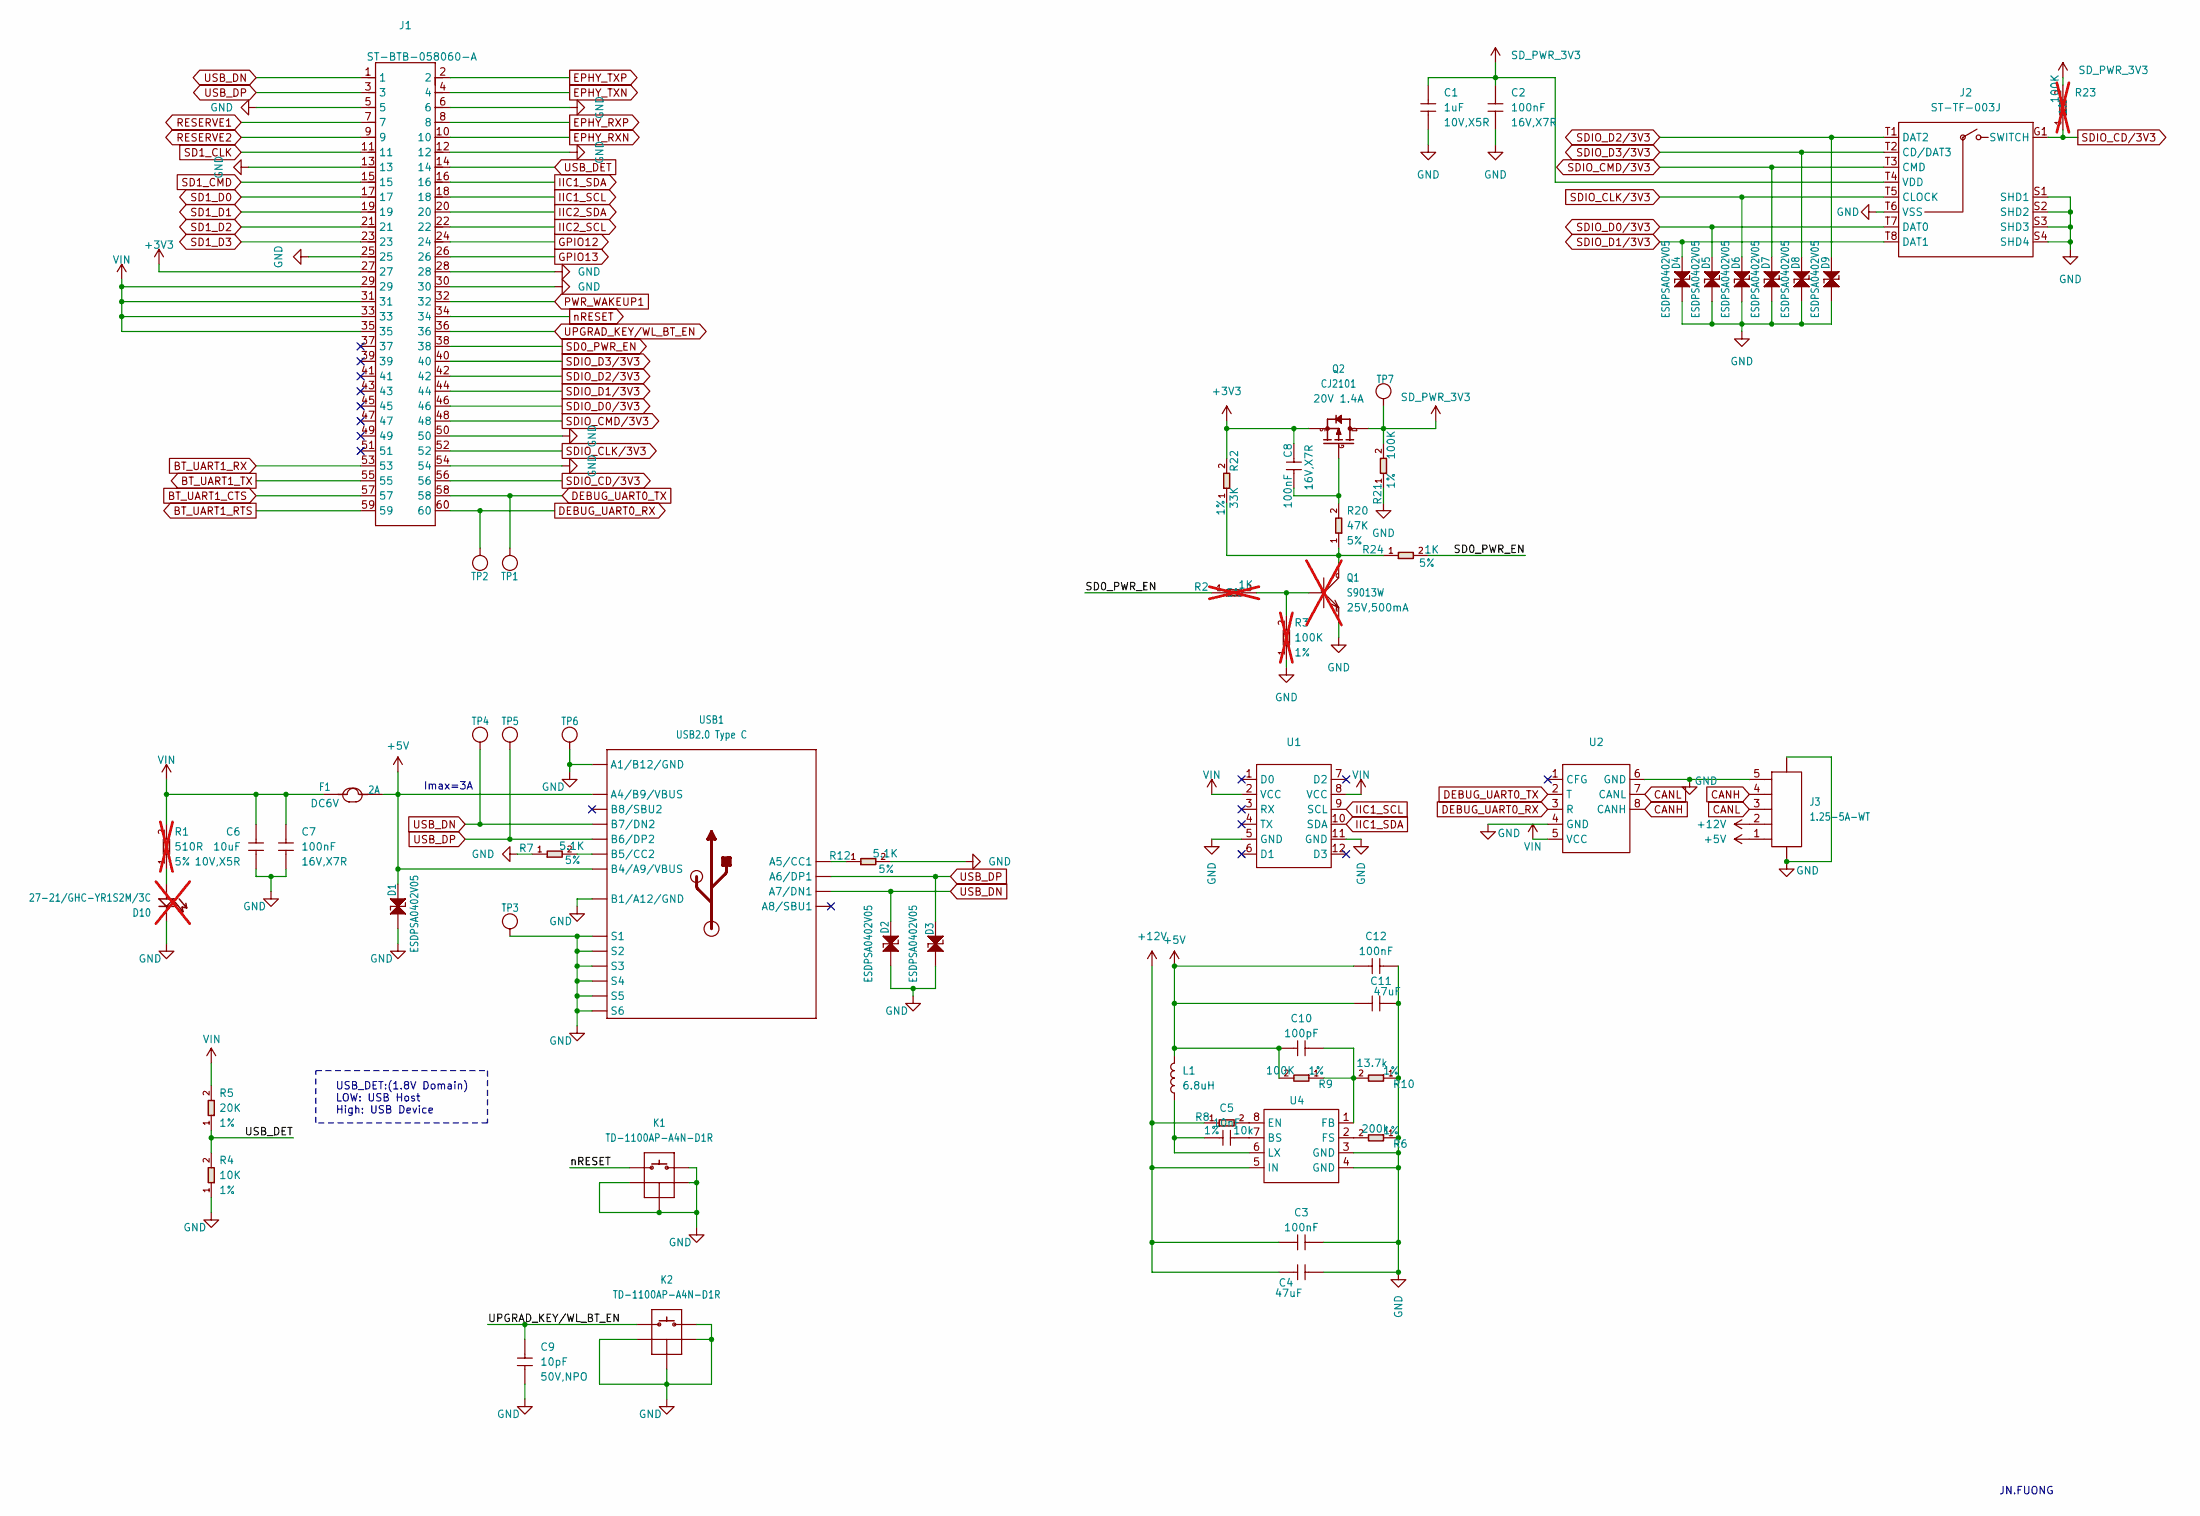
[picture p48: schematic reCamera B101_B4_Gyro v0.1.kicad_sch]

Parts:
C1: 1uF; C0402; Voltage Rating 10V,X5R; MPN CC0402KRX5R6BB105
C2, C3, C7, C8, C12: 100nF; C0402; Voltage Rating 16V,X7R; MPN CC0402KRX7R7BB104
C4, C11: 47uF; C0603; Voltage Rating 10V,X5R; MPN CC0603KRX5R6BB106
C5: 10nF; C0402; Voltage Rating 16V,X7R; MPN CC0402KRX7R7BB104
C6: 10uF; C0603; Voltage Rating 10V,X5R; MPN CC0603KRX5R6BB106
C9: 10pF; C0402; Voltage Rating 50V,NPO; MPN CC0402JRNPO9BN100
C10: 100pF; C0402; Voltage Rating 16V,X7R; MPN CC0402KRX7R7BB104
D1, D2, D3, D4, D5, D6, D7, D8, D9: ESDPSA0402V05; ESD-0402; MPN ESDPSA0402V05
D10: 27-21/GHC-YR1S2M/3C; LED2-0.6X1.7MM; MPN 27-21/GHC-YR1S2M/3C; not fitted
F1: 2A; F1210; Rating DC6V; MPN SMD1210R200SF
J1: ST-BTB-058060-A; BTB60-Male-Female-0.5-17.7x4.4mm; MPN ST-BTB-058060-A
J2: ST-TF-003J; MICRO-SD-CARD-9P; MPN ST-TF-003J
J3: 1.25-5A-WT; JST5_2P_1d25_7_9x4_3x3_4mm; MPN 1.25-5A-WT
K1, K2: TD-1100AP-A4N-D1R; SW5-SMD-4.56X2.3X1.9MM; MPN TD-1100AP-A4N-D1R
L1: 6.8uH
Q1: S9013W; SOT-323; Rating 25V,500mA; MPN S9013W; not fitted
Q2: CJ2101; SOT-323; Rating 20V 1.4A; MPN CJ2101
R1: 510R; R0402; Power Rating 5%; MPN RC0402JR-07510RL; not fitted
R2: 1K; R0402; Power Rating 5%; MPN RC0402JR-071KL; not fitted
R3, R23: 100K; R0402; Power Rating 1%; MPN RC0402FR-07100KL; not fitted
R4: 10K; R0402; Power Rating 1%; MPN RC0402FR-0710KL
R5: 20K; R0402; Power Rating 1%; MPN RC0402FR-0720KL
R6: 200k; R0402; Power Rating 1%; MPN RC0402FR-07100KL
R7, R12: 5.1K; R0402; Power Rating 5%; MPN RC0402JR-075K1L
R8: 10k; R0402; Power Rating 1%; MPN RC0402FR-07100KL
R9, R21: 100K; R0402; Power Rating 1%; MPN RC0402FR-07100KL
R10: 13.7k; R0402; Power Rating 1%; MPN RC0402FR-07100KL
R20: 47K; R0402; Power Rating 5%; MPN RC0402JR-0747KL
R22: 33K; R0402; Power Rating 1%; MPN RC0402FR-0733KL
R24: 1K; R0402; Power Rating 5%; MPN RC0402JR-071KL
TP1, TP2, TP3, TP4, TP5, TP6, TP7: Test Point; TP-D35MIL; Part Type Test Point
U1: WT9011G4K
U2: TTL-CAN
U4: SY8303AIC
USB1: USB2.0 Type C; USB2.0-TYPE-C; MPN UBF31-0171

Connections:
+3V3: C8.1, J1.27, Q2.2 (S), R22.2
+5V: C10.1, C11.1, C12.1, D1.1, F1.2, J3.1, L1.2, R9.2, USB1.A4_B9 (A4/B9/VBUS), USB1.B4_A9 (B4/A9/VBUS)
+12V: C3.1, C4.1, J3.2, R8.1, U4.5 (IN)
BT_UART1_CTS: J1.57
BT_UART1_RTS: J1.59
BT_UART1_RX: J1.53
BT_UART1_TX: J1.55
CANH: J3.4, U2.8 (CANH)
CANL: J3.3, U2.7 (CANL)
DEBUG_UART0_RX: J1.60, TP2.1 (T), U2.3 (R)
DEBUG_UART0_TX: J1.58, TP1.1 (T), U2.2 (T)
EPHY_RXN: J1.10
EPHY_RXP: J1.8
EPHY_TXN: J1.4
EPHY_TXP: J1.2
GND: C1.2, C2.2, C3.2, C4.2, C6.2, C7.2, C9.2, C11.2, C12.2, D1.2, D2.2, D3.2, D4.2, D5.2, D6.2, D7.2, D8.2, D9.2, D10.2 (-), J1.5, J1.6, J1.12, J1.13, J1.25, J1.28, J1.30, J1.50, J1.54, J2.S1 (SHD1), J2.S2 (SHD2), J2.S3 (SHD3), J2.S4 (SHD4), J2.T6 (VSS), J3.5, J3.6, J3.7, K1.2, K1.S1, K1.S2, K1.S3, K2.2, K2.S1, K2.S2, K2.S3, Q1.2 (E), R3.1, R4.1, R6.1, R7.1, R10.1, R12.2, R21.1, TP3.1 (T), TP6.1 (T), U1.5 (GND), U1.11 (GND), U2.4 (GND), U2.6 (GND), U4.3 (GND), U4.4 (GND), USB1.A1_B12 (A1/B12/GND), USB1.B1_A12 (B1/A12/GND), USB1.S1, USB1.S2, USB1.S3, USB1.S4, USB1.S5, USB1.S6
GPIO12: J1.24
GPIO13: J1.26
IIC1_SCL: J1.18, U1.9 (SCL)
IIC1_SDA: J1.16, U1.10 (SDA)
IIC2_SCL: J1.22
IIC2_SDA: J1.20
unnamed: D10.1 (+), R1.1
unnamed: Q1.1 (B), R2.2, R3.2
unnamed: Q1.3 (C), R20.1, R22.1, R24.1
unnamed: C8.2, Q2.1 (G), R20.2
unnamed: C5.2, U4.7 (BS)
unnamed: R8.2, U4.8 (EN)
unnamed: C10.2, R9.1, R10.2, U4.1 (FB)
unnamed: R6.2, U4.2 (FS)
unnamed: C5.1, L1.1, U4.6 (LX)
unnamed: R12.1, USB1.A5 (A5/CC1)
unnamed: R7.2, USB1.B5 (B5/CC2)
PWR_WAKEUP1: J1.32
RESERVE1: J1.7
RESERVE2: J1.9
SD0_PWR_EN: J1.38, R2.1, R24.2
SD1_CLK: J1.11
SD1_CMD: J1.15
SD1_D0: J1.17
SD1_D1: J1.19
SD1_D2: J1.21
SD1_D3: J1.23
SDIO_CD/3V3: J1.56, J2.G1 (SWITCH), R23.1
SDIO_CLK/3V3: D6.1, J1.52, J2.T5 (CLOCK)
SDIO_CMD/3V3: D7.1, J1.48, J2.T3 (CMD)
SDIO_D0/3V3: D5.1, J1.46, J2.T7 (DAT0)
SDIO_D1/3V3: D4.1, J1.44, J2.T8 (DAT1)
SDIO_D2/3V3: D9.1, J1.42, J2.T1 (DAT2)
SDIO_D3/3V3: D8.1, J1.40, J2.T2 (CD/DAT3)
SD_PWR_3V3: C1.1, C2.1, J2.T4 (VDD), Q2.3 (D), R21.2, R23.2, TP7.1 (T)
UPGRAD_KEY/WL_BT_EN: C9.1, J1.36, K2.1
USB_DET: J1.14, R4.2, R5.1
USB_DN: D2.1, J1.1, TP4.1 (T), USB1.A7 (A7/DN1), USB1.B7 (B7/DN2)
USB_DP: D3.1, J1.3, TP5.1 (T), USB1.A6 (A6/DP1), USB1.B6 (B6/DP2)
VIN: C6.1, C7.1, F1.1, J1.29, J1.31, J1.33, J1.35, R1.2, R5.2, U1.2 (VCC), U1.8 (VCC), U2.5 (VCC)
nRESET: J1.34, K1.1

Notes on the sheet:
JN.FUONG
USB_DET:(1.8V Domain) LOW: USB Host High: USB Device
Imax=3A

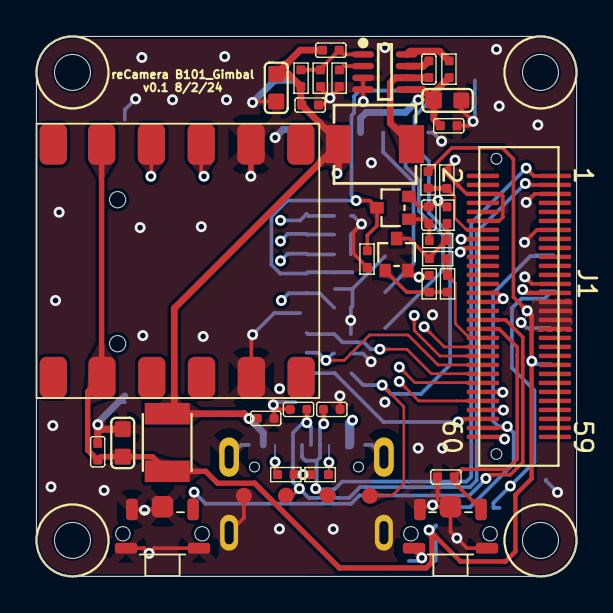
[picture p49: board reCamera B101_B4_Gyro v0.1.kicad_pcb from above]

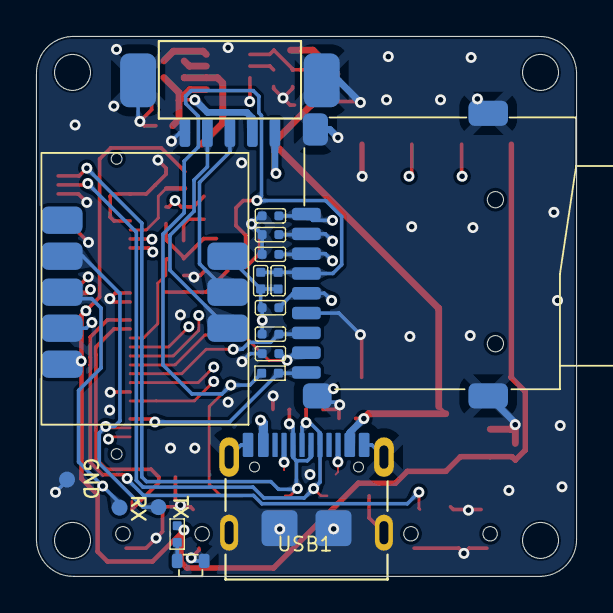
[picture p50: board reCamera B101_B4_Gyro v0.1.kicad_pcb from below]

Board: 4 copper layers, 30.0 x 30.0 mm, 58 parts (18 on the bottom side), 36 nets.

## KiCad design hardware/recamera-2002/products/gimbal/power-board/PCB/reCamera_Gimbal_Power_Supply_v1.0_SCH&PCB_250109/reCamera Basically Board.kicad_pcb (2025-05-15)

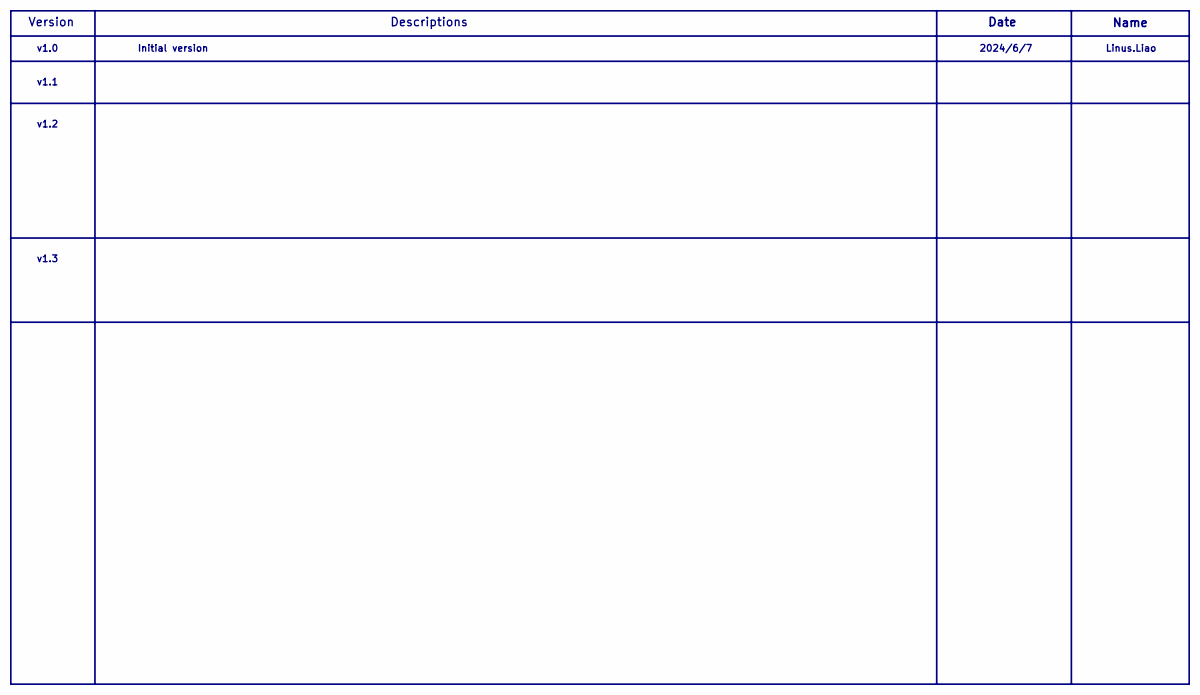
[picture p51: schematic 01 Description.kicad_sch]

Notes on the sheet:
Date
Descriptions
Version
Name
v1.1
v1.0
v1.2
Linus.Liao
2024/6/7
Initial version
v1.3

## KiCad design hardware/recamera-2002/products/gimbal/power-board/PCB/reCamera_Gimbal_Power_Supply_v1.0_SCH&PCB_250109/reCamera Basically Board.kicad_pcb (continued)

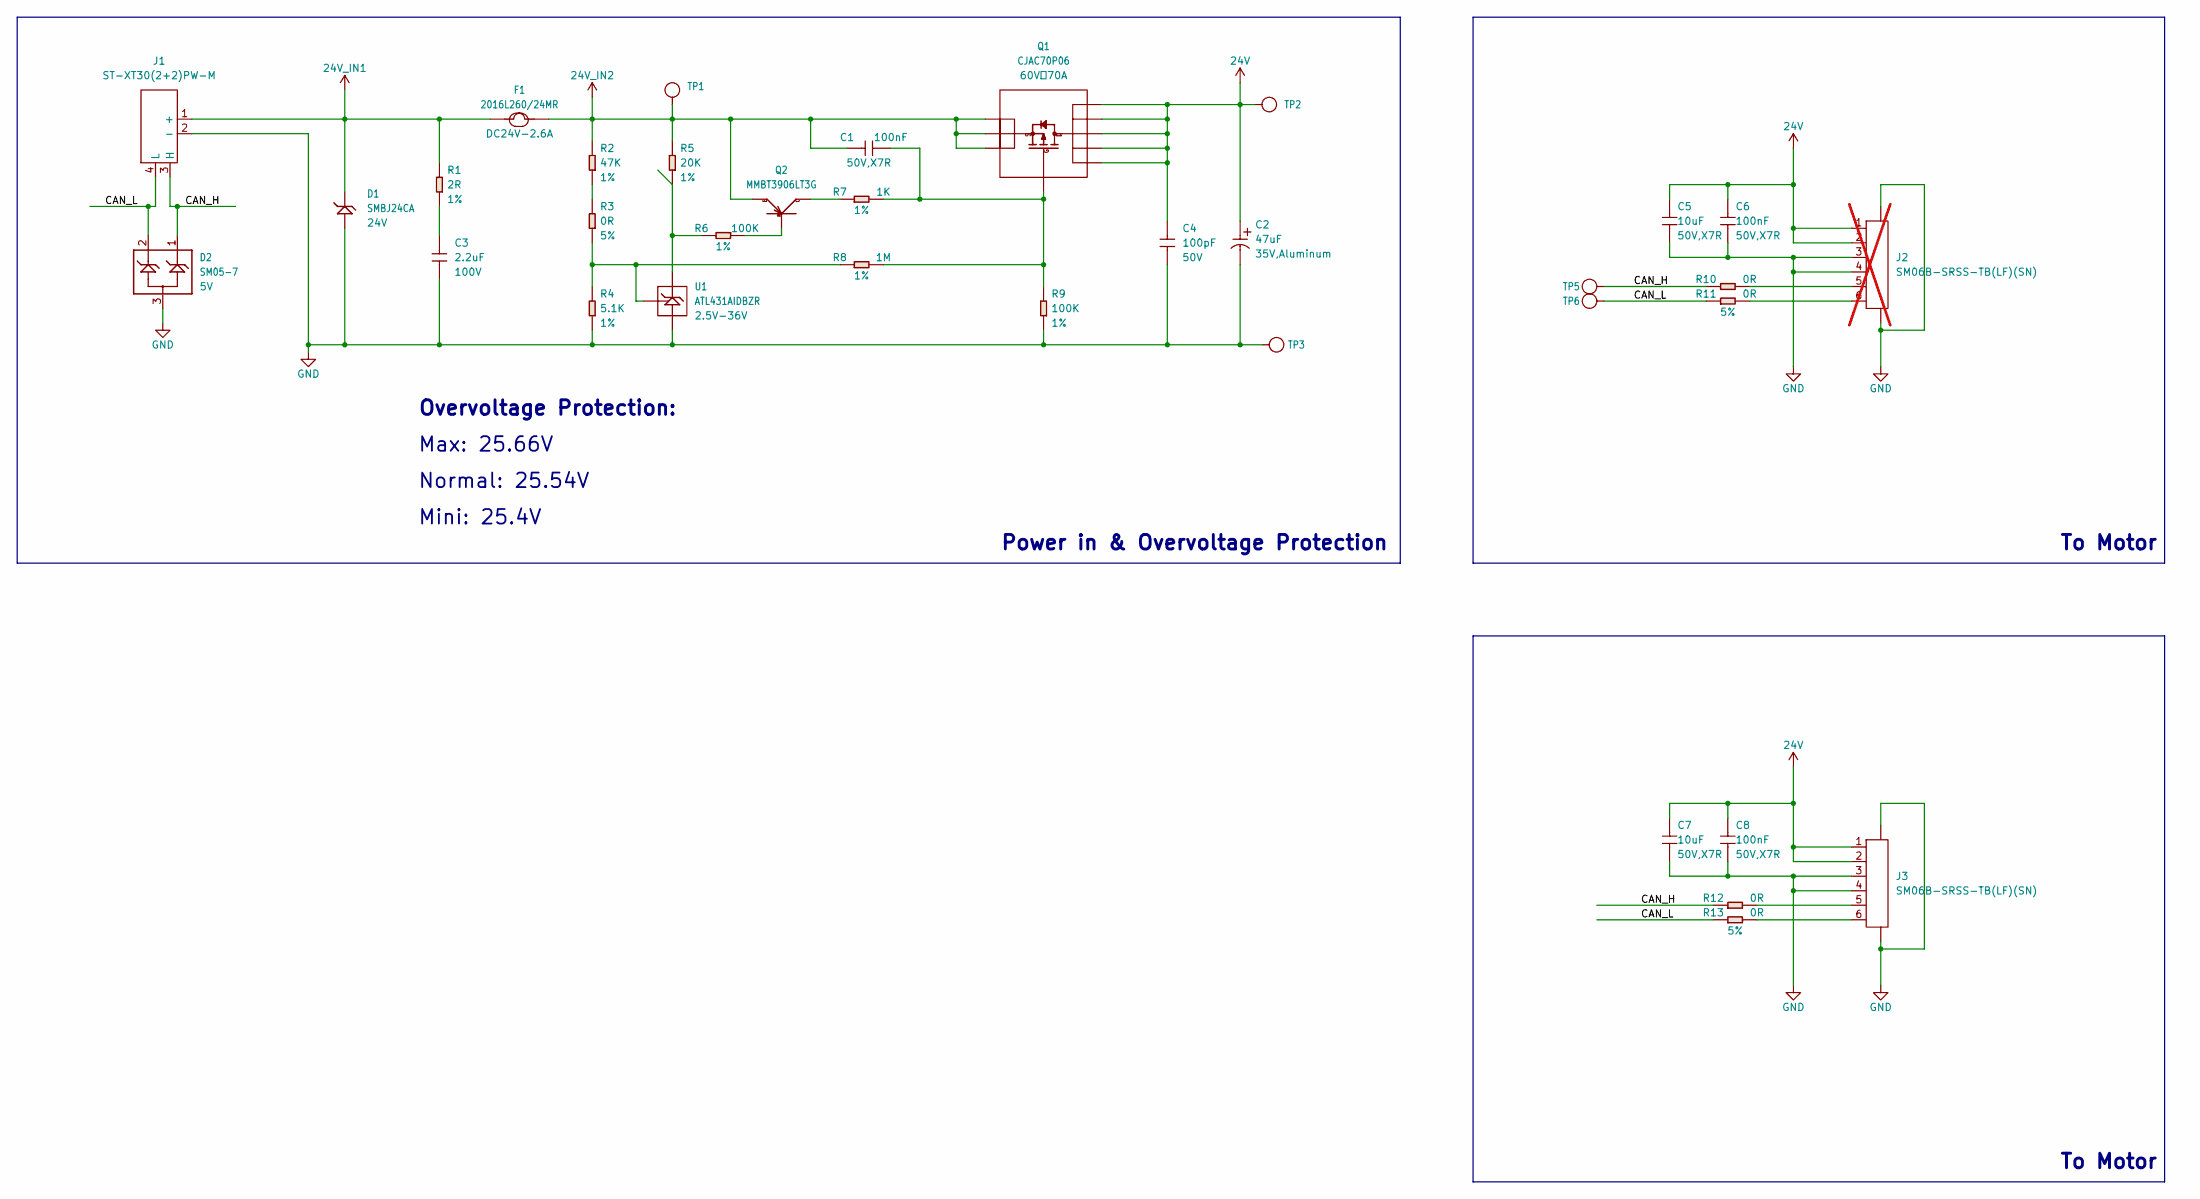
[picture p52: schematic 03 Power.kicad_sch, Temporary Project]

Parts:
C1, C6, C8: 100nF; C0603; Voltage Rating 50V,X7R; MPN CC0603KRX7R9BB104
C2: 47uF; ELECTRO-SMD-C-6MM; Voltage Rating 35V,Aluminum; MPN 35TZV47M6.3X6.1
C3: 2.2uF; C1210; Voltage Rating 100V; MPN CC1210KKX7R0BB225
C4: 100pF; C0402; Voltage Rating 50V; MPN CC0402JRNPO9BN101
C5, C7: 10uF; C1206; Voltage Rating 50V,X7R; MPN CL31B106KBHNNNE
D1: SMBJ24CA; DO-214AA_SMB; Rating 24V; MPN SMBJ24CA
D2: SM05-7; SOT-23; Rating 5V; MPN SM05-7
F1: 2016L260/24MR; F2016; Rating DC24V-2.6A; MPN 2016L260/24MR
J1: ST-XT30(2+2)PW-M; XT30-2+2P-15.5x12.5x5.2mm; MPN ST-XT30(2+2)PW-M
J2: SM06B-SRSS-TB(LF)(SN); SMD-SH1.0-6P-90D; MPN SM06B-SRSS-TB(LF)(SN); not fitted
J3: SM06B-SRSS-TB(LF)(SN); SMD-SH1.0-6P-90D; MPN SM06B-SRSS-TB(LF)(SN)
Q1: CJAC70P06; PG-TDSON-8-1.27-6X5X1MM; Rating 60V，70A; MPN CJAC70P06
Q2: MMBT3906LT3G; SOT-23; MPN MMBT3906LT3G
R1: 2R; R2512; Power Rating 1%; MPN RC2512FK-072RL
R2: 47K; R0402; Power Rating 1%; MPN RC0402FR-0747KL
R3, R10, R11, R12, R13: 0R; R0402; Power Rating 5%; MPN RC0402JR-070RL
R4: 5.1K; R0402; Power Rating 1%; MPN RC0402FR-075K1L
R5: 20K; R0402; Power Rating 1%; MPN RC0402FR-0720KL
R6, R9: 100K; R0402; Power Rating 1%; MPN RC0402FR-07100KL
R7: 1K; R0402; Power Rating 1%; MPN RC0402FR-071KL
R8: 1M; R0402; Power Rating 1%; MPN RC0402FR-071ML
TP1, TP2, TP3, TP5, TP6: Test Point; TP-1.6MM-ROUND; Part Type Test Point
U1: ATL431AIDBZR; SOT-23; Rating 2.5V-36V; MPN ATL431AIDBZR

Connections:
24V: C2.1, C4.1, C5.1, C6.1, C7.1, C8.1, J2.1, J2.2, J3.1, J3.2, Q1.5 (D1), Q1.6 (D2), Q1.7 (D3), Q1.8 (D4), Q1.9 (D5), TP2.1 (T)
24V_IN1: D1.2 (-), F1.1, J1.1 (+), R1.2
24V_IN2: C1.1, F1.2, Q1.1 (S1), Q1.2 (S2), Q1.3 (S3), Q2.2 (E), R2.2, R5.2, TP1.1 (T)
/03 Power/CAN_H: D2.1, J1.3 (H), R10.1, R12.1, TP5.1 (T)
/03 Power/CAN_L: D2.2, J1.4 (L), R11.1, R13.1, TP6.1 (T)
GND: C2.2, C3.2, C4.2, C5.2, C6.2, C7.2, C8.2, D1.1 (+), D2.3, J1.2 (-), J2.3, J2.4, J2.7, J2.8, J3.3, J3.4, J3.7, J3.8, R4.1, R9.1, TP3.1 (T), U1.3 (+)
unnamed: C3.1, R1.1
unnamed: J2.5, R10.2
unnamed: J2.6, R11.2
unnamed: J3.5, R12.2
unnamed: J3.6, R13.2
unnamed: C1.2, Q1.4 (G), R7.2, R8.2, R9.2
unnamed: Q2.1 (B), R6.1
unnamed: Q2.3 (C), R7.1
unnamed: R2.1, R3.2
unnamed: R5.1, R6.2, U1.1 (-)
unnamed: R3.1, R4.2, R8.1, U1.2 (Vref)

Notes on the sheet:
To Motor
Normal: 25.54V
Max: 25.66V
Power in & Overvoltage Protection
Overvoltage Protection:
Mini: 25.4V



Board: 2 copper layers, 45.0 x 25.0 mm, 35 parts (30 on the bottom side), 17 nets.

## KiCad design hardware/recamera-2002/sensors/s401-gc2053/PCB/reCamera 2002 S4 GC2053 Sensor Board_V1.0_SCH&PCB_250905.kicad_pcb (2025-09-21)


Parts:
C1: 100pF; C0201; Voltage Rating 50V,NPO; MPN CC0201JRNPO9BN101
C2: 22uF; C0603; Voltage Rating 6.3V,X5R; MPN CC0603MRX5R5BB226
C3, C7, C8, C9, C21, C23, C28: 100nF; C0201; Voltage Rating 10V,X5R; MPN CC0201KRX5R6BB104
C4, C18, C19: 2.2uF; C0402; Voltage Rating 6.3V,X5R; MPN CC0402MRX5R5BB225
C10, C22: 1uF; C0402; Voltage Rating 10V,X5R; MPN CC0402KRX5R6BB105
C15, C16, C17: 1uF; C0201; Voltage Rating 6.3V，X5R; MPN CC0201KRX5R5BB105
C20: 10uF; C0603; Voltage Rating 10V,X5R; MPN CC0603KRX5R6BB106
C24, C25: 1nF; C0201; Voltage Rating 16V,X7R; MPN CC0201KRX7R7BB102; not fitted
C26, C27: 100nF; C0201; Voltage Rating 10V,X5R; MPN CC0201KRX5R6BB104; not fitted
D5: Green; LED-0402; MPN BL-HGE37A-AV-TRB
D6: Red; LED-0402; MPN BL-HUB37A-AV-TRB
D7: Blue; LED-0402; MPN BL-HB337A-AV-TRB
J1: ST-BTB-058060-B; BTB60-Male-Female-0.5-17.7x4.4mm; MPN ST-BTB-058060-B
J2: DF30FC-24DS-0.4V; BTB2x12P_0d4_7_02x3_76x0_9mm; MPN DF30FC-24DS-0.4V
J3: 1.25-2A-WT; GH2-1.25-7.4X5.3X3.5MM; MPN 1.25-2A-WT
M1, M2: PTH_5X2MM; Part Type PTH
M3, M4: SMTSOM1.610BTR; M1.6-D3.18MM; MPN SMTSO2015CTJ; not fitted
MIC1: HMD-4013B423-CR1; MIC-5P-SMD-4X4MM; MPN HMD-4013B423-CR1
Q2, Q4, Q5, Q7, Q9: LBSS138WT1G; SOT-323; Rating 200mA; MPN LBSS138WT1G
Q3, Q6, Q8: CJ2101; SOT-323; Rating 20V 1.4A; MPN CJ2101
R1: 2.2K; R0201; Power Rating 1%; MPN RC0201FR-072K2L
R2: 2.2R; R0201; Power Rating 1%; MPN RC0201FR-072R2L
R3: 1.2K; R0201; Power Rating 1%; MPN RC0201FR-071K2L
R4: 680R; R0201; Power Rating 1%; MPN RC0201FR-07680RL
R6, R11: 4.7K; R0201; Power Rating 1%; MPN RC0201JR-074K7L
R7: 10K; R0201; Power Rating 1%; MPN RC0201FR-0710KL; not fitted
R8, R15: 10K; R0201; Power Rating 1%; MPN RC0201FR-0710KL
R9, R25, R26, R27, R29, R31, R33, R34, R35: 1K; R0201; Power Rating 1%; MPN RC0201FR-071KL
R12, R13: 30K; R0402; Power Rating 1%; MPN RC0402FR-0730KL
R14, R18: 0R; R0201; Power Rating 1%; MPN RC0201FR-070RL
R16, R17: 0R; R0402; Power Rating 5%; MPN RC0402JR-070RL
R22, R23, R24, R30, R36, R37: 100K; R0201; Power Rating 1%; MPN RC0201FR-07100KL
R28, R32: 47K; R0201; Power Rating 5%; MPN RC0201JR-0747KL
TP5, TP6, TP7, TP8, TP9, TP10, TP11, TP12: Test Point; TP-D35MIL; Part Type Test Point
U3: NS4150B; MSOP8-0.65-3X3X1MM; MPN NS4150B
X1: 9C24000004; X4-SMD-2.0X1.6MM; Rating 15ppm; MPN 9C24000004

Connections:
1V8: J1.49, J1.51, Q6.2 (S), R24.2
3V3: J1.57, J1.59, Q3.2 (S), Q8.2 (S), R4.2, R22.2, R36.2
/24MHz: J2.4, R18.2
AUD_AOUTR: C18.1, J1.44
AUD_MIC: C4.1, J1.40
AVDD: C7.1, C9.1, C15.1, C17.1, J2.12, J2.16, Q8.3 (D), TP12.1 (T)
CAM_1V8: C10.1, Q6.3 (D), R6.2, R11.2, TP11.1 (T), X1.4 (VDD)
CAM_EN: J1.48, R8.1, R9.2, R15.2, R25.1, R27.1, R35.1
CAM_I2C2_SCL: J1.9, J2.3, R11.1, TP10.1 (T)
CAM_I2C2_SDA: J1.11, J2.1, R6.1, TP9.1 (T)
CAM_RX0_0N: J1.16, J2.5
CAM_RX0_0P: J1.18, J2.7
CAM_RX0_1N: J1.22, J2.13
CAM_RX0_1P: J1.24, J2.15
CAM_RX0_3N: J1.28
CAM_RX0_3P: J1.30
CAM_RX0_4N: J1.4
CAM_RX0_4P: J1.6
CAM_RX0_CLKN: J1.10, J2.9
CAM_RX0_CLKP: J1.12, J2.11
GND: C1.2, C2.2, C3.2, C7.2, C8.2, C9.2, C10.2, C15.2, C16.2, C17.2, C19.1, C20.2, C21.2, C22.2, C23.2, C24.2, C25.2, C26.2, C27.2, C28.2, D5.2 (-), J1.2, J1.7, J1.8, J1.13, J1.14, J1.20, J1.26, J1.32, J1.33, J1.35, J1.36, J1.38, J1.42, J1.45, J1.46, J1.47, J1.53, J1.55, J2.2, J2.6, J2.8, J2.10, J2.17, J2.18, J2.19, J2.20, J2.21, J2.22, J2.23, J3.3, J3.4, M3.1, M4.1, MIC1.2 (-), MIC1.3 (-), MIC1.4 (-), Q2.2 (S), Q4.2 (S), Q5.2 (S), Q7.2 (S), Q9.2 (S), R3.1, R7.1, R23.1, R28.1, R30.1, R32.1, R37.1, TP7.1 (T), U3.7 (GND), X1.2 (GND)
GPIO15/IR_CUT: J1.34, R26.1
IOVDD: C8.1, C16.1, J2.14, Q3.3 (D), TP8.1 (T)
IR_PWM: J1.15, R31.1
LIGHT_SENSE: J1.17
unnamed: C2.1, C3.1, R1.1, R3.2, R4.1
unnamed: C4.2, R2.2
unnamed: C18.2, R12.1
unnamed: C19.2, R13.1
unnamed: D5.1 (+), R34.1
unnamed: D6.1 (+), R29.1
unnamed: D6.2 (-), Q4.3 (D)
unnamed: D7.1 (+), R33.1
unnamed: D7.2 (-), Q5.3 (D)
unnamed: J2.24, R7.2, R8.2
unnamed: C1.1, MIC1.1 (+), R1.2, R2.1
unnamed: Q2.3 (D), Q3.1 (G), R22.1
unnamed: C26.1, Q2.1 (G), R23.2, R25.2
unnamed: Q4.1 (G), R26.2, R28.2
unnamed: Q5.1 (G), R31.2, R32.2
unnamed: Q6.1 (G), Q7.3 (D), R24.1
unnamed: C27.1, Q7.1 (G), R27.2, R30.2
unnamed: Q8.1 (G), Q9.3 (D), R36.1
unnamed: C28.1, Q9.1 (G), R35.2, R37.2
unnamed: C24.1, J3.2, R17.2, TP5.1 (T)
unnamed: C25.1, J3.1, R16.2, TP6.1 (T)
unnamed: C23.1, U3.2 (Bypass)
unnamed: R15.1, U3.1 (CTRL)
unnamed: R13.2, U3.4 (INN)
unnamed: R12.2, U3.3 (INP)
unnamed: C20.1, C21.1, C22.1, R14.2, U3.6 (VCC)
unnamed: R16.1, U3.5 (VoN)
unnamed: R17.1, U3.8 (VoP)
unnamed: R18.1, X1.3 (CLK)
unnamed: R9.1, X1.1 (ENABLE)
RESERVE1: J1.3
RESERVE2: J1.1
VIN: J1.37, J1.39, J1.41, J1.43, R14.1, R29.2, R33.2, R34.2
WH_PWM: J1.5

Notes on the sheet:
Imax=300mA



Board: 4 copper layers, 30.0 x 30.0 mm, 83 parts (30 on the bottom side), 51 nets.

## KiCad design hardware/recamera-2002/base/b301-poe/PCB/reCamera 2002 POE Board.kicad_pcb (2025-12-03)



Board: 4 copper layers, 30.0 x 30.0 mm, 75 parts (37 on the bottom side), 47 nets.

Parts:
C2: 100uF; C1206
C3, C4, C7, C13: 100nF; C0402
C5, C10, C17: 1nF; C1206
C6, C16: 10uF; C0603
C9, C18: 10pF; C0402
C11: 100pF; C0402
C12: 47uF; C1206
C19: 10nF; C0603
C49, C50: 10nF; C0402
D1: SMF5.0CA; SOD-123
D2, D3: ESDPSA0402V05; ESD-0402
D4: 58V 600W; DO-214AA-SMB-NONPOLAR
D5, D6, D7, D8, D13: CESD3V3D5; SOD-523
D11, D12: UDD32C03L01; SOD-323
F1: 2A; F1210
FB1: 120R; L0603
J1: ST-BTB-058060-A; BTB60-Male-Female-0.5-17.7x4.4mm
J2: ST-FH-254-0106-1*2P-PC3.0; JST2P-2.54-5.58X2.5X3.5MM
J3: 1.25-5A-WT; JST5_2P_1d25_7_9x4_3x3_4mm
J4: ST-FH-254-0106-1*4P-PC3.0; JST4P-2.54-10.66X2.5X3.5MM
J5: 1.25-6A-LT; FPC6-1.25-12.5X3.7X4.65MM
K1, K2: TD-1100AP-A4N-D1R; SW5-SMD-4.56X2.3X1.9MM
L1: CMC4532H-102-2P-T; INT4-2.2-4.5X3.2X2.8MM
L3: 300mA; INT4-1.45-3.3X2.5X2.5MM
Q1, Q2: CJ3407; SOT23
R2, R34, R39, R40: 100K; R0402
R4: 10K; R0402
R5: 20K; R0402
R6: 1M; R1206
R7, R12: 5.1K; R0402
R8, R9, R16, R17: 0R; R0402
R13, R14: 75R; R0603
R18: 1K; R0603
R41, R43: 100R; R0402
T1: KHX1631SR; TRF_16p_1d27_12d7x7d15x5d1mm
TP1, TP2, TP3: Test Point; TP-80X40MIL
TP4, TP5, TP6, TP8, TP9, TP10, TP11, TP12, TP15: Test Point; TP-D35MIL
U9, U10: BC856S; SOT-363
USB1: ST-USB-Y3120; USB2.0-TYPE-C-SMD-12X7.35X3.3MM

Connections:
+5V: F1.2, TP8.1 (T), USB1.A4_B9 (A4/B9/VBUS), USB1.B4_A9 (B4/A9/VBUS)
/POE Board/DN: D2.1, R9.1, TP4.1 (T), USB1.A7 (A7/DN1), USB1.B7 (B7/DN2)
/POE Board/DP: D3.1, R8.1, TP5.1 (T), USB1.A6 (A6/DP1), USB1.B6 (B6/DP2)
/POE Board/PHYRXN: J3.1, T1.9
/POE Board/PHYRXP: J3.2, T1.11
/POE Board/PHYTXN: J3.3, T1.14
/POE Board/PHYTXP: J3.4, T1.16
/POE Board/POE_VIN+_ModeA: D4.2, L1.1, L3.1, R14.2, T1.15
/POE Board/POE_VIN-_ModeA: D4.1, L1.4, L3.2, R13.2, T1.10
DEBUG_UART0_RX: J1.60, TP2.1 (T)
DEBUG_UART0_TX: J1.58, TP1.1 (T)
EPHY_RXN: D12.1, J1.10, T1.8
EPHY_RXP: D12.2, J1.8, T1.6
EPHY_TXN: D11.1, J1.4, T1.3
EPHY_TXP: D11.2, J1.2, T1.1
GND: C2.2, C3.1, C4.1, C6.2, C7.2, C9.2, C10.1, C11.2, C12.2, C13.2, C16.2, C18.2, C49.2, C50.2, D1.1, D2.2, D3.2, D5.1 (+), D6.1 (+), D7.1 (+), D8.1 (+), D13.1 (+), J1.5, J1.6, J1.12, J1.13, J1.25, J1.28, J1.30, J1.50, J1.54, J2.1, J3.6, J3.7, J5.6, J5.7, J5.8, K1.2, K1.S1, K1.S2, K1.S3, K2.2, K2.S1, K2.S2, K2.S3, R2.1, R4.1, R6.2, R7.1, R12.2, R18.1, R34.1, R39.1, R40.1, TP3.1 (T), TP6.1 (T), TP11.1 (T), TP12.1 (T), USB1.A1_B12 (A1/B12/GND), USB1.B1_A12 (B1/A12/GND), USB1.S1, USB1.S2, USB1.S3, USB1.S4
GNDPWR: C5.2, C10.2, C17.2, J3.5, R6.1
unnamed: C3.2, T1.2
unnamed: C4.2, T1.7
unnamed: C5.1, R13.1
unnamed: C9.1, K2.1, R16.2
unnamed: C2.1, C12.1, C13.1, C16.1, FB1.2, J2.2, R18.2
unnamed: C17.1, R14.1
unnamed: C18.1, K1.1, R17.2
unnamed: C19.1, J4.1, L1.2, L3.4
unnamed: C19.2, J4.2, L1.3, L3.3
unnamed: C50.1, Q1.1 (G), R39.2, R43.1
unnamed: C49.1, Q2.1 (G), R2.2, R41.1
unnamed: R34.2, U9.2, U9.5, U9.6
unnamed: R40.2, U10.2, U10.5, U10.6
unnamed: R41.2, U9.3
unnamed: R43.2, U10.3
unnamed: R12.1, USB1.A5 (A5/CC1)
unnamed: R7.2, USB1.B5 (B5/CC2)
POE_VOUT_5V: FB1.1, Q2.3 (D), TP10.1 (T), U9.1
SDIO_CLK/3V3: D5.2 (-), J1.52, J5.4
SDIO_CMD/3V3: D13.2 (-), J1.48, J5.5
SDIO_D0/3V3: D6.2 (-), J1.46, J5.3
SDIO_D1/3V3: D7.2 (-), J1.44, J5.2
SDIO_D3/3V3: D8.2 (-), J1.40, J5.1
UPGRAD_KEY: J1.36, R16.1
USB_DET: J1.14, R4.2, R5.1
USB_DN: J1.1, R9.2
USB_DP: J1.3, R8.2
VIN: J1.29, J1.31, J1.33, J1.35, Q1.2 (S), Q2.2 (S), R5.2, TP9.1 (T), TP15.1 (T), U9.4, U10.4
VIN_5V: C6.1, C7.1, C11.1, D1.2, F1.1, Q1.3 (D), U10.1
nRESET: J1.34, R17.1

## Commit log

2024-08-01 docs: project structure init
    [reCamera S101 v1.0.kicad_pcb, reCamera S101 v1.0.kicad_sch, recamera-sensorcover-4040.prt]
2024-08-06 [doc] add standard boards readme
2024-08-07 [fix] change the camera name to OV5647
2024-08-07 [fix] add Model for OV5647 camera
    [recamera-sensorcover-4040.stl, recamera-sensorcover-4040.stp]
2024-08-15 Rename B1_Default/reCamera B101 v0.1.kicad_pro to B1_Default/PCB/reCamera B101 v0.1.kicad_pro
2024-08-15 chore: Update core board features and version info
2024-08-15 File structure changed
    [recamera_B1_Default.stp]
2024-08-15 picture change
    [reCamera B101_B3_Gyro v0.1.kicad_pcb, reCamera B101_B3_Gyro v0.1.kicad_sch, reCamera_B101_POE.kicad_pcb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]
2024-08-15 Update core board features and version info
2024-08-15 Upload the New Board
    [reCamera B101_B2_v0.1.kicad_pcb, reCamera B101_B2_v0.1.kicad_sch, reCamera B101_B4_Gyro v0.1.kicad_pcb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]
2024-08-22 [fix]add Sensor list
2024-08-23 Update and rename reCamera_B101_RJ45.kicad_pcb to reCamera_B101_POE.kicad_pcb
    [reCamera_B101_POE.kicad_pcb]
2024-08-23 Update and rename reCamera_B101_RJ45.kicad_sch to reCamera_B101_POE.kicad_sch
    [reCamera_B101_POE.kicad_sch]
2024-09-09 PoE Modified
    [reCamera_B101_B3_POE.kicad_pcb, reCamera_B101_B3_POE.kicad_sch]
2024-09-11 B101 V1.0 & V1.1
    [reCamera B101 v1.0.kicad_pcb, reCamera B101 v1.0.kicad_sch, reCamera B101 v1.1.kicad_pcb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]
2024-09-11 reCamera_pocket update
    [reCamera_Pocket_Horizontal.stp, reCamera_Pocket_vertical.stp]
2024-10-23 [fix]add C1 PCB files
    [01 Table of Contents.kicad_sch, 02 Block Diagram_sch.kicad_sch, 03 Power IN.kicad_sch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]
2024-11-01 Update C1, B1, S1
    [reCamera B101 v1.0.kicad_pcb, reCamera B101 v1.0.kicad_sch, reCamera B101 v1.1.kicad_pcb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]
2024-11-01 Change C1 Board file path
    [01 Table of Contents.kicad_sch, 02 Block Diagram_sch.kicad_sch, 03 Power IN.kicad_sch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]
2024-11-01 Update readme.md with social media sharing buttons and badges
2024-11-29 update B1 S1 C1 board image
2024-12-10 [fix]add Gimbal files
    [bottom-plate_10.stp, brushlessmotor-ms3008v2_2.stp, brushlessmotor-ms3506_4.stp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]
2024-12-11 [fix]change recamera Gimbal files
    [01 Description.kicad_sch, 03 Power.kicad_sch, 04 CAN.kicad_sch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]
2024-12-13 更新 recamera Gimbal 文件
2025-01-23 Add the roadmap.md document. Completed the Gimbal development related materials
2025-02-06 restructure the repository
    [01 Description.kicad_sch, 03 Power.kicad_sch, 04 CAN.kicad_sch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]
2025-02-12 Add 3D printed files for B2 and B3
    [B2_Vertical_Type-C.stp, B3_POE.stp, b2_vertical_type-c.stl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]
2025-02-12 change flow examples and read me
2025-02-21 Modify the motor protocol documentation.
2025-02-27 [fix] add gimbal dashboard flow
    [Motor_PID_Config.json]
2025-04-08 files modification
    [B2_Vertical_Type-C.stp, B3_POE.stp, Motor_PID_Config.json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]
2025-04-09 Modify some 3D printed files
    [B3_CAN.step, B3_CAN.stl, can-case_3.stp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]
2025-04-30 add core cooler 3D printed files
    [core_cooler.step, core_cooler.stl]
2025-05-15 add Gimbal Power supply board files
    [01 Description.kicad_sch, 03 Power.kicad_sch, reCamera Basically Board.kicad_pcb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]
2025-07-17 [fix] Add reCamera POE and GC2053 Sensor Information
2025-07-17 [fix] Add reCamera POE and GC2053 Sensor Information
2025-09-21 [fix] Added the PCB documents for Poe and GC2053. Added some YOLO11 models.
    [reCamera 2002 POE Board.kicad_pcb, reCamera 2002 POE Board.kicad_sch, reCamera 2002 S4 GC2053 Sensor Board_V1.0_SCH&PCB_250905.kicad_pcb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]
2025-10-23 [add] add reCamera_Microscope Project
    [top_2.3mf]
2025-12-03 更新了三张PCB
    [reCamera 2002 POE Board.kicad_pcb, reCamera 2002 POE Board.kicad_sch]
2026-01-13 更新了一张reCamera POE的PCB和原理图
2026-08-21 chore: establish repository structure
    [01 Description.kicad_sch, 03 Power.kicad_sch, 04 CAN.kicad_sch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]
2026-08-21 docs: update documentation and hardware files
    [01 Description.kicad_sch, 03 Power.kicad_sch, 04 CAN.kicad_sch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]
2026-09-18 docs: restore gimbal motor CAN protocol reference
